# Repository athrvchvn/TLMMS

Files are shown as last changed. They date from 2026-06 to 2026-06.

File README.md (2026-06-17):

# Machine Management System v2

RFID-based access control and machine usage management system for **Tinkerers' Lab, IIT Indore**.

MMS v2 lets lab administrators issue RFID cards to members, restrict machine access by permission level, log every session, and monitor all machines from a web dashboard — all with offline-capable hardware at each machine.

---

## System Overview

Four runtime components work together:

| Component | What it does |
|---|---|
| **ESP32 access node** | Mounted on each machine. Reads RFID cards, controls the relay, logs sessions. |
| **Raspberry Pi bridge** | Runs Mosquitto + `bridge.py`. Connects node MQTT traffic to Firebase. |
| **Card issuing kiosk** | Flask web app + Arduino RFID writer. Issues and encodes member cards. |
| **Web admin dashboard** | React/Vite PWA. Manages users, machines, permissions, and audit logs. |

Firebase stores system state (Firestore + RTDB). MQTT handles local node-to-bridge communication.

---

## Repository Structure

```
├── firmware/
│   ├── access_node/         ESP32 production firmware (Arduino/C++)
│   └── hardware_validation/ Standalone test sketches for each hardware module
│
├── apps/
│   ├── kiosk_station/       Flask card-issuing kiosk + RFID writer firmware
│   └── web_app/             React/Vite/Tailwind admin dashboard
│
├── services/
│   └── rpi_bridge/          Raspberry Pi MQTT↔Firebase bridge (Python)
│
├── firebase/
│   ├── firestore.rules      Firestore security rules
│   ├── firestore.indexes.json  Composite index definitions
│   └── database.rules.json  Realtime Database security rules
│
├── docs/
│   ├── deployment/          Step-by-step deployment and maintenance handbook (17 docs)
│   └── handbook/            LaTeX source for the formal project handbook (v2.1)
│
├── scripts/
│   └── seed_machines.py     Seeds the machine registry into Firestore
│
└── archive/
    ├── v1/                  MMS v1 source, CAD files, docs, and media
    └── handbook_v2.0/       Earlier handbook version (LaTeX source)
```

---

## Quick Start

### Prerequisites

- Firebase project (Firestore + RTDB + Storage + Auth enabled)
- Raspberry Pi 4 or 3B+ with Ethernet
- ESP32 Dev Module per machine
- MFRC522 RFID reader per machine
- Node.js 18+ and Python 3.11+ on your laptop

### Deployment Order

Follow `docs/deployment/` in numbered order. Start here:

```
01 → Read executive overview
03 → Confirm bill of materials
08 → Set up Firebase
07 → Set up Raspberry Pi bridge
09 → Deploy web dashboard
10 → Set up card issuing kiosk
06 → Validate hardware on first node
11 → Flash and provision first ESP32 node
12 → Run integration tests
13 → Roll out to remaining machines
```

Full guide: [docs/deployment/README.md](docs/deployment/README.md)

---

## Component Guide

### `firmware/access_node/`

Production ESP32 firmware. Each machine gets one flashed node.

Key files:

| File | Purpose |
|---|---|
| `access_node.ino` | Main sketch entry point |
| `config.h` | Machine ID, name, pin assignments — edit per node |
| `secrets.h.template` | Copy to `secrets.h` and fill in WiFi/MQTT/master key |
| `state_machine.*` | Node state transitions |
| `rfid_handler.*` | Card read and CRYPTO1 validation |
| `relay_controller.*` | Machine power relay control |
| `session_manager.*` | Session lifecycle (start, extend, end) |
| `mqtt_client.*` | MQTT pub/sub layer |
| `revocation_cache.*` | Local cache of revoked cards (offline-safe) |
| `littlefs_logger.*` | On-device log storage |
| `ota_handler.*` | Over-the-air firmware update support |

**Setup:** copy `secrets.h.template` → `secrets.h`, fill in values. The real `secrets.h` is gitignored and must never be committed.

### `firmware/hardware_validation/`

12 standalone Arduino sketches — one per hardware module. Run these in order on every freshly assembled node before flashing production firmware.

```
01_esp32_system    02_mfrc522        03_hc89_slot_sensor
04_oled64_spi      05_oled32_i2c     06_relay_mechanical
07_relay_ssr       08_ws2812_led     09_rotary_encoder
10_wifi            11_mqtt           12_littlefs
```

See [firmware/hardware_validation/EXECUTION_PLAN.md](firmware/hardware_validation/EXECUTION_PLAN.md) for the sign-off checklist.

### `services/rpi_bridge/`

Python service on the Raspberry Pi. Bridges local MQTT from ESP32 nodes to Firebase (Firestore sessions, RTDB machine status, command delivery).

```sh
cd services/rpi_bridge
cp .env.template .env          # fill in Firebase project ID, MQTT creds
pip install -r requirements.txt
python bridge.py
# or install as a systemd service via mms-bridge.service
```

### `apps/kiosk_station/`

Flask web app for issuing RFID cards at the lab front desk. Talks to Firebase to look up members and write CRYPTO1-encoded card payloads via a connected RFID writer.

```sh
cd apps/kiosk_station
cp secrets.py.template secrets.py   # fill in master key
pip install -r requirements.txt
python app.py
```

The `station_writer/` subfolder contains Arduino firmware for the RFID writer attached to the kiosk PC.

**The master key in `kiosk_station/secrets.py` must exactly match the one in every `access_node/secrets.h`. A mismatch means issued cards will not validate on nodes.**

### `apps/web_app/`

React/Vite admin dashboard. Supports user management, machine management, permission grants, session audit logs, and real-time status monitoring. Built as a PWA.

```sh
cd apps/web_app
npm install
npm run dev       # development server
npm run build     # production build → dist/
```

### `firebase/`

Firebase security rules and index definitions. Deploy from the repo root:

```sh
firebase deploy --only firestore:rules
firebase deploy --only firestore:indexes
firebase deploy --only database
```

### `docs/deployment/`

Complete operational runbook — 17 documents covering every deployment step from hardware assembly to disaster recovery. Written for a junior engineer with no prior MMS experience.

### `scripts/`

```sh
python scripts/seed_machines.py    # populate Firestore machines collection
```

---

## Secrets Reference

Never commit real secrets. Use the provided templates:

| Template | Copy to | Who reads it |
|---|---|---|
| `firmware/access_node/secrets.h.template` | `firmware/access_node/secrets.h` | ESP32 nodes |
| `apps/kiosk_station/secrets.py.template` | `apps/kiosk_station/secrets.py` | Kiosk app |
| `apps/kiosk_station/station_writer/secrets_station.h.template` | `…/secrets_station.h` | RFID writer firmware |
| `services/rpi_bridge/.env.template` | `services/rpi_bridge/.env` | Bridge service |

All three locations that use the master key must have **identical** values:
1. `firmware/access_node/secrets.h` — `MASTER_KEY`
2. `apps/kiosk_station/secrets.py` — `MASTER_KEY`
3. `apps/kiosk_station/station_writer/secrets_station.h` — `MASTER_KEY`

Pre-push checklist:

```sh
git status
git ls-files | grep -E 'secrets|service-account|\.env$'
```

---

## Archive

`archive/v1/` — MMS v1 access node code, kiosk app, CAD enclosure files, and media. Historical reference only; do not develop here.

`archive/handbook_v2.0/` — Earlier LaTeX handbook source.

---

## Tech Stack

| Layer | Technology |
|---|---|
| Node firmware | Arduino/C++ on ESP32 |
| RFID protocol | MFRC522 with MIFARE CRYPTO1 |
| Local messaging | MQTT (Mosquitto on Raspberry Pi) |
| Bridge service | Python 3, paho-mqtt, firebase-admin |
| Cloud backend | Firebase (Firestore, RTDB, Auth, Storage) |
| Web dashboard | React 18, Vite, TypeScript, Tailwind CSS, shadcn/ui |
| Card kiosk | Flask, Python |

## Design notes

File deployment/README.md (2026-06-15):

# MMS V2 — Deployment Package Index

**Machine Management System Version 2**
Tinkerers' Lab, IIT Indore

---

## Who This Package Is For

This package is written for a junior engineer who has never seen MMS before. You need:
- Basic Arduino IDE experience (upload a sketch, open Serial Monitor)
- Basic Raspberry Pi Linux experience (SSH, install packages, edit files)
- Basic web development experience (edit `.env` files, run `npm` commands)

You do **not** need to understand the full codebase. Each handbook is self-contained.

---

## Document Map

| # | Document | When You Need It |
|---|---|---|
| [01](01_executive_overview.md) | Executive Overview | Before anything — read first |
| [02](02_system_architecture.md) | System Architecture | When you need to understand how pieces connect |
| [03](03_bill_of_materials.md) | Bill of Materials | Before ordering hardware |
| [04](04_machine_registry.md) | Machine Registry | Before flashing any node |
| [05](05_hardware_assembly.md) | Hardware Assembly | Before validating hardware |
| [06](06_hardware_validation.md) | Hardware Validation | After assembly, before integration |
| [07](07_raspberry_pi_deployment.md) | Raspberry Pi Deployment | Setting up the RPi bridge |
| [08](08_firebase_deployment.md) | Firebase Deployment | Setting up cloud backend |
| [09](09_web_application_deployment.md) | Web Application Deployment | Deploying the admin dashboard |
| [10](10_card_issuing_station.md) | Card Issuing Station | Setting up the kiosk |
| [11](11_access_node_provisioning.md) | Access Node Provisioning | Flashing and configuring each ESP32 node |
| [12](12_integration_testing.md) | Integration Testing | Verifying everything works together |
| [13](13_production_rollout.md) | Production Rollout Plan | Staged deployment to all machines |
| [14](14_maintenance_handbook.md) | Maintenance Handbook | Ongoing operation |
| [15](15_troubleshooting_guide.md) | Troubleshooting Guide | When something breaks |
| [16](16_disaster_recovery.md) | Disaster Recovery | When something fails catastrophically |
| [17](17_future_expansion.md) | Future Expansion | Adding machines, features |

---

## First-Time Deployment Order

Follow this order exactly. Do not skip steps.

```
Step 1  Read Executive Overview (01)
Step 2  Confirm BOM and procure hardware (03)
Step 3  Set machine registry (04)
Step 4  Set up Firebase (08) ← requires Google account
Step 5  Set up Raspberry Pi (07)
Step 6  Deploy web application (09)
Step 7  Set up card issuing station (10)
Step 8  Assemble first node hardware (05)
Step 9  Validate first node hardware (06)
Step 10 Provision first node (11)
Step 11 Run integration test on first node (12)
Step 12 Pilot deployment — 1 machine (13)
Step 13 Expand to 5 machines (13)
Step 14 Full rollout — 15 machines (13)
```

---

## Critical Files In The Repository

```
v2/
├── access_node/            ← ESP32 firmware source
│   ├── config.h            ← Machine ID, name, pin assignments (edit per node)
│   ├── secrets.h           ← WiFi, MQTT, master key (NEVER commit, gitignored)
│   └── secrets.h.template  ← Copy this to secrets.h and fill in values
├── rpi_bridge/
│   ├── bridge.py           ← Main bridge service
│   ├── .env.template       ← Copy to .env and fill in values
│   └── mms-bridge.service  ← systemd unit file
├── kiosk_station/
│   ├── app.py              ← Flask kiosk application
│   ├── secrets.py          ← Master key (NEVER commit, gitignored)
│   ├── secrets.py.template ← Copy this to secrets.py
│   └── station_writer/     ← Arduino firmware for RFID writer
├── scripts/
│   └── seed_machines.py    ← One-time Firestore population
├── firestore.rules         ← Firestore security rules
├── database.rules.json     ← RTDB security rules
├── firestore.indexes.json  ← Required composite indexes
└── web_app/                ← React admin dashboard
```

---

## Quick Reference — Secrets Locations

| Secret | File | Who Uses It |
|---|---|---|
| WiFi SSID/Password | `access_node/secrets.h` | Each ESP32 node |
| MQTT credentials | `access_node/secrets.h` | Each ESP32 node |
| 32-byte master key | `access_node/secrets.h` | Each ESP32 node |
| 32-byte master key | `kiosk_station/secrets.py` | Python kiosk app |
| 32-byte master key | `kiosk_station/station_writer/secrets_station.h` | Card writer firmware |
| Firebase service account | `rpi_bridge/service-account.json` | Bridge |
| Firebase env vars | `web_app/lab-access-nexus-main/.env` | Web app |

**The master key must be identical in all three locations. A mismatch means cards issued by the kiosk cannot be read by the nodes.**

---

## Emergency Contacts / Escalation

> Fill in before deployment:
> - Lead engineer: ___________________
> - Firebase project ID: ___________________
> - RPi static IP: ___________________
> - WiFi SSID: ___________________

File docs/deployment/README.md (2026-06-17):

# MMS V2 — Deployment Package Index

**Machine Management System Version 2**
Tinkerers' Lab, IIT Indore

---

## Who This Package Is For

This package is written for a junior engineer who has never seen MMS before. You need:
- Basic Arduino IDE experience (upload a sketch, open Serial Monitor)
- Basic Raspberry Pi Linux experience (SSH, install packages, edit files)
- Basic web development experience (edit `.env` files, run `npm` commands)

You do **not** need to understand the full codebase. Each handbook is self-contained.

---

## Document Map

| # | Document | When You Need It |
|---|---|---|
| [01](01_executive_overview.md) | Executive Overview | Before anything — read first |
| [02](02_system_architecture.md) | System Architecture | When you need to understand how pieces connect |
| [03](03_bill_of_materials.md) | Bill of Materials | Before ordering hardware |
| [04](04_machine_registry.md) | Machine Registry | Before flashing any node |
| [05](05_hardware_assembly.md) | Hardware Assembly | Before validating hardware |
| [06](06_hardware_validation.md) | Hardware Validation | After assembly, before integration |
| [07](07_raspberry_pi_deployment.md) | Raspberry Pi Deployment | Setting up the RPi bridge |
| [08](08_firebase_deployment.md) | Firebase Deployment | Setting up cloud backend |
| [09](09_web_application_deployment.md) | Web Application Deployment | Deploying the admin dashboard |
| [10](10_card_issuing_station.md) | Card Issuing Station | Setting up the kiosk |
| [11](11_access_node_provisioning.md) | Access Node Provisioning | Flashing and configuring each ESP32 node |
| [12](12_integration_testing.md) | Integration Testing | Verifying everything works together |
| [13](13_production_rollout.md) | Production Rollout Plan | Staged deployment to all machines |
| [14](14_maintenance_handbook.md) | Maintenance Handbook | Ongoing operation |
| [15](15_troubleshooting_guide.md) | Troubleshooting Guide | When something breaks |
| [16](16_disaster_recovery.md) | Disaster Recovery | When something fails catastrophically |
| [17](17_future_expansion.md) | Future Expansion | Adding machines, features |

---

## First-Time Deployment Order

Follow this order exactly. Do not skip steps.

```
Step 1  Read Executive Overview (01)
Step 2  Confirm BOM and procure hardware (03)
Step 3  Set machine registry (04)
Step 4  Set up Firebase (08) ← requires Google account
Step 5  Set up Raspberry Pi (07)
Step 6  Deploy web application (09)
Step 7  Set up card issuing station (10)
Step 8  Assemble first node hardware (05)
Step 9  Validate first node hardware (06)
Step 10 Provision first node (11)
Step 11 Run integration test on first node (12)
Step 12 Pilot deployment — 1 machine (13)
Step 13 Expand to 5 machines (13)
Step 14 Full rollout — 15 machines (13)
```

---

## Critical Files In The Repository

```
firmware/
├── access_node/            ← ESP32 firmware source
│   ├── config.h            ← Machine ID, name, pin assignments (edit per node)
│   ├── secrets.h           ← WiFi, MQTT, master key (NEVER commit, gitignored)
│   └── secrets.h.template  ← Copy this to secrets.h and fill in values
└── hardware_validation/    ← Standalone test sketches (run before provisioning)

services/
└── rpi_bridge/
    ├── bridge.py           ← Main bridge service
    ├── .env.template       ← Copy to .env and fill in values
    └── mms-bridge.service  ← systemd unit file

apps/
├── kiosk_station/
│   ├── app.py              ← Flask kiosk application
│   ├── secrets.py          ← Master key (NEVER commit, gitignored)
│   ├── secrets.py.template ← Copy this to secrets.py
│   └── station_writer/     ← Arduino firmware for RFID writer
└── web_app/                ← React admin dashboard

firebase/
├── firestore.rules         ← Firestore security rules
├── database.rules.json     ← RTDB security rules
└── firestore.indexes.json  ← Required composite indexes

scripts/
└── seed_machines.py        ← One-time Firestore population
```

---

## Quick Reference — Secrets Locations

| Secret | File | Who Uses It |
|---|---|---|
| WiFi SSID/Password | `firmware/access_node/secrets.h` | Each ESP32 node |
| MQTT credentials | `firmware/access_node/secrets.h` | Each ESP32 node |
| 32-byte master key | `firmware/access_node/secrets.h` | Each ESP32 node |
| 32-byte master key | `apps/kiosk_station/secrets.py` | Python kiosk app |
| 32-byte master key | `apps/kiosk_station/station_writer/secrets_station.h` | Card writer firmware |
| Firebase service account | `services/rpi_bridge/service-account.json` | Bridge |
| Firebase env vars | `apps/web_app/.env` | Web app |

**The master key must be identical in all three locations. A mismatch means cards issued by the kiosk cannot be read by the nodes.**

---

## Emergency Contacts / Escalation

> Fill in before deployment:
> - Lead engineer: ___________________
> - Firebase project ID: ___________________
> - RPi static IP: ___________________
> - WiFi SSID: ___________________

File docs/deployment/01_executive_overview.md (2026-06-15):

# Section 01 — Executive Overview

→ Next: [System Architecture](02_system_architecture.md)

---

## What Is MMS V2?

MMS (Machine Management System) Version 2 is an RFID-based access control and session logging system for the Tinkerers' Lab at IIT Indore. It controls which students can use which lab machines, records how long each machine was used and by whom, and allows lab administrators to manage access remotely through a web dashboard.

**In practical terms:** A student walks up to a machine (e.g., the Creality 3D Printer). They insert their RFID card into the slot. The machine reads the card, verifies the student is authorised to use that specific machine, and if authorised, turns on the power relay to the machine. The student uses the machine. When done, they remove the card and the relay switches off. The session is recorded in Firebase and is visible on the admin dashboard.

---

## Why MMS V2 Exists — V1 Failures

V1 was an earlier system that **couldn't worked end-to-end**. The system had systemic issues that prevented deployment:

| V1 Problem | Impact |
|---|---|
|
| PINs stored as plaintext in Firebase | Security vulnerability |
| Non-unique MQTT client IDs | Multiple nodes disconnected each other |
| No watchdog timer | Firmware lockup required manual reset |
| No OTA update mechanism | Every firmware change required physical access |
| Blocking `delay()` calls in main loop | System unresponsive during delays |
| No offline fallback | WiFi outage = system offline |
| No security rules on Firebase | Any device on the internet could read/write all data |

V2 is a ground-up redesign that addresses every V1 failure.

---

## V2 Key Improvements

| Feature | V1 | V2 |
|---|---|---|
| RFID card schema | Block 1+2 (default sector key) | Sector 1, blocks 4+5, HMAC-SHA256 derived key per card |
| Access decision | Network call required | Fully local on ESP32 — works offline |
| Session logging | Never reached Firestore | LittleFS buffer → MQTT → Firebase bridge |
| Offline operation | System offline | Continues granting/denying access; logs buffered |
| Firmware updates | Physical access required | OTA via Firebase Storage URL |
| Watchdog | None | 30-second hardware watchdog timer |
| Security | No Firestore rules; plaintext PINs | Full security rules; HMAC-SHA256 PIN hash |
| Remote control | None | Admin can stop a session or disable a machine from the web |
| Machine configuration | Hardcoded in firmware | Pushed via MQTT retained messages from Firebase |

---

## System Capabilities

### What the system can do
- Grant or deny machine access based on RFID card permissions
- Log session start, end, duration, and reason to Firebase
- Support up to 32 machines (uint32 permission bitmask per card)
- Operate fully offline if WiFi/MQTT is unavailable
- Buffer offline session logs and upload when connectivity restores
- Push firmware updates to all nodes simultaneously (OTA)
- Allow an admin to remotely stop an active session
- Allow an admin to remotely disable a machine (denies all access)
- Revoke a lost or stolen card within seconds of admin action
- Push configuration changes (session limits, machine names) live to nodes
- Show real-time machine status on the admin web dashboard

### What the system cannot do (V2 scope)
- PIN verification at the machine (deferred to Phase 4 — rotary encoder not yet installed)
- Machine reservation/booking
- Multi-lab deployment (each lab needs its own Firebase project)
- 5 GHz WiFi (ESP32 is 2.4 GHz only)

---

## Architecture Summary

```
┌─────────────────────────────────────────────────────────────────┐
│                    RFID CARD (MIFARE Classic 1K)                │
│  Carries: Roll number, permissions bitmask, PIN hash            │
│  Secured by: Per-card HMAC-SHA256 sector key                    │
└───────────────────────────┬─────────────────────────────────────┘
                            │ Physical insertion into slot
                            ▼
┌─────────────────────────────────────────────────────────────────┐
│                  ESP32 ACCESS NODE (per machine)                │
│  Reads card → checks permissions → controls relay               │
│  Logs session to LittleFS → publishes to MQTT                   │
│  Updates two OLEDs + WS2812 LED                                 │
└───────────────────────────┬─────────────────────────────────────┘
                            │ MQTT over LAN (port 1883)
                            ▼
┌─────────────────────────────────────────────────────────────────┐
│               RASPBERRY PI (static IP on lab LAN)              │
│  Runs: Mosquitto MQTT broker + bridge.py service                │
│  Bridge: routes MQTT ↔ Firebase (Firestore + RTDB)             │
└────────────────┬──────────────────────────────────┬────────────┘
                 │ Firebase Admin SDK               │ Admin SDK
                 ▼                                  ▼
┌─────────────────────────┐        ┌────────────────────────────┐
│  FIRESTORE              │        │  REALTIME DATABASE (RTDB)  │
│  /sessions              │        │  /mms/nodes/{id}  (status) │
│  /users                 │        │  /mms/commands/{id}        │
│  /machines              │        │  /mms/ota                  │
│  /revoked               │        │  /mms/revoked              │
└─────────────────────────┘        └────────────────────────────┘
                 │                                  │
                 └──────────────┬───────────────────┘
                                │ Firebase JS SDK
                                ▼
┌─────────────────────────────────────────────────────────────────┐
│               REACT WEB APPLICATION (Firebase Hosting)          │
│  Admin dashboard: real-time status, session logs, user mgmt     │
│  Super admin: OTA trigger, machine enable/disable, revocation  │
└─────────────────────────────────────────────────────────────────┘
```

---

## Deployment Scale Assumptions

This deployment package assumes:
- **10–15 machines** in a single lab
- **~300 users** (students with RFID cards)
- **1 Raspberry Pi** serving as both MQTT broker and Firebase bridge
- **1 WiFi access point** covering the lab (2.4 GHz, SSID: `tlmms`)
- **1 Firebase project** (Spark/Blaze plan — see Section 8 for cost)
- **1 card issuing station** (kiosk) at the lab entrance
- Machines operate in a single physical location — no multi-site deployment

If these assumptions change (e.g., 2 labs, >32 machines, >1 AP), see [Section 17 — Future Expansion](17_future_expansion.md).

---

## Terminology Glossary

| Term | Meaning |
|---|---|
| Access node | The ESP32 + peripherals mounted at each machine |
| Bridge | The Python service on the RPi that connects MQTT to Firebase |
| Card / RFID card | MIFARE Classic 1K card issued to each student |
| Kiosk | The card issuing station (RPi or laptop + MFRC522 + Flask web UI) |
| Machine ID | Integer 1–32 identifying a specific lab machine |
| Master key | 32-byte secret known to kiosk and all nodes; used for HMAC key derivation |
| MQTT | Lightweight message protocol used for LAN communication |
| Node | Short for "access node" |
| OTA | Over-the-air firmware update |
| Permission bitmask | 32-bit integer on the card; bit N-1 = permission for machine N |
| Sector key | 6-byte key derived per-card by HMAC-SHA256(master_key, card_UID) |
| Session | A single machine-use event: card inserted → card removed or timeout |
| RTDB | Firebase Realtime Database |
| Roll number | Student identifier (9-digit string, e.g., "220002123") |

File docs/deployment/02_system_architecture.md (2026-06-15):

# Section 02 — System Architecture

← [Executive Overview](01_executive_overview.md) | → [Bill of Materials](03_bill_of_materials.md)

---

## Overall Architecture

```
╔══════════════════════════════════════════════════════════════════════╗
║                        LAB NETWORK (2.4 GHz WiFi)                    ║
║                                                                      ║
║  ┌──────────┐  ┌──────────┐  ┌──────────┐     ┌──────────┐           ║
║  │ Node 1   │  │ Node 2   │  │ Node 3   │ ... │ Node 15  │           ║
║  │Creality  │  │ Laser    │  │Soldering │     │ Grinder  │           ║
║  └────┬─────┘  └────┬─────┘  └────┬─────┘     └────┬─────┘           ║
║       │              │              │                │               ║
║       └──────────────┴──────────────┴────────────────┘               ║
║                                 │ MQTT port 1883                     ║
║                                 ▼                                    ║
║              ┌─────────────────────────────────────┐                 ║
║              │  Raspberry Pi (192.168.0.10 static) │                 ║
║              │  ├── Mosquitto MQTT broker          │                 ║
║              │  └── bridge.py (systemd service)    │                 ║
║              └───────────────────┬─────────────────┘                 ║
╚══════════════════════════════════╪═══════════════════════════════════╝
                                   │ HTTPS / Firebase Admin SDK
                                   ▼
            ╔══════════════════════════════════════════╗
            ║         FIREBASE (Google Cloud)           ║
            ║  ┌──────────────────────────────────┐    ║
            ║  │ Firestore                         │    ║
            ║  │  /users /machines /sessions       │    ║
            ║  │  /revoked /admins /super_admins   │    ║
            ║  └──────────────────────────────────┘    ║
            ║  ┌──────────────────────────────────┐    ║
            ║  │ Realtime Database (RTDB)          │    ║
            ║  │  /mms/nodes /mms/commands         │    ║
            ║  │  /mms/ota   /mms/revoked          │    ║
            ║  └──────────────────────────────────┘    ║
            ║  ┌──────────────────────────────────┐    ║
            ║  │ Storage (OTA firmware binaries)   │    ║
            ║  └──────────────────────────────────┘    ║
            ╚══════════════════════╦═══════════════════╝
                                   ║ Firebase JS SDK
                                   ▼
            ╔══════════════════════════════════════════╗
            ║     REACT WEB APP (Firebase Hosting)     ║
            ║  Admin dashboard + super admin panel     ║
            ╚══════════════════════════════════════════╝
```

---

## Access Node Architecture

Each physical machine has one access node. The node is self-contained — it can grant or deny access even with no network connection.

```
                     ┌────────────────────────────────────────┐
                     │           ESP32 NodeMCU 38-pin          │
                     │                                        │
  HC89 Slot          │ GPIO 32 ◄── Card present/absent        │
  Sensor ────────────┤                                        │
                     │ GPIO 5  ◄── MFRC522 SS (SPI)          │
  MFRC522            │ GPIO 27 ◄── MFRC522 RST               │
  RFID ──────────────┤ GPIO 18 ◄── SPI SCK (shared)          │
                     │ GPIO 19 ◄── SPI MISO (shared)         │
                     │ GPIO 23 ◄── SPI MOSI (shared)         │
                     │                                        │
  128×64 OLED        │ GPIO 17 ──► OLED DC                   │
  SPI ───────────────┤ GPIO 16 ──► OLED CS                   │
                     │ GPIO 4  ──► OLED RST                   │
                     │ GPIO 18/23 shared with RFID            │
                     │                                        │
  128×32 OLED        │ GPIO 21 ◄► I2C SDA                    │
  I2C ───────────────┤ GPIO 22 ──► I2C SCL                   │
                     │                                        │
  Relay / SSR ───────┤ GPIO 26 ──► Relay IN                  │
                     │                                        │
  WS2812 LED ────────┤ GPIO 33 ──► LED DIN (via 470Ω)        │
                     │                                        │
  Rotary Encoder     │ GPIO 34 ◄── CLK (ext. pull-up)        │
  (Phase 4) ─────────┤ GPIO 35 ◄── DT  (ext. pull-up)        │
                     │ GPIO 25 ◄── SW  (internal pull-up)     │
                     │                                        │
                     │ GPIO 2  ──► Onboard LED (WiFi status)  │
                     └────────────────────────────────────────┘
```

---

## Firmware State Machine

The ESP32 firmware runs a state machine. Understanding this helps diagnose what a node is doing at any moment.

```
                    Power on
                       │
                       ▼
                ┌─────────────┐
                │    BOOT     │ Init hardware, WiFi, MQTT, NVS
                └──────┬──────┘
                       │ Setup complete
                       ▼
              ┌────────────────┐
         ┌────►     IDLE       │◄────────────────────────────────┐
         │    │                │  OLED: "Tap card to start"      │
         │    └───────┬────────┘  LED: white breathing           │
         │            │ HC89: card detected                       │
         │            ▼                                           │
         │    ┌────────────────┐                                  │
         │    │ CARD_READING   │  OLED: spinner                  │
         │    └───────┬────────┘  LED: cyan flash                 │
         │            │                                           │
         │    ┌───────┴────────────────────────────┐             │
         │    │ Read result                        │             │
         │    ▼                                    ▼             │
         │  GRANTED                           DENIED             │
         │    │                          ┌────────────────┐      │
         │    │                          │ ACCESS_DENIED  │──────┘
         │    │                          │ (3s timeout)   │
         │    ▼                          └────────────────┘
         │  ┌─────────────────┐
         │  │ SESSION_ACTIVE  │  Relay ON, OLED: timer
         │  └────────┬────────┘  LED: solid green
         │           │
         │    ┌──────┴──────────────────┐
         │    │                         │
         │ card removed          2 min before limit
         │    │                         │
         │    │              ┌──────────────────────┐
         │    │              │  TIMEOUT_WARNING      │
         │    │              │  LED: yellow↔orange   │
         │    │              └──────────┬────────────┘
         │    │                    limit hit
         │    │                         │
         │    ▼                         ▼
         │  ┌─────────────────────────────────────┐
         │  │         SESSION_ENDED               │  Relay OFF
         │  │  Log event → MQTT → LittleFS        │  LED: off
         │  └───────────────┬─────────────────────┘
         │                  │ 3s
         └──────────────────┘

Any state + MQTT "stop"  → SESSION_ENDED
Any state + MQTT "ota"   → OTA_UPDATE (relay OFF first)
Any state + watchdog     → Hardware reset → BOOT
```

---

## MQTT Communication Architecture

### Topic map

| Topic | Direction | QoS | Retained | Payload |
|---|---|---|---|---|
| `mms/nodes/{id}/status` | Node → RPi | 1 | YES | `{state, roll, session_start, fw_version, ip, rssi}` |
| `mms/nodes/{id}/event` | Node → RPi | 1 | No | `{t, r, m, e, d, er}` |
| `mms/nodes/{id}/heartbeat` | Node → RPi | 0 | No | `{ts, heap_free, uptime_s}` |
| `mms/nodes/{id}/command` | RPi → Node | 1 | No | `{cmd, issued_by, ts}` |
| `mms/nodes/{id}/config` | RPi → Node | 1 | YES | `{name, session_limit_min, relay_active_high, machine_active}` |
| `mms/all/revoked` | RPi → All | 1 | YES | `{uids:["A1B2C3",...], updated_at:ts}` |
| `mms/bridge/status` | RPi → All | 1 | YES | `{state:"online"\|"offline"}` |

**Why retained messages matter:** When an ESP32 reboots and reconnects to MQTT, the broker immediately delivers the last retained `config` and `revoked` messages. The node gets its current configuration and revocation list without waiting for the admin to change anything. This is how offline-then-reconnect works seamlessly.

**Last Will Testament (LWT):** Each node sets a LWT before connecting. If it disconnects unexpectedly, the broker publishes `{"state":"offline"}` to `mms/nodes/{id}/status` (retained). The bridge sees this and the dashboard shows the node as offline.

### MQTT client IDs

Each client must have a unique ID. Duplicate IDs cause disconnection loops.

| Client | ID |
|---|---|
| Bridge | `bridge` |
| Node 1 | `mms_node_1` |
| Node 2 | `mms_node_2` |
| ... | ... |
| Node 15 | `mms_node_15` |

---

## Firebase Architecture

### Why two databases?

Firebase provides two real-time database products:
- **Firestore**: Document database optimised for complex queries, offline sync, and history. Used for permanent records (sessions, users, machines).
- **RTDB (Realtime Database)**: Simple JSON tree optimised for ultra-low latency live data. Used for real-time machine states, commands, and OTA triggers.

### Data flow: session event

```
ESP32 card removed
  → Session::end() called
  → Logger::appendSessionEnd() → /logs/sessions.jsonl (LittleFS)
  → MqttClient::publishEvent() → mms/nodes/3/event (MQTT QoS 1)
  → Bridge on_message() receives it
  → bridge.handle_node_event()
      → deduplication check (prevents duplicate on power-failure replay)
      → _fs_client.collection("sessions").add(session_data)   ← Firestore
      → _fs_client.collection("users").document(roll).update(last_seen)
  → Web app onSnapshot() triggers → dashboard updates
```

### Data flow: remote stop command

```
Admin clicks "Stop" in web app
  → setDoc(doc(rtdb, "/mms/commands/3"), {command:"stop", ts:now})
  → Bridge setup_rtdb_command_listener() fires
  → bridge checks: not stale (< 5 min), not acknowledged
  → mqtt_publish("mms/nodes/3/command", {cmd:"stop", ts:now}) QoS 1
  → Node MQTT callback receives it
  → processPendingCommand() in state_machine.cpp
  → Relay::off() → session ended → event published → RTDB cleared
```

### Data flow: OTA update

```
Super admin writes {firmware_url, target_version} to RTDB /mms/ota
  → Bridge setup_rtdb_ota_listener() fires
  → For each machine in Firestore /machines:
      → mqtt_publish("mms/nodes/{id}/command", {cmd:"ota", url, version})
  → Each node receives "ota" command
  → OTA::applyUpdate(url, version) called
  → esp_https_ota() downloads from Firebase Storage URL
  → On success: update NVS fw_version, ESP.restart()
  → If firmware crashes 3x on boot: rollback to previous partition
```

### Data flow: card revocation

```
Admin marks card as lost/stolen in web app
  → createDoc(doc(db, "revoked", uid), {reason:"lost"})
  → Bridge setup_firestore_revocation_listener() fires
  → Rebuild uid list from all /revoked docs
  → mqtt_publish("mms/all/revoked", {uids:[...], updated_at:ts}) retained
  → All connected nodes receive update → LittleFS /config/revoked.json updated
  → Next card tap with that UID: check → denied
```

---

## Access Control Architecture

The access decision is made entirely on the ESP32. No network call is needed.

```
Card inserted into slot
  ↓
HC89 slot sensor detects (GPIO 32 goes LOW)
  ↓
MFRC522 reads UID (SPI)
  ↓
Derive sector key:
  sector_key = HMAC-SHA256(master_key, uid_hex_uppercase)[0:6]
  (master_key is 32 bytes stored in NVS, never changes per deployment)
  ↓
Authenticate Sector 1, Block 7 with sector_key (MFRC522 MIFARE_Auth)
  ↓ (fails if card is from another system or was issued with wrong master key)
Read Block 4: roll_number[0:8] + schema_version[9]
Read Block 5: pin_hash[0:7] + perm_mask[8:11]
  ↓
Check 1: schema_version == 0x02 ?
  No → ACCESS DENIED ("Old card format")
  ↓
Check 2: uid in revocation list? (scan LittleFS /config/revoked.json)
  Yes → ACCESS DENIED ("Card revoked")
  ↓
Check 3: (perm_mask >> (MACHINE_ID - 1)) & 1 == 1 ?
  No → ACCESS DENIED ("No permission")
  ↓
Check 4: NVS::getMachineActive() == true ?
  No → ACCESS DENIED ("Machine disabled")
  ↓
ACCESS GRANTED → Relay::on()
```

**Key point:** This entire process takes ~200ms and requires zero network access. The node can grant access even if WiFi is completely down.

---

## Offline Operation Architecture

The system degrades gracefully during network failures:

```
WiFi or MQTT down
  ├── Access decisions: UNCHANGED (still fully functional)
  ├── Session logging: written to LittleFS /logs/sessions.jsonl
  ├── Revocation updates: cannot receive new revocations
  │     (last known list still enforced)
  ├── Config updates: cannot receive new session limits
  │     (NVS cached values used)
  └── Status display: 128×32 OLED shows "OFFLINE" indicator

WiFi or MQTT restored
  ├── LittleFS logger flushes buffered events to MQTT (QoS 1)
  ├── Broker delivers retained config + revoked messages
  ├── Node resumes publishing status + heartbeats
  └── Bridge processes buffered events into Firestore
```

**Offline capacity:** At 120 sessions/day average, LittleFS (1.5MB partition) holds approximately **5,000 session records** before rotation. Practically unlimited offline resilience for a lab.

---

## NVS (Non-Volatile Storage) Architecture

The ESP32 stores its configuration in NVS flash (survives reboots and power loss):

| NVS Key | Type | Set By | Description |
|---|---|---|---|
| `machine_id` | uint8 | Provisioning (config.h) | 1–32; fixed per node |
| `master_key` | blob 32B | Provisioning (secrets.h) | Shared secret for key derivation |
| `machine_name` | string | MQTT config push | Human-readable name |
| `session_limit` | uint16 | MQTT config push | Minutes; fallback to config.h |
| `relay_active_high` | uint8 | MQTT config push | Relay polarity |
| `machine_active` | uint8 | MQTT config push | 0 = admin-disabled |
| `fw_version` | string | OTA handler | Current firmware version |

Config pushed via MQTT is stored in NVS immediately, so it persists across reboots even if the node comes back up while the RPi is offline.

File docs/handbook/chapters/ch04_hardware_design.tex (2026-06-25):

%% Chapter 4 — Hardware Design
\chapter{Hardware Design}
\label{ch:hardware}

\section{ESP32 NodeMCU 38-pin}

The ESP32 NodeMCU (38-pin variant) is the central controller for each access node. Key specifications relevant to MMS V2:

\begin{itemize}[leftmargin=1.5em]
    \item Dual-core Xtensa LX6 at up to 240 MHz
    \item 520 KB SRAM; 4 MB flash
    \item Built-in 802.11 b/g/n WiFi (2.4 GHz only)
    \item 34 programmable GPIOs; some input-only
    \item Hardware SPI, I2C, UART peripherals
    \item \texttt{mbedTLS} cryptography library in ROM (provides HMAC-SHA256 without adding flash)
    \item Dual OTA flash partitions; watchdog timer
    \item 3.3V operating voltage; 5V tolerant on Vin pin
\end{itemize}

\begin{warnbox}
\textbf{GPIO 34--39 are INPUT ONLY.} They cannot be driven as outputs and have no internal pull-up resistors. In V1, the MFRC522 RST pin was connected to GPIO 34, which cannot be driven LOW --- the reset never worked. V2 moves RST to GPIO 27. The rotary encoder CLK (GPIO 34) and DT (GPIO 35) are correctly used as inputs with external 10k$\Omega$ pull-up resistors to 3.3V.
\end{warnbox}

\section{GPIO Pin Assignments}

\begin{table}[H]
\centering
\caption{ESP32 GPIO Assignments for MMS V2 Access Node}
\label{tab:gpio}
\begin{tabular}{C{2cm}L{4cm}C{2.5cm}L{2.5cm}L{3cm}}
\toprule
\textbf{GPIO} & \textbf{Signal} & \textbf{Direction} & \textbf{Pull resistor} & \textbf{Notes} \\
\midrule
5  & MFRC522 SS (SDA) & OUT & None & SPI chip select \\
18 & SPI SCK           & OUT & None & Shared: RFID + OLED64 \\
19 & SPI MISO          & IN  & None & Shared: RFID + OLED64 \\
23 & SPI MOSI          & OUT & None & Shared: RFID + OLED64 \\
27 & MFRC522 RST       & OUT & None & Active LOW reset \\
17 & OLED64 DC         & OUT & None & Data/Command select \\
16 & OLED64 CS         & OUT & None & SPI chip select \\
4  & OLED64 RST        & OUT & None & Active LOW reset \\
21 & OLED32 SDA        & BIDIR & Module 4.7k$\Omega$ & I2C data \\
22 & OLED32 SCL        & OUT & Module 4.7k$\Omega$ & I2C clock \\
26 & Relay IN          & OUT & None & LOW before \texttt{pinMode} \\
32 & HC89 slot sensor  & IN  & INPUT\_PULLUP & LOW = card present \\
33 & WS2812 DIN        & OUT & None & Via 470$\Omega$ resistor \\
36 & Current sensor IN & IN  & None & ADC1 CH0 (SVP); input-only; analog \\
34 & Encoder CLK       & IN  & EXT 10k$\Omega$ to 3V3 & Input-only; no internal pull-up \\
35 & Encoder DT        & IN  & EXT 10k$\Omega$ to 3V3 & Input-only; no internal pull-up \\
25 & Encoder SW        & IN  & INPUT\_PULLUP & Button press \\
2  & Onboard LED       & OUT & None & WiFi status indicator \\
\bottomrule
\end{tabular}
\end{table}

\section{Component Details}

\subsection{MFRC522 RFID Reader}

The MFRC522 is a 13.56 MHz RFID reader module compatible with MIFARE cards. In MMS V2 it is connected via SPI.

\begin{itemize}[leftmargin=1.5em]
    \item \textbf{Supply voltage}: 3.3V (NOT 5V --- module is not 5V tolerant)
    \item \textbf{SPI speed}: up to 10 MHz; MMS firmware uses 4 MHz for stability
    \item \textbf{Pin labelling}: the ``SDA'' pin on the module is the SPI chip select (SS), not I2C SDA --- this is a common source of confusion
    \item \textbf{IRQ pin}: not used in MMS V2; leave unconnected (NC)
    \item \textbf{Card detection}: firmware polls \texttt{MFRC522::PICC\_IsNewCardPresent()} rather than using the IRQ line
\end{itemize}

\subsection{SSD1306 128$\times$64 SPI OLED (Primary Display)}

This is the main user-facing display. It shows machine state, roll number, session timer, and status messages.

\begin{itemize}[leftmargin=1.5em]
    \item Controller: SSD1306
    \item Resolution: 128$\times$64 pixels, monochrome
    \item Interface: SPI (4-wire: SCK, MOSI, DC, CS) plus RST
    \item Supply: 3.3V
    \item Shared SPI bus with MFRC522; multiplexed via chip select pins
\end{itemize}

\subsection{SSD1306 128$\times$32 I2C OLED (Status Strip)}

This is the always-visible status display: WiFi/MQTT connectivity dots, machine name, NTP time.

\begin{itemize}[leftmargin=1.5em]
    \item Controller: SSD1306
    \item Resolution: 128$\times$32 pixels, monochrome
    \item Interface: I2C, address 0x3C
    \item Supply: 3.3V
    \item Module has onboard 4.7k$\Omega$ pull-ups on SDA and SCL --- no external resistors needed
\end{itemize}

\subsection{HC89 Optical IR Slot Sensor}

The HC89 is an infrared photointerrupter slot sensor that detects card insertion.

\begin{itemize}[leftmargin=1.5em]
    \item Slot width: \textasciitilde{}6mm (MIFARE card thickness: 0.76mm --- fits well)
    \item Output type: open-collector (active LOW when card blocks IR beam)
    \item Supply: 3.3V or 5V (check module datasheet --- most accept 3.3V)
    \item Configured as \texttt{INPUT\_PULLUP} on GPIO 32
    \item Firmware debounce: 50ms (ignores transitions shorter than 50ms)
    \item A card in the slot gives signal LOW; no card gives signal HIGH
\end{itemize}

\subsection{Relay Module (Mechanical or SSR)}

\subsubsection{Mechanical Relay}
\begin{itemize}[leftmargin=1.5em]
    \item Typical: SRD-05VDC-SL-C (5V coil, 10A 250V AC rated)
    \item Control: GPIO 26 via optocoupler on relay board
    \item Default active HIGH (\texttt{relay\_active\_high = true} in config)
    \item Relay board takes 5V on VCC; control signal from 3.3V GPIO is sufficient via optocoupler
\end{itemize}

\subsubsection{Solid-State Relay (SSR)}
Recommended for high-cycling loads (soldering station on/off frequently) and for the laser cutter (noise sensitivity).

\begin{itemize}[leftmargin=1.5em]
    \item Typical: SSR-25DA (3--32V DC control, 25A 380V AC load)
    \item Control: GPIO 26 (3.3V signal drives 3--32V DC input directly)
    \item Active HIGH (\texttt{relay\_active\_high = true})
    \item Heat sink required for loads above 10A
\end{itemize}

\begin{notebox}
The \texttt{relay\_active\_high} configuration is pushed from Firebase via MQTT to each node's NVS. This means the relay polarity can be changed remotely without reflashing. Set this value correctly in the Firestore \texttt{/machines/\{id\}} document when seeding.
\end{notebox}

\subsection{WS2812B RGB LED}

A single WS2812B LED provides colour-coded system state feedback.

\begin{itemize}[leftmargin=1.5em]
    \item Supply: 5V (directly from Vin --- NOT 3.3V)
    \item Data: GPIO 33 via 470$\Omega$ series resistor (protects against inductive spikes from long wire runs)
    \item 100$\mu$F electrolytic capacitor across VCC--GND at the LED (absorbs power-up surge)
    \item Colour order: \texttt{NEO\_GRB} (some clone modules use different order --- see Appendix~\ref{app:wiring})
\end{itemize}

\subsection{EC11 Rotary Encoder}

The EC11 rotary encoder is installed in the hardware but not yet used in production firmware (Phase 4 --- PIN entry at machine).

\begin{itemize}[leftmargin=1.5em]
    \item CLK on GPIO 34 (input-only) --- requires external 10k$\Omega$ pull-up to 3.3V
    \item DT on GPIO 35 (input-only) --- requires external 10k$\Omega$ pull-up to 3.3V
    \item SW (push button) on GPIO 25 --- uses internal \texttt{INPUT\_PULLUP}
\end{itemize}

\subsection{Power Supply}

Each node uses a HiLink HLK-PM01 (5V 1W AC-DC converter) to derive 5V from mains:

\begin{itemize}[leftmargin=1.5em]
    \item Input: 90--264V AC
    \item Output: 5V DC, 600mA
    \item The 5V feeds: ESP32 Vin, relay module VCC, WS2812 VCC
    \item The ESP32's internal LDO produces 3.3V for all other components
    \item A 5A fuse must be placed on the AC input before the HiLink
\end{itemize}

\begin{warnbox}
\textbf{Safety:} The HiLink operates at 240V AC. Treat it as a live shock hazard at all times. All AC wiring must be completed, routed through cable glands, and the enclosure must be closed before the node is powered from mains. Always test 5V DC circuitry with a USB power bank before connecting to mains.
\end{warnbox}

\section{Power Budget}

\begin{table}[H]
\centering
\caption{Node Power Consumption Estimate}
\begin{tabular}{L{5cm}C{3cm}C{3cm}}
\toprule
\textbf{Component} & \textbf{Typical (mA)} & \textbf{Peak (mA)} \\
\midrule
ESP32 (WiFi active, 240MHz) & 160 & 250 \\
MFRC522 & 13 & 26 \\
SSD1306 64px OLED & 20 & 25 \\
SSD1306 32px OLED & 15 & 20 \\
HC89 & 20 & 20 \\
WS2812B (1 LED, white full) & 60 & 60 \\
Relay coil (mechanical) & 70 & 70 \\
\midrule
\textbf{Total (peak)} & & \textbf{471 mA} \\
\midrule
HiLink HLK-PM01 capacity & & 600 mA \\
Margin & & 127 mA (21\%) \\
\bottomrule
\end{tabular}
\end{table}

\begin{notebox}
The power margin is adequate but not generous. Avoid adding components to the 5V rail beyond the designed BOM. If an SSR is added (replacing mechanical relay), remove the relay coil consumption --- SSRs consume \textasciitilde{}10mA on the control side.
\end{notebox}

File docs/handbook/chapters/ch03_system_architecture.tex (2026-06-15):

%% Chapter 3 — System Architecture
\chapter{System Architecture}
\label{ch:architecture}

\section{Architecture Overview}

MMS V2 uses a three-tier architecture:

\begin{enumerate}[leftmargin=1.5em]
    \item \textbf{Edge tier}: ESP32 access nodes. One per machine. Physical access control, session timing, display.
    \item \textbf{Local bridge tier}: Raspberry Pi running Mosquitto (MQTT broker) and \texttt{bridge.py}. Bridges the local MQTT network and Firebase.
    \item \textbf{Cloud tier}: Firebase (Firestore + RTDB + Storage + Hosting + Auth). Permanent storage, real-time state, web hosting.
\end{enumerate}

\begin{figure}[H]
\centering
\begin{tikzpicture}[node distance=11mm and 11mm]
\node[mmsedge] (n1) {ESP32 Node 1\\3D Printer};
\node[mmsedge, right=of n1] (n2) {ESP32 Node 2\\Laser Cutter};
\node[mmsedge, right=of n2] (n3) {ESP32 Node 3--5\\Soldering, Grinder};
\node[mmsblock, above=16mm of n2, text width=42mm] (rpi) {Raspberry Pi\\Mosquitto broker\\\texttt{bridge.py} systemd\\192.168.0.10};
\node[mmscloud, above=16mm of rpi, text width=48mm] (fb) {Firebase\\Firestore + RTDB\\Storage + Hosting + Auth};
\node[mmsblock, right=20mm of fb] (web) {React dashboard\\coordinators};
\node[mmsblock, left=20mm of rpi] (kiosk) {Kiosk station\\card issuer};
\draw[mmsline] (n1) -- node[left,font=\scriptsize]{MQTT/LAN} (rpi);
\draw[mmsline] (n2) -- (rpi);
\draw[mmsline] (n3) -- (rpi);
\draw[mmsline] (rpi) -- node[right,font=\scriptsize]{Admin SDK + REST} (fb);
\draw[mmsline] (web) -- node[above,font=\scriptsize]{HTTPS} (fb);
\draw[mmsdash] (kiosk) -- node[above,font=\scriptsize]{Firestore user data} (fb);
\draw[mmsdash] (kiosk) -- node[below,font=\scriptsize]{writes cards} (n1);
\end{tikzpicture}
\caption{MMS V2 System Architecture}
\label{fig:architecture}
\end{figure}

\section{C4-Style System Context}

\begin{figure}[H]
\centering
\begin{tikzpicture}[node distance=12mm and 15mm]
\node[mmsblock] (student) {Student\\RFID card};
\node[mmsblock, below=of student] (coord) {Coordinator\\dashboard};
\node[mmscloud, right=18mm of student, text width=43mm] (system) {MMS V2\\access control and usage logging};
\node[mmsedge, right=18mm of system] (machine) {Workshop machines\\relay controlled};
\node[mmscloud, below=of system] (firebase) {Firebase project\\identity, live state, records};
\draw[mmsline] (student) -- node[above,font=\scriptsize]{requests access} (system);
\draw[mmsline] (coord) -- node[below,font=\scriptsize]{admin commands} (system);
\draw[mmsline] (system) -- node[above,font=\scriptsize]{enables power} (machine);
\draw[mmsline] (system) -- node[right,font=\scriptsize]{logs/syncs} (firebase);
\draw[mmsline] (firebase) -- (coord);
\end{tikzpicture}
\caption{System context diagram}
\label{fig:system_context}
\end{figure}

\section{Communication Paths}

\subsection{Access Decision (Offline-capable)}

The access decision path requires no network:
\begin{enumerate}[leftmargin=1.5em]
    \item HC89 slot sensor detects card insertion
    \item MFRC522 reads card UID
    \item ESP32 derives sector key: $\text{HMAC-SHA256}(\text{master\_key},\, \text{uid\_hex})[0..5]$
    \item ESP32 authenticates Sector 1, reads Blocks 4 and 5
    \item ESP32 checks UID against LittleFS revocation list
    \item ESP32 checks permission bitmask: $(perm\_mask \gg (machine\_id - 1)) \& 1$
    \item If all checks pass: relay ON, session starts
\end{enumerate}

\begin{figure}[H]
\centering
\begin{tikzpicture}[node distance=8mm]
\node[state] (slot) {Card inserted};
\node[state, below=of slot] (read) {Read UID and Sector 1};
\node[decision, below=of read] (auth) {Auth\\OK?};
\node[decision, below left=11mm and 18mm of auth] (rev) {UID\\revoked?};
\node[decision, below right=11mm and 18mm of auth] (perm) {Permission\\bit set?};
\node[mmswarn, below=18mm of rev] (deny) {Deny access\\log reason};
\node[mmsedge, below=18mm of perm] (grant) {Relay ON\\start session};
\draw[mmsline] (slot) -- (read);
\draw[mmsline] (read) -- (auth);
\draw[mmsline] (auth) -- node[left,font=\scriptsize]{yes} (rev);
\draw[mmsline] (auth) -- node[right,font=\scriptsize]{yes} (perm);
\draw[mmsline] (auth.east) -- ++(18mm,0) |- node[pos=0.2,above,font=\scriptsize]{no} (deny.east);
\draw[mmsline] (rev) -- node[left,font=\scriptsize]{yes} (deny);
\draw[mmsline] (rev) -- node[above,font=\scriptsize]{no} (perm);
\draw[mmsline] (perm) -- node[right,font=\scriptsize]{yes} (grant);
\draw[mmsline] (perm) -- node[above,font=\scriptsize]{no} (deny);
\end{tikzpicture}
\caption{Offline access validation flow}
\label{fig:access_validation_flow}
\end{figure}

\subsection{Session Event Flow}

\begin{enumerate}[leftmargin=1.5em]
    \item Session ends (card removed, timeout, or remote stop)
    \item ESP32 builds JSON event: \texttt{\{ts, roll, machine\_id, event, duration\_s, end\_reason\}}
    \item If MQTT connected: publish to \texttt{mms/nodes/\{id\}/event} (QoS 1)
    \item If MQTT disconnected: append to LittleFS \texttt{/logs/sessions.jsonl}; publish on next connect
    \item bridge.py receives event via MQTT subscription
    \item bridge.py checks Firestore for duplicate (±5s deduplication window)
    \item bridge.py writes session to Firestore \texttt{/sessions} collection
    \item bridge.py updates \texttt{/users/\{roll\}/last\_seen}
\end{enumerate}

\begin{figure}[H]
\centering
\begin{tikzpicture}[node distance=8mm and 12mm]
\node[mmsedge] (esp) {ESP32\\session ends};
\node[mmsblock, right=of esp] (mqtt) {MQTT broker\\QoS 1};
\node[mmsblock, right=of mqtt] (bridge) {bridge.py\\deduplicate};
\node[mmscloud, right=of bridge] (fs) {Firestore\\\texttt{/sessions}};
\node[mmswarn, below=of mqtt] (fsbuf) {LittleFS\\offline buffer};
\draw[mmsline] (esp) -- node[above,font=\scriptsize]{online} (mqtt);
\draw[mmsline] (mqtt) -- (bridge);
\draw[mmsline] (bridge) -- (fs);
\draw[mmsdash] (esp) -- node[left,font=\scriptsize]{offline} (fsbuf);
\draw[mmsdash] (fsbuf) -- node[right,font=\scriptsize]{flush on reconnect} (mqtt);
\end{tikzpicture}
\caption{Session logging and offline sync path}
\label{fig:session_sync_flow}
\end{figure}

\subsection{Remote Stop Flow}

\begin{enumerate}[leftmargin=1.5em]
    \item Admin clicks Stop in web dashboard
    \item Web app writes to RTDB \texttt{/mms/commands/\{id\}}: \texttt{\{command:"stop", timestamp:now\}}
    \item bridge.py \texttt{onValue} listener triggers
    \item bridge.py checks command age: if $>$300s, discard and acknowledge
    \item bridge.py publishes to \texttt{mms/nodes/\{id\}/command} (QoS 1)
    \item ESP32 MQTT callback receives command
    \item ESP32 checks command timestamp: if $>$300s old, discard
    \item ESP32 turns relay OFF, logs end\_reason: \texttt{remote\_stop}
    \item ESP32 publishes session event; acknowledges command to RTDB
\end{enumerate}

\begin{figure}[H]
\centering
\begin{tikzpicture}[node distance=8mm and 10mm]
\node[mmsblock] (admin) {Admin clicks\\Stop};
\node[mmscloud, right=of admin] (rtdb) {RTDB command\\\texttt{/mms/commands/id}};
\node[mmsblock, right=of rtdb] (bridge) {bridge.py\\age check};
\node[mmsblock, right=of bridge] (mqtt) {MQTT command};
\node[mmsedge, right=of mqtt] (node) {ESP32\\relay OFF};
\node[mmscloud, below=of bridge] (ack) {RTDB ack\\session event};
\draw[mmsline] (admin) -- (rtdb);
\draw[mmsline] (rtdb) -- (bridge);
\draw[mmsline] (bridge) -- (mqtt);
\draw[mmsline] (mqtt) -- (node);
\draw[mmsline] (node) |- (ack);
\draw[mmsline] (ack) -| (admin);
\end{tikzpicture}
\caption{Remote stop command path}
\label{fig:remote_stop_flow}
\end{figure}

\subsection{Revocation Flow}

\begin{enumerate}[leftmargin=1.5em]
    \item Admin marks card as lost in web app
    \item Web app creates \texttt{/revoked/\{uid\}} in Firestore
    \item bridge.py Firestore \texttt{onSnapshot} triggers
    \item bridge.py rebuilds revocation list from all \texttt{/revoked} documents
    \item bridge.py publishes \texttt{mms/all/revoked} (retained, QoS 1): \texttt{\{uids:[...], updated\_at:ts\}}
    \item All connected nodes receive the update; update LittleFS \texttt{/config/revoked.json}
    \item On next card tap: UID checked against revocation list $\rightarrow$ denied
    \item Offline nodes: receive update on reconnect (retained message delivered automatically)
\end{enumerate}

\begin{figure}[H]
\centering
\begin{tikzpicture}[node distance=8mm and 12mm]
\node[mmsblock] (web) {Dashboard\\revoke card};
\node[mmscloud, right=of web] (revoked) {Firestore\\\texttt{/revoked/\{uid\}}};
\node[mmsblock, right=of revoked] (bridge) {bridge.py\\rebuild list};
\node[mmsblock, right=of bridge] (mqtt) {Retained MQTT\\\texttt{mms/all/revoked}};
\node[mmsedge, right=of mqtt] (node) {Nodes update\\LittleFS cache};
\draw[mmsline] (web) -- (revoked);
\draw[mmsline] (revoked) -- (bridge);
\draw[mmsline] (bridge) -- (mqtt);
\draw[mmsline] (mqtt) -- (node);
\end{tikzpicture}
\caption{Card revocation propagation}
\label{fig:revocation_flow}
\end{figure}

\subsection{OTA Update Flow}

\begin{enumerate}[leftmargin=1.5em]
    \item Super admin uploads \texttt{.bin} to Firebase Storage; copies download URL
    \item Super admin writes to RTDB \texttt{/mms/ota}: \texttt{\{firmware\_url, target\_version, released\_at\}}
    \item bridge.py RTDB OTA listener triggers
    \item bridge.py publishes OTA command to all nodes: \texttt{mms/nodes/+/command}
    \item ESP32 receives command; transitions to OTA state; relay OFF
    \item ESP32 calls \texttt{esp\_https\_ota()} with firmware URL
    \item On success: reboot to new partition; update NVS fw\_version
    \item On failure: if 3 crashes on new partition $\rightarrow$ rollback to previous partition
\end{enumerate}

\begin{figure}[H]
\centering
\begin{tikzpicture}[node distance=8mm and 9mm]
\node[mmsblock] (build) {Build\\\texttt{.bin}};
\node[mmscloud, right=of build] (storage) {Firebase Storage\\firmware URL};
\node[mmscloud, right=of storage] (ota) {RTDB\\\texttt{/mms/ota}};
\node[mmsblock, right=of ota] (bridge) {bridge.py\\publish command};
\node[mmsedge, below=of ota] (node) {ESP32 OTA\\download, verify, reboot};
\node[mmswarn, below=of node] (rollback) {Rollback if\\boot fails};
\draw[mmsline] (build) -- (storage);
\draw[mmsline] (storage) -- (ota);
\draw[mmsline] (ota) -- (bridge);
\draw[mmsline] (bridge) |- (node);
\draw[mmsdash] (node) -- (rollback);
\end{tikzpicture}
\caption{OTA release flow}
\label{fig:ota_flow}
\end{figure}

\section{MQTT Topic Map}

\begin{longtable}{L{5cm}L{2.5cm}C{1.5cm}C{1.5cm}L{4.5cm}}
\toprule
\textbf{Topic} & \textbf{Publisher} & \textbf{QoS} & \textbf{Retain} & \textbf{Payload} \\
\midrule
\endhead
\texttt{mms/nodes/\{id\}/status} & ESP32 & 1 & Yes & State, roll, session\_start, fw\_version, IP, RSSI \\
\texttt{mms/nodes/\{id\}/event} & ESP32 & 1 & No & Session event JSON \\
\texttt{mms/nodes/\{id\}/heartbeat} & ESP32 & 0 & No & \{ts, heap\_free, uptime\_s\} \\
\texttt{mms/nodes/\{id\}/command} & RPi bridge & 1 & No & \{cmd, issued\_by, ts\} \\
\texttt{mms/nodes/\{id\}/config} & RPi bridge & 1 & Yes & \{name, session\_limit, relay\_active\_high, machine\_active\} \\
\texttt{mms/all/revoked} & RPi bridge & 1 & Yes & \{uids:[...], updated\_at\} \\
\bottomrule
\caption{MQTT Topic Reference}
\label{tab:mqtt_topics}
\end{longtable}

\begin{notebox}
\textbf{Last Will and Testament (LWT):} Each ESP32 registers an LWT on \texttt{mms/nodes/\{id\}/status} with payload \texttt{\{"state":"offline"\}} (retained). If the node disconnects unexpectedly, the broker publishes this automatically. The bridge detects it and updates the RTDB node state to \texttt{"offline"}, which the dashboard reflects immediately.
\end{notebox}

\section{Offline Degradation Table}

\begin{table}[H]
\centering
\caption{System Behaviour When Components Are Unavailable}
\begin{tabular}{L{4cm}L{6cm}L{4.5cm}}
\toprule
\textbf{Unavailable component} & \textbf{Impact on access control} & \textbf{Impact on logging} \\
\midrule
WiFi (node disconnected) & No impact. Card access continues. & Sessions buffered in LittleFS; flushed on reconnect \\
Raspberry Pi down & No impact. Access decisions are local. & Sessions buffered; flushed when RPi recovers \\
Firebase down & No impact. & bridge.py buffers events in memory; written when Firebase recovers \\
RFID reader (hardware fault) & No card reads possible. Node logs error. & No sessions started. \\
Relay (hardware fault) & Machine may not respond to access grant. & Sessions still logged. \\
\bottomrule
\end{tabular}
\end{table}

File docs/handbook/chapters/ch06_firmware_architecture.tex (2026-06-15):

%% Chapter 6 — Firmware Architecture
\chapter{Firmware Architecture}
\label{ch:firmware}

\section{Firmware Structure}

The access node firmware is located in \texttt{v2/access\_node/}. It is organised as a collection of single-responsibility modules coordinated by a central state machine.

\begin{table}[H]
\centering
\caption{Firmware Module Map}
\label{tab:modules}
\begin{tabular}{L{4.5cm}L{4.5cm}L{5.5cm}}
\toprule
\textbf{Module} & \textbf{Files} & \textbf{Responsibility} \\
\midrule
Config & \texttt{config.h} & Machine ID, name, session limit, broker IP \\
Secrets & \texttt{secrets.h} & WiFi credentials, master key (gitignored) \\
NVS Manager & \texttt{nvs\_manager.h/.cpp} & Read/write NVS namespace \texttt{mms\_config} \\
RFID Handler & \texttt{rfid\_handler.h/.cpp} & MFRC522 SPI init; card detect; sector key derivation; block read \\
Card Schema & \texttt{card\_schema.h/.cpp} & Parse blocks 4+5; validate schema; return \texttt{CardData} struct \\
Access Control & \texttt{access\_control.h/.cpp} & Revocation list check + permission bitmask check \\
Relay Controller & \texttt{relay\_controller.h/.cpp} & GPIO abstraction; safe OFF on init \\
Slot Sensor & \texttt{slot\_sensor.h/.cpp} & HC89 debounced input \\
Session Manager & \texttt{session\_manager.h/.cpp} & Session start/end/timeout; build log entry JSON \\
MQTT Client & \texttt{mqtt\_client.h/.cpp} & PubSubClient wrapper; reconnect backoff; command callback \\
Revocation Cache & \texttt{revocation\_cache.h/.cpp} & LittleFS \texttt{/config/revoked.json}; UID lookup \\
LittleFS Logger & \texttt{littlefs\_logger.h/.cpp} & JSONL append; rotate at 50KB; flush on connect \\
Display Primary & \texttt{display\_primary.h/.cpp} & 128$\times$64 SPI OLED; state-driven rendering \\
Display Status & \texttt{display\_status.h/.cpp} & 128$\times$32 I2C OLED; persistent status strip \\
LED Controller & \texttt{led\_controller.h/.cpp} & WS2812; non-blocking animations \\
Watchdog & \texttt{watchdog.h/.cpp} & ESP32 TWDT; 30s timeout; feed in main loop \\
OTA Handler & \texttt{ota\_handler.h/.cpp} & Version check; \texttt{esp\_https\_ota}; rollback \\
State Machine & \texttt{state\_machine.h/.cpp} & Central FSM; drives all transitions \\
Main & \texttt{access\_node.ino} & \texttt{setup()} + \texttt{loop()}; watchdog feed \\
\bottomrule
\end{tabular}
\end{table}

\section{Firmware State Machine}

The state machine is the central coordinator. All hardware events and MQTT messages cause state transitions. No module changes hardware state directly --- all changes go through the state machine.

\begin{figure}[H]
\centering
\begin{tikzpicture}[node distance=8mm and 9mm]
\node[state] (boot) {BOOT};
\node[state, below=of boot] (idle) {IDLE};
\node[state, below=of idle] (read) {CARD\\READING};
\node[mmswarn, left=of read] (denied) {ACCESS\\DENIED};
\node[mmswarn, right=of read] (disabled) {MACHINE\\DISABLED};
\node[state, below=of read] (active) {SESSION\\ACTIVE};
\node[mmswarn, below left=of active] (warning) {TIMEOUT\\WARNING};
\node[mmswarn, below=of warning] (expired) {TIMEOUT\\EXPIRED};
\node[state, below=of active] (ended) {SESSION\\ENDED};
\node[state, right=of active] (ota) {OTA\\UPDATE};
\draw[mmsline] (boot) -- node[right,font=\scriptsize]{init hardware, WiFi, MQTT} (idle);
\draw[mmsline] (idle) -- node[right,font=\scriptsize]{HC89 card detected} (read);
\draw[mmsline] (read) -- node[above,font=\scriptsize]{auth/schema/permission fail} (denied);
\draw[mmsline] (read) -- node[above,font=\scriptsize]{machine inactive} (disabled);
\draw[mmsline] (read) -- node[right,font=\scriptsize]{permission OK, relay ON} (active);
\draw[mmsline] (active) -- node[left,font=\scriptsize]{limit - 2 min} (warning);
\draw[mmsline] (warning) -- node[left,font=\scriptsize]{limit reached} (expired);
\draw[mmsline] (expired) -| node[below,font=\scriptsize]{relay OFF} (ended);
\draw[mmsline] (active) -- node[right,font=\scriptsize]{card removed / stop} (ended);
\draw[mmsline] (ended.west) -- ++(-34mm,0) |- node[pos=0.15,below,font=\scriptsize]{after display timeout} (idle.west);
\draw[mmsdash] (denied) |- (idle);
\draw[mmsdash] (disabled) |- (idle);
\draw[mmsdash] (active) -- node[above,font=\scriptsize]{MQTT OTA} (ota);
\draw[mmsdash] (ota) |- (boot);
\end{tikzpicture}
\caption{Access Node Firmware State Machine}
\label{fig:state_machine}
\end{figure}

\section{NVS Configuration}

NVS (Non-Volatile Storage) persists configuration across reboots. The namespace is \texttt{mms\_config}.

\begin{table}[H]
\centering
\caption{NVS Configuration Keys}
\begin{tabular}{L{3.5cm}C{2.5cm}L{3cm}L{5cm}}
\toprule
\textbf{Key} & \textbf{Type} & \textbf{Set by} & \textbf{Description} \\
\midrule
\texttt{machine\_id}   & uint8   & \texttt{config.h} at flash & 1--32 \\
\texttt{master\_key}   & blob (32B) & \texttt{secrets.h} at flash & HMAC master secret \\
\texttt{machine\_name} & string (32) & MQTT config push & Display name; fallback to \texttt{config.h} \\
\texttt{session\_limit} & uint16 & MQTT config push & Minutes; fallback to \texttt{config.h} \\
\texttt{relay\_active\_high} & uint8 & MQTT config push & 1=HIGH activates relay; 0=LOW \\
\texttt{machine\_active} & uint8 & MQTT config push & 0=disabled; all access denied \\
\texttt{fw\_version}  & string & OTA handler & Current firmware version string \\
\bottomrule
\end{tabular}
\end{table}

On first boot (no NVS data), the firmware uses the fallback values from \texttt{config.h}. On the first MQTT connect, the bridge pushes the Firestore config, which overwrites NVS. On subsequent boots without MQTT connection, NVS values are used.

\section{LittleFS File Layout}

\begin{table}[H]
\centering
\caption{LittleFS file layout}
\begin{tabular}{L{5cm}L{9cm}}
\toprule
\textbf{Path} & \textbf{Purpose} \\
\midrule
\texttt{/logs/sessions.jsonl} & Append-only offline session event log. \\
\texttt{/logs/sessions.old.jsonl} & Previous rotation backup; overwritten by the next rotation. \\
\texttt{/config/revoked.json} & Cached revoked UID list with \texttt{updated\_at} timestamp. \\
\bottomrule
\end{tabular}
\end{table}

\textbf{Log rotation:} When \texttt{sessions.jsonl} exceeds 50KB:
\begin{enumerate}[leftmargin=1.5em]
    \item Rename \texttt{sessions.jsonl} $\rightarrow$ \texttt{sessions.old.jsonl} (overwrites previous)
    \item Create new empty \texttt{sessions.jsonl}
    \item Continue appending
\end{enumerate}

\textbf{Flush on MQTT connect:}
\begin{enumerate}[leftmargin=1.5em]
    \item Open \texttt{sessions.jsonl}
    \item Read line by line; attempt JSON parse each line
    \item Discard any line that fails to parse (partial write from power loss)
    \item Publish each valid line to \texttt{mms/nodes/\{id\}/event} (QoS 1)
    \item Wait for broker ACK before publishing next
    \item After all lines published: delete file
\end{enumerate}

\section{Session Log Entry Format}

Each line in \texttt{sessions.jsonl} is a compact JSON object:

\begin{lstlisting}[style=jsonlstyle,caption={Session log entry format}]
{"t":1718600000,"r":"220002123","m":3,"e":"session_end",
 "d":245,"er":"card_removed"}
\end{lstlisting}

Fields:
\begin{itemize}[leftmargin=1.5em,noitemsep]
    \item \texttt{t}: Unix timestamp of session end
    \item \texttt{r}: Roll number string
    \item \texttt{m}: Machine ID integer
    \item \texttt{e}: Event type (\texttt{"session\_end"}, \texttt{"boot"})
    \item \texttt{d}: Duration in seconds
    \item \texttt{er}: End reason (\texttt{"card\_removed"}, \texttt{"timeout"}, \texttt{"remote\_stop"}, \texttt{"watchdog"})
\end{itemize}

\section{Display Content}

\subsection{Primary OLED (128$\times$64)}

\begin{table}[H]
\centering
\caption{Primary Display Content by State}
\begin{tabular}{L{4cm}L{10.5cm}}
\toprule
\textbf{State} & \textbf{Display content} \\
\midrule
IDLE & ``Tinkerers' Lab / IIT Indore'' + machine name + ``Tap card to start'' \\
CARD\_READING & ``Reading card...'' + spinner animation \\
ACCESS\_DENIED & ``!! Access Denied !!'' + reason + roll number (clears after 3s) \\
MACHINE\_DISABLED & ``Machine Offline'' + ``Contact admin'' \\
SESSION\_ACTIVE & Roll number + machine name + ``Time: MM:SS / HH:MM'' \\
TIMEOUT\_WARNING & ``!! 2 min left !!'' + ``Remove card soon'' + roll number \\
SESSION\_ENDED & ``Session Complete'' + roll + duration + ``Thank you!'' \\
OTA\_UPDATE & ``Updating FW...'' + version + progress percentage + ``Do not remove'' \\
ERROR & ``System Error'' + error code + ``Restarting...'' \\
\bottomrule
\end{tabular}
\end{table}

\subsection{Status Strip OLED (128$\times$32)}

Always shows:
\begin{table}[H]
\centering
\caption{Status strip layout}
\begin{tabular}{L{4cm}L{10cm}}
\toprule
\textbf{Region} & \textbf{Content} \\
\midrule
Left indicators & WiFi and MQTT symbols; filled when connected and empty when disconnected. \\
Center text & Machine name from NVS or Firestore config push. \\
Right text & Current time after NTP sync. \\
\bottomrule
\end{tabular}
\end{table}

\section{WS2812 LED State Map}

\begin{table}[H]
\centering
\caption{LED Colour and Pattern per State}
\begin{tabular}{L{3.5cm}L{3cm}L{7cm}}
\toprule
\textbf{State} & \textbf{Colour} & \textbf{Pattern} \\
\midrule
IDLE & White (dim) & Slow breathe, 2s period \\
CARD\_READING & Cyan & Fast blink, 200ms \\
SESSION\_ACTIVE & Green & Solid \\
TIMEOUT\_WARNING & Yellow $\leftrightarrow$ Orange & Alternate, 1s \\
TIMEOUT\_EXPIRED & Red & Solid (500ms) \\
ACCESS\_DENIED & Red & 3$\times$ quick flash then off \\
MACHINE\_DISABLED & Purple & Solid dim \\
OTA\_UPDATE & Blue & Chasing animation \\
ERROR & Red & Solid \\
\bottomrule
\end{tabular}
\end{table}

\section{Watchdog}

The hardware watchdog is the last line of defence against firmware hangs:

\begin{lstlisting}[language=C,caption={Watchdog initialisation in setup()}]
esp_task_wdt_init(30, true);  // 30s timeout, panic on trigger
esp_task_wdt_add(NULL);       // watch the main task
\end{lstlisting}

\begin{lstlisting}[language=C,caption={Watchdog feed in main loop}]
void loop() {
    esp_task_wdt_reset();   // must be called at least every 30s
    stateMachine.tick();
    // ...
}
\end{lstlisting}

If \texttt{loop()} takes longer than 30 seconds (e.g., blocking I2C, infinite RFID retry), the TWDT triggers a panic and the ESP32 reboots. The boot reason is available via \texttt{esp\_reset\_reason()} on the next boot.

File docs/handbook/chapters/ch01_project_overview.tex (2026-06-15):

%% Chapter 1 — Project Overview
\chapter{Project Overview}
\label{ch:overview}

\section{What Is MMS V2?}

The Machine Management System Version 2 (MMS V2) is an embedded IoT platform for controlling and monitoring access to workshop equipment in the Tinkerers' Lab at IIT Indore. The system enforces that only authorised students can operate specific machines, logs all usage to a cloud database, and provides administrators with real-time monitoring and remote control capabilities via a web dashboard.

The system is deployed on a local area network within the lab and communicates with Firebase (Google Cloud) for permanent data storage and the administrator web interface.

\section{Scope and Objectives}

\subsection{What MMS V2 Does}

\begin{itemize}[leftmargin=1.5em]
    \item \textbf{Access control}: RFID card authentication at each machine. A card is accepted only if (a) it is a valid MMS V2 card, (b) it is not revoked, and (c) its machine permission bitmask authorises the specific machine.
    \item \textbf{Machine control}: An ESP32 node controls a relay that interrupts mains power to the machine. Access granted $\rightarrow$ relay ON $\rightarrow$ machine receives power. Session ended $\rightarrow$ relay OFF $\rightarrow$ machine loses power.
    \item \textbf{Session tracking}: Every session (start time, end time, duration, end reason, student roll number, machine) is logged to Firebase Firestore.
    \item \textbf{Offline operation}: Access decisions are made locally on the ESP32, without any network call. The system functions even if the Raspberry Pi or Firebase is unreachable.
    \item \textbf{Remote administration}: Admins can view real-time machine status, stop active sessions, enable or disable machines, revoke lost cards, and trigger firmware updates from a web browser.
    \item \textbf{Card management}: A kiosk station (Flask web app + MFRC522 reader) issues personalised RFID cards to students. Each card is cryptographically personalised with the student's roll number, PIN hash, and machine permissions.
\end{itemize}

\subsection{What MMS V2 Does Not Do}

\begin{itemize}[leftmargin=1.5em]
    \item PIN verification at the machine (Phase 4 — requires rotary encoder user interface, not yet deployed)
    \item Machine booking or reservation (separate future system)
    \item Integration with the institute student database (cards are issued manually)
    \item Control of AC 240V systems beyond the relay/SSR interface (wiring to machines is the lab's responsibility)
    \item Multi-factor authentication (planned future upgrade)
\end{itemize}

\section{System Scale}

\begin{table}[H]
\centering
\caption{MMS V2 System Scale Parameters}
\begin{tabular}{L{6cm}L{8cm}}
\toprule
\textbf{Parameter} & \textbf{Value} \\
\midrule
Maximum machines supported & 32 (per permission bitmask) \\
Currently deployed & 5 machines \\
Maximum concurrent users & 32 (one per machine) \\
Maximum registered users & Unlimited (Firestore) \\
Expected user base & 300 students \\
RFID card technology & MIFARE Classic 1K \\
Card capacity per institution & Effectively unlimited \\
Offline session buffer per node & \textasciitilde{}500 sessions (50KB LittleFS) \\
OTA rollout time (all 5 nodes) & \textasciitilde{}5 minutes \\
Session data retention & Indefinite (Firestore Spark tier: 1GB free) \\
\bottomrule
\end{tabular}
\end{table}

\section{Deployed Machines}

\begin{table}[H]
\centering
\caption{Canonical Machine Registry}
\label{tab:machines}
\begin{tabular}{C{1.5cm}L{4.5cm}C{2.5cm}C{2.5cm}C{2cm}}
\toprule
\textbf{ID} & \textbf{Machine Name} & \textbf{Session Limit} & \textbf{Permission Bit} & \textbf{Zone} \\
\midrule
1 & Creality 3D Printer     & 60 min & Bit 0 & Zone A \\
2 & Fracktal Laser Cutter   & 30 min & Bit 1 & Zone B \\
3 & Soldering Station 1     & 15 min & Bit 2 & Zone C \\
4 & Soldering Station 2     & 15 min & Bit 3 & Zone C \\
5 & Bosche Grinder          & 20 min & Bit 4 & Zone D \\
\bottomrule
\end{tabular}
\end{table}

\begin{warnbox}
\textbf{WARNING — Three-places-in-sync rule:} Machine IDs must match exactly in \texttt{config.h} (ESP32 firmware), \texttt{scripts/seed\_machines.py} (Firestore seeder), and \texttt{kiosk\_station/config.py} (kiosk permission UI). An ID mismatch means sessions are logged under the wrong machine or cards grant wrong machine access. See Chapter~\ref{ch:firebase} and Appendix~\ref{app:machine_registry}.
\end{warnbox}

\section{Key Stakeholders}

\begin{description}[leftmargin=2em,font=\bfseries]
    \item[Lab Coordinator] Responsible for day-to-day operations: issuing cards, managing user accounts, monitoring dashboard, handling card loss/replacement.
    \item[Admin] Web app admin role: all coordinator functions plus remote stop, machine enable/disable, session log export.
    \item[Super Admin] Highest privilege: OTA firmware updates, adding/removing admins, Firebase console access.
    \item[Student] Holds an RFID card. No web app access. Operates machines by tapping card.
    \item[Future Maintainer] Anyone who maintains or extends the system after the original developers. This document is written primarily for them.
\end{description}

\section{Glossary}

\begin{longtable}{L{3.5cm}L{10cm}}
\toprule
\textbf{Term} & \textbf{Definition} \\
\midrule
\endhead
RFID & Radio Frequency Identification. Contactless card technology. \\
MIFARE Classic 1K & Type of RFID card with 1024 bytes of data storage in 16 sectors. \\
ESP32 & Dual-core 240MHz microcontroller with built-in WiFi and Bluetooth, by Espressif. \\
MQTT & Message Queuing Telemetry Transport. Lightweight publish-subscribe messaging protocol. \\
Mosquitto & Open-source MQTT broker. Runs on the Raspberry Pi. \\
Bridge & \texttt{bridge.py} — Python service on RPi that relays data between MQTT and Firebase. \\
Firebase & Google Cloud platform. MMS V2 uses Firestore, RTDB, Storage, Hosting, and Auth. \\
Firestore & Firebase document database. Stores permanent records (users, sessions, machines). \\
RTDB & Firebase Realtime Database. Stores live state (node status, pending commands). \\
LittleFS & Lightweight filesystem for flash memory. Used on ESP32 for offline session buffering. \\
NVS & Non-Volatile Storage. ESP32's key-value store. Used to persist configuration. \\
OTA & Over-The-Air firmware update. \\
HMAC-SHA256 & Hash-based Message Authentication Code using SHA-256. Used for key derivation and PIN hashing. \\
Sector key & 6-byte key that unlocks a MIFARE sector for read/write. Derived per-card using HMAC-SHA256. \\
Permission bitmask & 32-bit unsigned integer. Each bit represents access to one machine. \\
HC89 & Optical IR slot sensor. Detects when a card is inserted. \\
Relay & Electrically controlled switch. Opens/closes machine power circuit. \\
SSR & Solid-State Relay. Semiconductor-based relay, no moving parts. Preferred for high-cycling loads. \\
WS2812 & Individually addressable RGB LED with integrated controller chip. \\
SPI & Serial Peripheral Interface. Communication bus shared by RFID reader and primary OLED. \\
I2C & Inter-Integrated Circuit. Two-wire bus used by secondary OLED. \\
IST & Indian Standard Time. UTC+5:30. Used for all NTP-synced timestamps on nodes. \\
TWDT & Task Watchdog Timer. 30-second hardware watchdog on ESP32. Resets if firmware stalls. \\
\bottomrule
\end{longtable}

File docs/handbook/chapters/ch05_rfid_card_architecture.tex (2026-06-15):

%% Chapter 5 — RFID Card Architecture
\chapter{RFID Card Architecture}
\label{ch:rfid}

\section{MIFARE Classic 1K Overview}

MIFARE Classic 1K cards have 1024 bytes of non-volatile EEPROM organised as:
\begin{itemize}[leftmargin=1.5em]
    \item 16 sectors (sectors 0--15)
    \item 4 blocks per sector (each block = 16 bytes)
    \item Block 0 of Sector 0 is the manufacturer block (UID + config; read-only)
    \item Each sector has a trailer block (last block in sector) containing two keys (Key A and Key B) and access bits
    \item Data blocks: 3 per sector (excluding trailer)
    \item Sectors are authenticated independently using their own keys
\end{itemize}

\section{V2 Card Schema}

MMS V2 uses \textbf{Sector 1} (blocks 4--7). Sector 0 is left untouched (manufacturer data and default keys). Using Sector 1 means V2 cards can coexist with other applications on Sector 0 if needed.

\subsection{Sector 1 Layout}

\begin{table}[H]
\centering
\caption{MMS V2 RFID Card Schema --- Sector 1}
\label{tab:card_schema}
\begin{tabular}{C{1.5cm}C{1.5cm}L{10.5cm}}
\toprule
\textbf{Block} & \textbf{Bytes} & \textbf{Content} \\
\midrule
4 & 0--8   & Roll number as ASCII string, zero-padded to 9 characters \\
  & 9      & Schema version byte: \texttt{0x02} (V2) \\
  & 10--15 & Reserved, all \texttt{0x00} \\
\midrule
5 & 0--7   & PIN hash: $\text{HMAC-SHA256}(\text{master\_key} \| \text{uid\_hex},\, \text{pin\_string})[0..7]$ \\
  & 8--11  & Machine permission bitmask (uint32, little-endian) \\
  & 12--15 & Reserved, all \texttt{0x00} \\
\midrule
6 & 0--15  & Reserved for future use (expiry date, academic year) \\
\midrule
7 & 0--5   & Key A = derived sector key (write-only; never returned by MFRC522 on read) \\
  & 6--9   & Access bits \\
  & 10--15 & Key B = \texttt{0x00} (not used) \\
\bottomrule
\end{tabular}
\end{table}

\subsection{Schema Version Byte}

The schema version byte at Block 4, byte 9 is \texttt{0x02} for all V2 cards. If a card is read and this byte is not \texttt{0x02}, the firmware rejects it with \texttt{ACCESS\_DENIED} and logs \texttt{"schema version mismatch"}. This prevents:
\begin{itemize}[leftmargin=1.5em]
    \item V1 cards (written to Block 1+2 with no schema byte) from being accepted
    \item Blank or foreign cards from accidentally gaining access
    \item Future V3 cards (with schema byte \texttt{0x03}) from being accepted by V2 nodes
\end{itemize}

\section{Sector Key Derivation}

Each card's Sector 1 is protected by a unique 6-byte key derived from the master key and the card's UID:

\[
\text{sector\_key}[6] = \text{HMAC-SHA256}\!\left(\text{master\_key},\, \text{uid\_as\_uppercase\_hex\_string}\right)[0..5]
\]

For a card with UID bytes \texttt{[0xA1, 0xB2, 0xC3, 0xD4]}, the UID string is \texttt{"A1B2C3D4"}.

This derivation is performed by:
\begin{itemize}[leftmargin=1.5em]
    \item The kiosk (\texttt{station\_writer.ino}) when writing the card, to set the sector key
    \item Every access node on every card read, to authenticate Sector 1 before reading blocks
\end{itemize}

The master key is identical across all nodes and the kiosk --- they all share the same 32-byte secret stored in \texttt{secrets.h} / \texttt{secrets.py} / \texttt{secrets\_station.h}.

\begin{notebox}
HMAC-SHA256 is implemented using \texttt{mbedtls\_md\_hmac()} from the ESP32's built-in mbedTLS library. No additional library is required. The same function is called from the kiosk (C++ Arduino) and the RPi bridge (Python \texttt{hmac} module with sha256 digest).
\end{notebox}

\section{PIN Hash}

The PIN hash stored in Block 5 bytes 0--7 is:
\[
\text{pin\_hash}[8] = \text{HMAC-SHA256}\!\left(\text{master\_key} \| \text{uid\_hex},\, \text{pin\_string}\right)[0..7]
\]

Where \texttt{pin\_string} is the 4-character ASCII PIN (e.g., ``1234'').

The PIN hash is computed by:
\begin{itemize}[leftmargin=1.5em]
    \item The kiosk when issuing the card
    \item The web app's \texttt{hashPin()} function when the admin sets a PIN
    \item Access nodes do NOT verify PIN in V2 (Phase 4)
\end{itemize}

\begin{warnbox}
\textbf{In V2, the PIN is not verified at the machine.} The PIN hash is stored on the card for future use (Phase 4 --- rotary encoder PIN entry). In V2, card tap + permission bit check is sufficient for access.
\end{warnbox}

\section{Machine Permission Bitmask}

Block 5 bytes 8--11 contain a 32-bit little-endian unsigned integer. Each bit corresponds to one machine:

\begin{equation}
\text{allowed} = (\text{perm\_bitmask} \gg (\text{machine\_id} - 1)) \;\&\; 1
\end{equation}

\begin{table}[H]
\centering
\caption{Machine Permission Bitmask Examples}
\begin{tabular}{L{3cm}C{2cm}C{3cm}L{5.5cm}}
\toprule
\textbf{Access to machines} & \textbf{Decimal} & \textbf{Hex} & \textbf{Binary (LSB first)} \\
\midrule
None (no access) & 0 & \texttt{0x00000000} & \texttt{00000000...} \\
Machine 1 only & 1 & \texttt{0x00000001} & \texttt{10000000...} (bit 0 set) \\
Machine 3 only & 4 & \texttt{0x00000004} & \texttt{00100000...} (bit 2 set) \\
Machines 1 and 3 & 5 & \texttt{0x00000005} & \texttt{10100000...} (bits 0+2 set) \\
All 5 machines & 31 & \texttt{0x0000001F} & \texttt{11111000...} (bits 0--4 set) \\
Full access (all 32) & 4294967295 & \texttt{0xFFFFFFFF} & all bits set \\
\bottomrule
\end{tabular}
\end{table}

The bitmask supports up to 32 machines. Currently 5 are deployed (bits 0--4). Bits 5--31 are reserved for future machines.

\section{Card Write Process}

When the kiosk writes a card:

\begin{enumerate}[leftmargin=1.5em]
    \item Admin selects student and machine permissions in web UI
    \item Flask app computes bitmask and PIN hash
    \item Flask app sends JSON to station\_writer via serial: \\
          \texttt{\{"roll":"220002123","perm\_mask":5,"pin\_hash":"aabb...","uid":"A1B2C3D4"\}}
    \item station\_writer.ino receives JSON (ArduinoJson), places card on MFRC522
    \item Derives sector key from UID
    \item Authenticates Sector 1 with default key (\texttt{0xFFFFFFFFFFFF} for fresh cards) or derived key (for re-issue)
    \item Writes Block 4: roll bytes 0--8 + schema byte \texttt{0x02} + zeros 10--15
    \item Writes Block 5: pin\_hash bytes 0--7 + perm\_mask LE bytes 8--11 + zeros 12--15
    \item Writes Sector 1 trailer (Block 7): Key A = derived sector key, Key B = zeros
    \item Reads back Block 4 and verifies schema byte = \texttt{0x02}
    \item Reports \texttt{WRITE\_SUCCESS} or \texttt{WRITE\_FAILED} via serial to Flask app
\end{enumerate}

\section{Card Read Process}

When a node reads a card during an access attempt:

\begin{enumerate}[leftmargin=1.5em]
    \item HC89 signals card present
    \item \texttt{MFRC522::PICC\_IsNewCardPresent()} confirms a card in field
    \item \texttt{MFRC522::PICC\_ReadCardSerial()} reads the 4-byte UID
    \item Sector key is derived from UID + master key
    \item \texttt{MFRC522::PCD\_Authenticate()} authenticates Sector 1 with derived key
    \item Block 4 is read; schema byte checked (must be \texttt{0x02})
    \item Block 5 is read; perm\_mask extracted from bytes 8--11 (LE decode)
    \item UID is checked against LittleFS revocation list
    \item Permission bit checked for this machine\_id
    \item Result: GRANTED or DENIED with reason
\end{enumerate}

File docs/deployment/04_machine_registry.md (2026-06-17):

# Section 04 — Machine Registry

← [Bill of Materials](03_bill_of_materials.md) | → [Hardware Assembly](05_hardware_assembly.md)

---

## Why This Section Exists

The machine ID is the single most critical configuration value in MMS V2. It appears in three places simultaneously:
1. The ESP32 node firmware (`config.h` → `MACHINE_ID`)
2. The kiosk station Python app (`apps/apps/kiosk_station/config.py` → `MACHINE_IDS` dict)
3. Firestore (`/machines/{id}` document ID)

If these three are inconsistent — even by one number — cards issued for "Soldering Station 1" will be denied on the node claiming to be "Soldering Station 1" (because the permission bit will be wrong), and the node will log events under the wrong machine ID in Firestore.

**Read this section before flashing any node or issuing any card.**

---

## Canonical Machine Registry (Current Deployment)

| Machine ID | Machine Name | Location | Relay Type | Session Limit | Permission Bit | Firestore Doc ID |
|---|---|---|---|---|---|---|
| 1 | Creality 3D Printer | Zone A | Mechanical (active HIGH) | 60 min | Bit 0 | `"1"` |
| 2 | Fracktal Laser Cutter | Zone B | Mechanical (active HIGH) | 30 min | Bit 1 | `"2"` |
| 3 | Soldering Station 1 | Zone C | Mechanical (active HIGH) | 15 min | Bit 2 | `"3"` |
| 4 | Soldering Station 2 | Zone C | Mechanical (active HIGH) | 15 min | Bit 3 | `"4"` |
| 5 | Bosche Grinder | Zone D | Mechanical (active HIGH) | 20 min | Bit 4 | `"5"` |

**Permission bitmask examples:**
- Student allowed on all 5 machines: `0b00011111` = `0x1F` = `31` decimal
- Student allowed only on Soldering Stations (3 and 4): `0b00001100` = `0x0C` = `12` decimal
- Student allowed on 3D Printer only: `0b00000001` = `0x01` = `1` decimal

**Formula:** `perm_mask = sum(1 << (machine_id - 1) for each allowed machine_id)`

---

## The Three Places To Keep In Sync

### Place 1: `firmware/access_node/config.h`
```cpp
#define MACHINE_ID    3
#define MACHINE_NAME  "Soldering Station 1"
```
This is flashed into one specific physical node. Every node gets its own flash with its own MACHINE_ID.

### Place 2: `apps/apps/kiosk_station/config.py`
```python
MACHINE_IDS = {
    "Creality 3D Printer":    1,
    "Fracktal Laser Cutter":  2,
    "Soldering Station 1":    3,
    "Soldering Station 2":    4,
    "Bosche Grinder":         5,
}
```
This is used by the kiosk to build the permission bitmask when issuing a card. The kiosk UI shows a machine name dropdown — the admin selects which machines the student is allowed to use, and the kiosk derives the bitmask.

### Place 3: Firestore `/machines/{id}`
```json
{
  "name": "Soldering Station 1",
  "session_limit_minutes": 15,
  "relay_active_high": true,
  "machine_active": true,
  "location": "Zone C"
}
```
Document ID is the string `"3"`. This is seeded by `scripts/seed_machines.py`.

---

## Procedure: Adding A New Machine

Follow all 6 steps. Do not skip any.

### Step 1 — Assign the next available ID

Check the current registry above. The next available ID is the highest current ID + 1. Never reuse a retired ID — cards already issued with a retired ID's bit set will unexpectedly gain access to the new machine.

*Example: If 5 machines exist (IDs 1–5), the next machine is ID 6.*

### Step 2 — Add to kiosk config

Edit `apps/apps/kiosk_station/config.py`:
```python
MACHINE_IDS = {
    ...
    "New Machine Name":  6,   ← add this line
}
```
Restart the Flask kiosk app after editing.

### Step 3 — Add to Firestore

Either use the web admin dashboard (Machines → Add Machine) or run:
```bash
# Add to seed_machines.py MACHINES list, then run:
python3 scripts/seed_machines.py
```

Or manually via Firebase Console:
```
Firestore → machines → Add document
  Document ID: "6"
  Fields:
    name: "New Machine Name"
    session_limit_minutes: 15
    relay_active_high: true
    machine_active: true
    location: "Zone X"
```

### Step 4 — Flash the new node

In `firmware/access_node/config.h`:
```cpp
#define MACHINE_ID    6
#define MACHINE_NAME  "New Machine Name"
```

Flash the firmware. See [Section 11 — Node Provisioning](11_access_node_provisioning.md).

### Step 5 — Restart the bridge

The bridge's config listener will detect the new Firestore document and push the config to the new node via MQTT.
```bash
ssh pi@192.168.0.10
sudo systemctl restart mms-bridge
```

### Step 6 — Update cards for users who need access

Existing cards do not automatically gain access to the new machine. Each user who needs access to Machine 6 must have their card re-issued with the new bitmask. Go to the kiosk, re-issue the card with Machine 6 ticked. The old bitmask is overwritten.

---

## Procedure: Renaming A Machine

Renaming does not require card re-issue — permissions are stored as a bitmask, not a name.

### Step 1 — Update Firestore

In Firebase Console or web app admin:
```
Firestore → machines → {id} → edit "name" field
```

### Step 2 — Update `apps/apps/kiosk_station/config.py`

```python
MACHINE_IDS = {
    ...
    "New Name":  3,   ← change "Soldering Station 1" to "New Name"
}
```

### Step 3 — Restart kiosk app

The kiosk dropdown will now show the new name.

### Step 4 — Push config to node

The bridge's Firestore config listener will detect the name change and push `{name: "New Name"}` to `mms/nodes/3/config` (retained). The node will update its NVS and OLED display within seconds.

**Verification:** Check the 128×64 OLED on the node — it should show the new machine name within 10 seconds of the Firestore change.

---

## Procedure: Decommissioning A Machine

Decommissioning a machine means disabling it so it can't be used, but keeping its ID reserved.

### Step 1 — Disable in Firestore

In Firebase Console:
```
Firestore → machines → {id} → set machine_active: false
```

The bridge will push `{machine_active: false}` to the node. The node will transition to MACHINE_DISABLED state — all card taps will be denied, OLED will show "Machine Offline".

### Step 2 — Remove from kiosk dropdown

Remove the line from `apps/apps/kiosk_station/config.py`. This prevents the kiosk admin from accidentally granting permissions to the decommissioned machine.

### Step 3 — Do NOT reuse the ID

Mark the ID as retired in the registry above (add "(RETIRED)" to the name in Firestore). If the machine is replaced by a different machine, give the new machine a new ID. Reusing IDs invalidates existing cards that have the old machine's bit set.

---

## Registry Change Log

Maintain this log. Date every change.

| Date | Change | Performed By |
|---|---|---|
| _YYYY-MM-DD_ | Initial seed — 5 machines | _Name_ |
| | | |

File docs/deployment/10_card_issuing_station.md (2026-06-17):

# Section 10 — Card Issuing Station

← [Web Application Deployment](09_web_application_deployment.md) | → [Access Node Provisioning](11_access_node_provisioning.md)

---

## Why This Section Exists

The card issuing station (kiosk) is where physical RFID cards are personalised for each student. It encodes the student's roll number, PIN hash, and machine permission bitmask onto a MIFARE Classic 1K card using a cryptographic sector key derived from the master key. Without this station, no student can use any machine.

---

## How Card Issuance Works

```
Admin opens kiosk web UI
  → Selects student from database (or enters new student info)
  → Selects which machines student is allowed to use
  → Clicks "Issue Card"

Flask app (kiosk_station/app.py):
  1. Computes permission bitmask from selected machines
  2. Computes PIN hash: HMAC-SHA256(master_key ∥ uid_hex, pin_string)[0:7]
     (8 bytes = 16 hex chars)
  3. Sends JSON command to station_writer.ino via serial:
     {"roll":"220002123","perm_mask":15,"pin_hash":"aabbccddaabbccdd","uid":"A1B2C3D4"}

station_writer.ino (on ESP32/Arduino):
  1. Waits for card on MFRC522
  2. Reads UID
  3. Derives sector key: HMAC-SHA256(master_key, uid_hex_uppercase)[0:5]
  4. Authenticates Sector 1 with default key (fresh card) or derived key (re-issue)
  5. Writes Block 4: roll_number[0:8] + 0x02 (schema byte)
  6. Writes Block 5: pin_hash[0:7] + perm_mask (uint32 LE) 
  7. Updates Sector 1 trailer: Key A = derived sector key
  8. Verifies Block 4 schema byte = 0x02
  9. Reports "WRITE_SUCCESS" or "WRITE_FAILED"

Flask app receives result → shows success/failure to admin
```

---

## Hardware Assembly

The kiosk needs:
1. **Computer** (laptop, RPi, or any Linux/Windows/Mac with Python 3.10+)
2. **MFRC522 module** connected to an Arduino/ESP32 via USB serial
3. **USB cable** from computer to Arduino/ESP32

**Option A — ESP32 as station writer (recommended):**
```
Laptop USB ←──→ ESP32 (station_writer.ino flashed)
                  └── MFRC522 (SPI, same wiring as node)
```

**Option B — Arduino Nano/Uno as station writer:**
```
Laptop USB ←──→ Arduino Nano
                  └── MFRC522 (SPI)
                       SS → D10, SCK → D13, MOSI → D11, MISO → D12, RST → D9
                       (Arduino SPI pins are different from ESP32)
```

Note: If using Arduino Nano, the wiring is different from the ESP32 node. Only the ESP32 version uses the firmware in `station_writer/station_writer.ino`.

---

## Step 1 — Generate the Master Key (ONE TIME ONLY)

**This must be done before flashing any node or issuing any card. Do it exactly once.**

```bash
python3 -c "
import secrets
bs = secrets.token_bytes(32)
print('C array (for secrets.h and secrets_station.h):')
print('  ' + ', '.join(f'0x{b:02X}' for b in bs))
print()
print('Python hex (for secrets.py):')
print('  ' + bs.hex())
"
```

Output example:
```
C array (for secrets.h and secrets_station.h):
  0xA1, 0x3F, 0x88, ..., 0x5C

Python hex (for secrets.py):
  a13f88...5c
```

**Store the output securely (password manager, printed in sealed envelope, etc.). This key is irreplaceable — losing it means all existing cards must be replaced.**

---

## Step 2 — Flash the Station Writer Firmware

```bash
# In Arduino IDE:
# 1. Open apps/kiosk_station/station_writer/station_writer.ino
# 2. Copy station_writer/secrets_station.h.template to station_writer/secrets_station.h
# 3. Fill in the master key bytes in secrets_station.h
# 4. Select board: ESP32 Dev Module (or Arduino Nano if using that)
# 5. Upload
```

In `secrets_station.h`:
```cpp
static const uint8_t MASTER_KEY[32] = {
    0xA1, 0x3F, 0x88, 0x...,  // fill in from generation step
    ...
};
```

**Verify firmware is correct:** Open Serial Monitor at 115200 baud. Should print:
```
MMS_WRITER_READY
```

If it prints:
```
FATAL: MASTER_KEY is all zeros in secrets_station.h
```
The template was not filled in. Fill in the actual key bytes and re-flash.

---

## Step 3 — Set Up the Python Kiosk App

```bash
cd apps/kiosk_station

# Copy secrets template
cp secrets.py.template secrets.py
nano secrets.py
```

In `secrets.py`:
```python
MASTER_KEY = bytes.fromhex("a13f88...5c")  # 64 hex chars = 32 bytes
```

```bash
# Install dependencies
pip install flask firebase-admin pyserial

# Or use requirements.txt:
pip install -r requirements.txt

# Set Firebase credentials
export GOOGLE_APPLICATION_CREDENTIALS=/path/to/service-account.json
```

---

## Step 4 — Configure the Port

```bash
# Find the serial port the station writer is on
# Linux:
ls /dev/tty*
# Look for /dev/ttyUSB0 or /dev/ttyACM0

# Mac:
ls /dev/cu.*
# Look for /dev/cu.SLAB_USBtoUART or /dev/cu.usbserial-...
```

In `apps/apps/kiosk_station/config.py`:
```python
RFID_PORT = "/dev/ttyUSB0"  # change to match your port
```

---

## Step 5 — Start the Kiosk App

```bash
cd apps/kiosk_station
python3 app.py

# Expected output:
# * Running on http://127.0.0.1:5000
# * Running on http://192.168.X.X:5000
```

Open a browser and go to `http://localhost:5000`.

---

## Card Issuance Workflow

### Issuing a new card

1. Admin creates the student in the web app first (see Section 09 Step 5)
   - This creates `/users/{roll_number}` in Firestore
2. Open kiosk at `http://localhost:5000`
3. Select the student's roll number from the dropdown
4. Confirm machine permissions shown match what was set in web app
5. Click "Issue Card"
6. The app says "AWAITING_CARD — place card on reader"
7. Place a **blank** MIFARE Classic 1K card on the MFRC522
8. Wait for "WRITE_SUCCESS"
9. The kiosk updates Firestore: `/users/{roll_number}` gets `card_uid`, `issued_at`

**Verify:** Take the card to any machine node. Insert it. The OLED should show the student's roll number and grant access (for permitted machines).

### Re-issuing a card (lost/replacement)

1. First, revoke the old card:
   - Web app → User Management → select student → Revoke Card
   - This creates `/revoked/{old_uid}` in Firestore
   - Bridge pushes updated revocation list to all nodes
2. At kiosk: issue a new card (same procedure as new card)
   - The new UID generates a new (different) sector key
   - Old card will be denied even if someone finds it

### Card replacement (damaged, not lost)

If the card was damaged but not stolen:
1. Read the old card UID: at kiosk, place old card → "Read UID" button
2. No need to revoke (the physical card is destroyed)
3. Issue a new card normally

---

## PIN Reset Workflow

If a student forgets their PIN:
1. Admin in web app → User Management → select student → "Reset PIN"
2. Admin enters a new 4-digit PIN
3. Web app computes new PIN hash via `hashPin()` in `src/lib/firebase.ts`
4. Updates `/users/{roll_number}.pin_hash`
5. The student must get a **new card issued** — the PIN hash is stored on the physical card
   - Existing card still has old PIN hash; it can be used for machine access (PIN not verified at machine in V2)
   - New card will have the new PIN hash (needed for kiosk login only)

---

## Failure Recovery Procedures

### "WRITE_FAILED" response
```
Causes:
1. Card was moved during write (authentication loss between blocks)
2. Card is not MIFARE Classic 1K (NFC tags, bank cards, transit cards don't work)
3. Card was previously written with different master key (sector auth fails)
4. Serial disconnect between Flask app and station writer during operation

Recovery:
1. Try the same card again — if card was moved, retry often works
2. Use a different card from the stack
3. If card is from another system, discard it
4. Restart station_writer Arduino, restart Flask app, retry
```

### "UID_MISMATCH" response
```
Cause: Flask app computed bitmask for a specific UID, but a different card was placed.
Recovery: Remove the card, click "Issue Card" again, place the correct card.
```

### Station writer not responding (no serial output)
```
1. Unplug and replug USB cable
2. Check Serial Monitor: should show "MMS_WRITER_READY" on connect
3. If not: re-flash station_writer.ino
4. Check RFID_PORT in config.py matches actual port
```

### Flask app can't connect to Firebase
```
1. Check GOOGLE_APPLICATION_CREDENTIALS is set and file exists
2. Check internet connectivity on kiosk machine
3. Check service account has Firestore read/write permissions
```

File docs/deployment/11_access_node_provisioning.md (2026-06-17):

# Section 11 — Access Node Provisioning

← [Card Issuing Station](10_card_issuing_station.md) | → [Integration Testing](12_integration_testing.md)

---

## What Provisioning Means

"Provisioning" means configuring a validated ESP32 node with its unique identity and secrets, then flashing the production firmware. After provisioning, the node:

- Knows its machine ID (which machine it controls)
- Knows the lab's master key (for RFID sector key derivation)
- Can connect to WiFi and the MQTT broker
- Will receive its full config (session limit, relay type, machine name) from the bridge on first connection

Provisioning is done once per node. If the master key ever changes, all nodes must be re-provisioned.

---

## Prerequisites

Before provisioning any node:
- [ ] Hardware validation passed (Section 06)
- [ ] RPi is running Mosquitto and bridge.py (Section 07)
- [ ] Firebase is set up and machines collection is seeded (Section 08)
- [ ] Master key has been generated (Section 10, Step 1)
- [ ] You know which machine ID this node corresponds to (Section 04)

---

## Step 1 — Prepare secrets.h

In the Arduino IDE, the `secrets.h` file is opened separately per node. Each node gets the same master key but a unique `MACHINE_ID`.

```bash
# From repo root:
cp firmware/access_node/secrets.h.template firmware/access_node/secrets.h
```

Edit `firmware/access_node/secrets.h`:
```cpp
// WiFi
#define WIFI_SSID     "tlmms"
#define WIFI_PASSWORD "your_wifi_password_here"

// MQTT
#define MQTT_BROKER   "192.168.0.10"   // RPi IP — must match static IP from Section 07
#define MQTT_PORT     1883

// Master key — 32 bytes, same for ALL nodes in the lab
static const uint8_t MASTER_KEY[32] = {
    0xA1, 0x3F, 0x88, ...,   // fill in from master key generation
};
```

**Do not commit this file.** It is in `.gitignore`. Do not create it until you are at the node and ready to flash.

---

## Step 2 — Set Machine ID in config.h

```bash
# Edit firmware/access_node/config.h
```

Find and update:
```cpp
#define MACHINE_ID    1          // ← Change this for each node (1–5)
#define MACHINE_NAME  "Creality 3D Printer"  // ← Change to match
```

**Canonical machine table — use exactly these values:**

| MACHINE_ID | MACHINE_NAME |
|---|---|
| 1 | Creality 3D Printer |
| 2 | Fracktal Laser Cutter |
| 3 | Soldering Station 1 |
| 4 | Soldering Station 2 |
| 5 | Bosche Grinder |

**Important:** The name here is only a fallback. After first MQTT connect, the bridge pushes the name from Firestore and the node updates NVS. But until that first connection, this is what shows on the OLED.

---

## Step 3 — Build and Flash

In Arduino IDE:
1. Open `firmware/access_node/access_node.ino`
2. Verify board settings:
   - Board: `ESP32 Dev Module`
   - Partition Scheme: **`Huge APP (3MB No OTA/1MB SPIFFS)`** ← production firmware; use the OTA partition scheme if OTA is needed: `Default 4MB with spiffs`
   - Upload Speed: `921600`
   - CPU Frequency: `240MHz`
3. Click **Verify** first (Ctrl+R) — confirm no compile errors
4. Connect USB cable to the node
5. Click **Upload** (Ctrl+U)

Expected output at the end of upload:
```
Leaving...
Hard resetting via RTS pin...
```

---

## Step 4 — Open Serial Monitor and Verify Boot

Baud rate: **115200**

Expected output within 5 seconds:
```
MMS V2 Access Node
Machine ID: 1 (Creality 3D Printer)
FW: 2.0.0

[HW] Relay init — GPIO 26 LOW before OUTPUT
[HW] MFRC522 SPI init OK
[HW] OLED 128x64 SPI init OK
[HW] OLED 128x32 I2C init OK
[HW] HC89 slot sensor init — GPIO 32 INPUT_PULLUP
[HW] LittleFS mounted OK (used 0 bytes / 196608 bytes)
[HW] WS2812 init OK

[NET] Connecting to WiFi tlmms ...
[NET] WiFi connected — IP: 192.168.0.101, RSSI: -52 dBm
[NET] NTP synced — 14:32:11 IST

[MQTT] Connecting to 192.168.0.10:1883 ...
[MQTT] Connected — client ID: mms_node_1
[MQTT] Subscribed: mms/nodes/1/command
[MQTT] Subscribed: mms/nodes/1/config
[MQTT] Subscribed: mms/all/revoked
[MQTT] Published status: {state:"idle", fw:"2.0.0", ip:"192.168.0.101"}
[MQTT] Received config: {name:"Creality 3D Printer", session_limit:60, relay_active_high:1, machine_active:1}
[NVS] Config saved to NVS

[SYS] Watchdog started — 30s timeout
[SYS] IDLE — tap card to begin
```

### If WiFi fails:
```
[NET] WiFi failed after 10s — proceeding offline
```
The node will still work for access control. Sessions are logged to LittleFS and flushed when WiFi/MQTT reconnects.

### If MQTT fails:
```
[MQTT] Connection failed (rc=-2) — will retry in 5s
```
Retry is automatic. Node still operates offline.

---

## Step 5 — Verify OLED Displays

Check the physical node:

**128×64 OLED (primary):**
```
┌─────────────────────┐
│   Tinkerers' Lab    │
│     IIT Indore      │
│                     │
│  Creality 3D Printer│
│                     │
│  Tap card to start  │
└─────────────────────┘
```

**128×32 OLED (status strip):**
```
[WiFi●] [MQTT●]  CREALITY 3D PR  14:32
```
WiFi and MQTT dots should be filled (connected).

**WS2812 LED:**
Should be slowly breathing white (IDLE state).

---

## Step 6 — Verify Card Access

Use a card that was issued via the kiosk (Section 10) with permission bit 0 set (machine ID 1).

1. Insert the card into the HC89 slot
2. Watch serial output:
```
[HC89] Card present
[RFID] UID: A1B2C3D4
[RFID] Deriving sector key for UID: A1B2C3D4
[RFID] Auth Sector 1 OK
[RFID] Block 4 read: roll=220002123, schema=0x02
[RFID] Block 5 read: pin_hash=aabbccdd..., perm_mask=0x0000001
[ACCESS] Revocation check — UID A1B2C3D4 not revoked
[ACCESS] Permission check — bit 0 = 1 — GRANTED
[RELAY] ON (active HIGH)
[SESSION] Started: roll=220002123, machine=1, limit=60min
[MQTT] Published status: {state:"active", roll:"220002123"}
```

3. Remove the card:
```
[HC89] Card absent
[RELAY] OFF
[SESSION] Ended: duration=45s, reason=card_removed
[MQTT] Published event: {ts:..., roll:"220002123", m:1, e:"session_end", d:45, er:"card_removed"}
[FS] Log appended: sessions.jsonl
```

4. Check Firebase Console → Firestore → sessions → confirm a new document appeared

---

## Step 7 — Verify Denial for Wrong Machine

Use the same card on a node where that card does NOT have permission (e.g., if machine_permissions=1, test on machine ID 2):
```
[ACCESS] Permission check — bit 1 = 0 — DENIED
[RELAY] stays OFF
```
OLED should show "Access Denied" and the reason.

---

## Step 8 — Verify Offline Operation

1. On the RPi, stop the bridge: `sudo systemctl stop mms-bridge`
2. On the node, observe serial — MQTT will show "Connection failed" retries
3. Insert a permitted card
4. Access should still be granted (offline mode)
5. Session is logged to LittleFS
6. Restart bridge: `sudo systemctl start mms-bridge`
7. Watch serial — node reconnects to MQTT
8. Buffered log is flushed:
```
[FS] Flushing 1 events from LittleFS
[MQTT] Published event (from cache): ...
[FS] Log cleared after flush
```
9. Check Firestore — the offline session should now appear

---
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

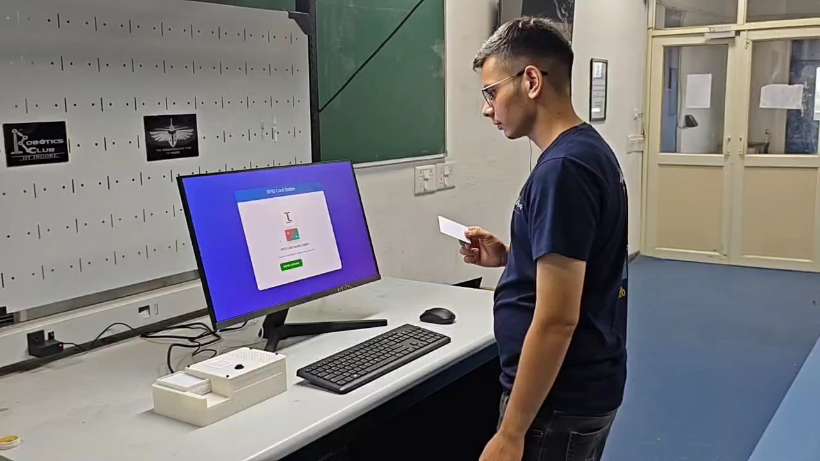
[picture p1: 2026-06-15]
docs/handbook/figures/photo_kiosk.jpeg

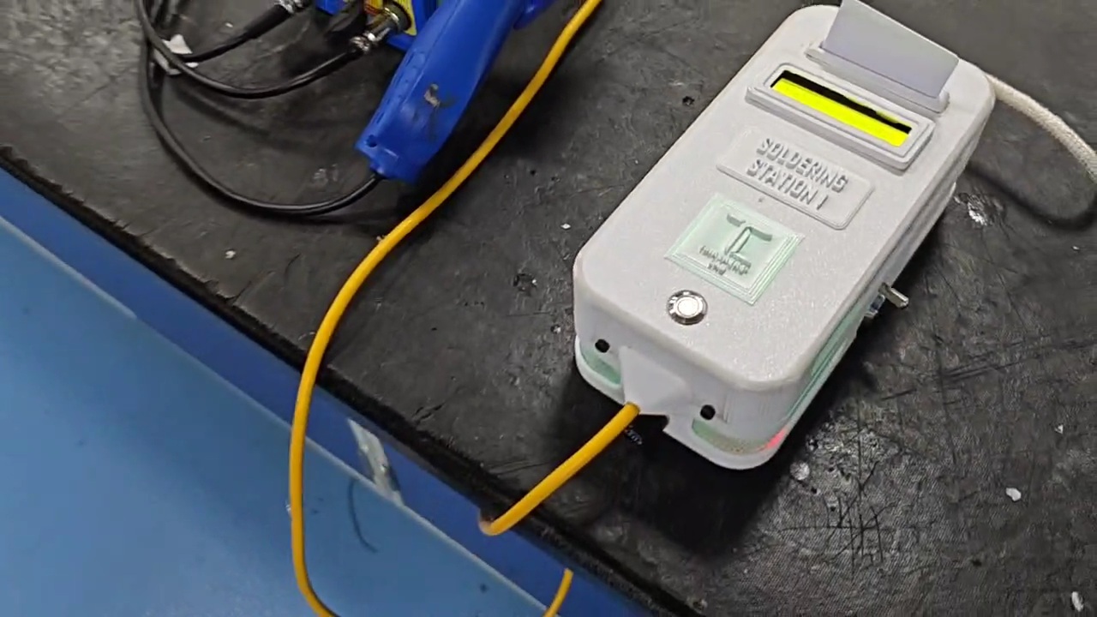
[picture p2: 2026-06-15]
docs/handbook/figures/photo_node_closeup.jpeg

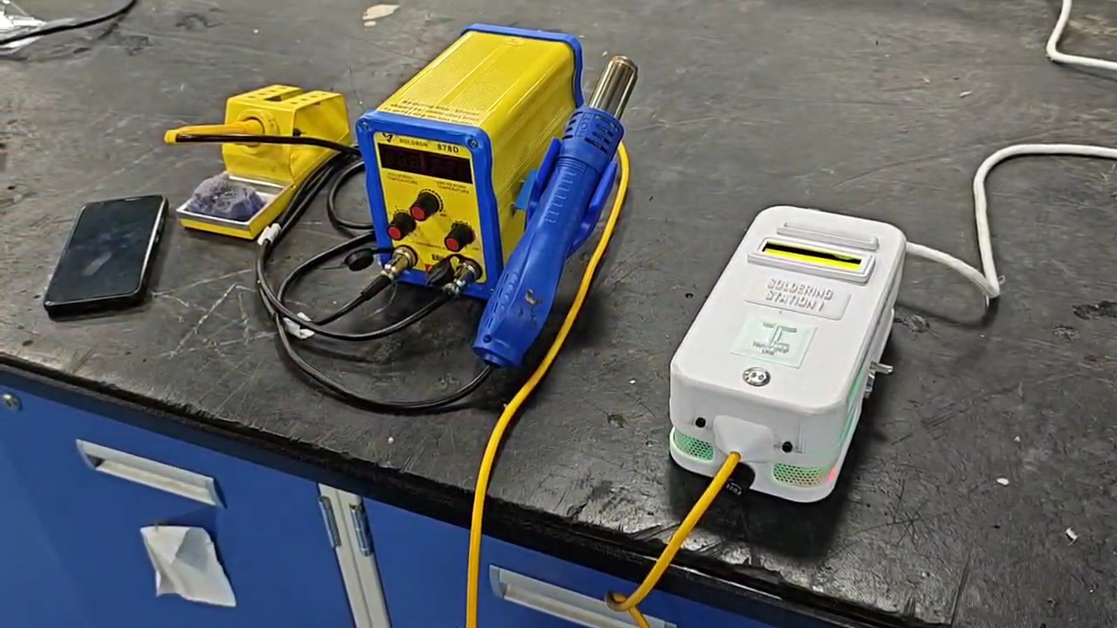
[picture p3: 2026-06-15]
docs/handbook/figures/photo_node_deployed.jpeg

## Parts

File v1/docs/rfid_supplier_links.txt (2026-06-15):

https://shop2india.com/products/sonoff-pow-elite-intelligent-electricity-statistics-current-power-metering-switch-16a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

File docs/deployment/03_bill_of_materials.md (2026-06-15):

# Section 03 — Bill of Materials

← [System Architecture](02_system_architecture.md) | → [Machine Registry](04_machine_registry.md)

---

## Why This Section Exists

Every component listed here has a specific reason for existing and cannot be simply swapped for a "similar looking" part without risk. This section documents what to buy, why, and where.

**Critical notes before ordering:**
- The MFRC522 must be the **SPI version** (7-pin), not the I2C version
- OLEDs: one is **SPI 128×64** (7-pin), the other is **I2C 128×32** (4-pin) — they are different
- WS2812 must be **5V powered** — 3.3V will cause colour errors and insufficient brightness
- ESP32 must be **38-pin NodeMCU** variant — 30-pin or WROOM without breadboard headers will not fit the pin assignments in firmware

---

## BOM — Per Node

*Quantity for a 15-machine deployment assumes 15 nodes + 10% spare (17 total for critical parts).*

| # | Component | Purpose | Qty/Node | Qty (15 nodes) | Qty (+ spare) |
|---|---|---|---|---|---|
| 1 | ESP32 NodeMCU 38-pin | Main controller | 1 | 15 | 17 |
| 2 | MFRC522 RFID module (SPI) | Card reading | 1 | 15 | 17 |
| 3 | HC89 Optical slot sensor | Card presence detection | 1 | 15 | 17 |
| 4 | SSD1306 128×64 OLED — SPI (7-pin) | Primary display | 1 | 15 | 17 |
| 5 | SSD1306 128×32 OLED — I2C (4-pin) | Status strip display | 1 | 15 | 17 |
| 6 | Single-channel 5V relay module | Machine power control (inductive loads) | 1 | 15 | 17 |
| 7 | Solid State Relay (SSR) 25A | Machine power control (resistive/heating) | 0–1 | 0–15 | As needed |
| 8 | WS2812B LED (1 pixel or ring) | Visual state indicator | 1 | 15 | 20 |
| 9 | HiLink HLK-PM01 (5V 3W) | 240V AC → 5V DC PSU | 1 | 15 | 17 |
| 10 | Rotary Encoder EC11 | PIN entry (Phase 4 only) | 0 | 0 | 0 |
| 11 | 470Ω resistor (1/4W) | WS2812 data line protection | 1 | 15 | 30 |
| 12 | 10kΩ resistor (1/4W) | Encoder CLK/DT pull-ups (Phase 4) | 0 | 0 | 0 |
| 13 | 100µF 10V electrolytic cap | WS2812 VCC decoupling | 1 | 15 | 20 |
| 14 | 10µF 10V electrolytic cap | General decoupling on 3.3V rail | 2 | 30 | 40 |
| 15 | Project enclosure (ABS, ~160×120×60mm) | Weatherproof housing | 1 | 15 | 16 |
| 16 | PCB / Perfboard (70×50mm min) | Component mounting | 1 | 15 | 17 |
| 17 | 2.54mm pin headers (male, 40-pin strip) | ESP32 socket | 2 strips | 30 | 35 |
| 18 | 2.54mm female header sockets | ESP32 socketing | 2 strips | 30 | 35 |
| 19 | JST-XH 2.54mm 2-pin connector pair | Relay output terminals | 2 | 30 | 35 |
| 20 | JST-PH 2.0mm 4-pin connector (or screw terminal) | RFID module connection | 1 | 15 | 17 |
| 21 | 3.5mm 2-pin screw terminal block | AC input / machine power output | 2 | 30 | 35 |
| 22 | 5A inline fuse + holder | AC protection | 1 | 15 | 20 |
| 23 | 22AWG silicone hookup wire (red/black/other, 5m) | Internal wiring | 5m | 75m | 90m |
| 24 | Velcro or M3 standoffs | ESP32 mounting inside enclosure | 4 | 60 | 70 |
| 25 | M3×10 screws + nuts | Enclosure assembly | 8 | 120 | 140 |
| 26 | Cable gland PG9 (or similar) | AC cable entry weatherproofing | 2 | 30 | 35 |
| 27 | Heat shrink tubing assorted | Wire insulation | — | 1 pack | 1 pack |
| 28 | Multimeter | Testing (shared tool) | — | 1 | 1 |

---

## Infrastructure Components (Lab-Wide, Not Per Node)

| # | Component | Purpose | Qty | Notes |
|---|---|---|---|---|
| I1 | Raspberry Pi 4 Model B (2GB) | MQTT broker + Firebase bridge | 1 | RPi 3B+ also works |
| I2 | RPi official power supply (5.1V 3A USB-C) | Reliable RPi power | 1 | Do not use phone charger |
| I3 | MicroSD card 32GB Class 10 | RPi OS + logs | 1 | Samsung or SanDisk Pro |
| I4 | Ethernet cable Cat5e | RPi to router (static IP) | 1m | WiFi on RPi is unreliable for a broker |
| I5 | Network router with DHCP + static IP reservation | Lab LAN | 1 | Existing lab router |
| I6 | 2.4 GHz WiFi AP | ESP32 connectivity | 1 | Existing lab AP; ensure 2.4 GHz band enabled |

---

## Card Issuing Station (Kiosk) Components

| # | Component | Purpose | Qty |
|---|---|---|---|
| K1 | Laptop or Raspberry Pi | Runs Flask kiosk app | 1 |
| K2 | MFRC522 RFID module (same as node) | Reads and writes student cards | 1 |
| K3 | USB-to-serial FTDI/CP2102 + Arduino Nano (or ESP32) | Bridge between Python and MFRC522 | 1 |
| K4 | MIFARE Classic 1K cards (white, printable) | Student cards | 400 (for 300 students + spares) |

---

## Detailed Component Notes

### ESP32 NodeMCU 38-pin

**Why this exact variant:** The 38-pin form factor provides access to GPIO 34/35 (input-only pins used for encoder), GPIO 25/26/27, and 3V3/GND rails on both sides of the board. 30-pin variants lack these.

**Supplier:** Robocraze, Robu.in, Amazon India
**Alternative:** ESP32 DevKit V1 38-pin (different silkscreen, identical pinout)
**Estimated cost:** ₹350–400 each

**What to check when receiving:**
- Count pins: 19 per side = 38 total
- Confirm USB-to-serial chip (CP2102 or CH340) is present
- Upload a blink sketch before assembly to confirm functionality

---

### MFRC522 RFID Module

**Why SPI version:** The firmware uses the Arduino MFRC522 library which requires SPI. I2C versions use a different library and the pin assignments in `config.h` are for SPI.

**Critical:** Run at 3.3V — **NOT 5V**. Connecting VCC to 5V may work temporarily but can damage the chip.

**Connector labels on module:** VCC, GND, RST, IRQ (unused), MISO, MOSI, SCK, SDA (= SS/CS)

**Supplier:** Robocraze, Amazon India
**Estimated cost:** ₹180–250 each

**What to check:**
- Run Test 02 from hardware validation suite — `VersionReg` should read `0x91` or `0x92`
- Many cheap clones return wrong VersionReg but still function — confirm with actual card tap

---

### HC89 Optical Slot Sensor

**Why not a direct RFID tap?** A slot sensor requires the card to be physically held in the slot. This is the only way to cleanly detect "card removed" (end of session). Without it, the system cannot know when the student has finished.

**Output logic:** OUT = LOW when card in slot (beam blocked), HIGH when empty. Firmware uses `INPUT_PULLUP` on GPIO 32.

**Supplier:** Robu.in, AliExpress
**Alternative:** Any IR slotted optical sensor with TTL output compatible with 3.3V
**Estimated cost:** ₹80–150 each

---

### SSD1306 128×64 OLED (SPI, 7-pin)

**Why 7-pin SPI version:** The firmware uses Adafruit SSD1306 SPI constructor with DC, CS, and RST pins. The I2C 4-pin version uses a different constructor and different GPIO pins.

**Pin labels (7-pin SPI):** GND, VCC, D0(CLK), D1(MOSI), RES(RST), DC, CS

**Supplier:** Robocraze, Amazon India
**Estimated cost:** ₹250–350 each

---

### SSD1306 128×32 OLED (I2C, 4-pin)

**Why 128×32?** This display is used as an always-visible status strip at the bottom of the enclosure showing WiFi/MQTT status, machine name, and time. The narrower height (32px vs 64px) fits a horizontal strip layout.

**Pin labels:** GND, VCC, SCL, SDA
**I2C address:** 0x3C (default; 0x3D if address jumper is bridged)

**Supplier:** Robocraze, Amazon India
**Estimated cost:** ₹200–280 each

---

### Mechanical Relay Module (5V single-channel)

**When to use:** For machines with inductive loads (motors, solenoids) or where switching clicks are acceptable (soldering stations, grinder). The relay is galvanically isolated — the 5V control circuit is completely separate from the mains circuit.

**Relay polarity:** Most optocoupler-based blue relay modules are active HIGH (IN HIGH = relay ON). Some bare relay modules are active LOW. The firmware reads `relay_active_high` from NVS; this is set via MQTT config push.

**Safety:** ALWAYS ensure relay contacts are rated higher than the machine's actual load (current × voltage). Use a 10A relay for a 5A machine as minimum safety margin.

**Supplier:** Robocraze, Amazon India
**Estimated cost:** ₹120–180 each

---

### Solid State Relay (SSR)

**When to use:** For purely resistive heating loads (hot air guns, soldering irons with no motor), where silent operation is required, or where the machine is switched very frequently.

**SSR type:** Use DC-controlled AC output SSR (e.g., Fotek SSR-25 DA). Control input: 3–32V DC (GPIO 3.3V drives directly — no extra components needed). Load output: 24–380V AC.

**Known limitation:** SSRs have off-state leakage (1–3V on load terminals). This is normal and does not mean the SSR is stuck on. Do not use SSR for machines sensitive to leakage current.

**Estimated cost:** ₹350–600 each

---

### HiLink HLK-PM01 (5V 3W)

**Why this PSU:** The HiLink series is a certified, compact PCB-mount AC-to-DC converter. It fits inside the enclosure and eliminates the need for an external wall adapter. Output: 5V 600mA (3W).

**Power budget per node:**
- ESP32: ~250mA peak (WiFi active)
- OLED 64 + 32: ~25mA each
- WS2812: ~60mA peak
- MFRC522: ~50mA
- Total: ~410mA peak → HLK-PM01 at 600mA provides 190mA headroom

**Safety:** The HiLink module handles AC mains. Enclose it in a non-conductive housing. Do not touch while mains is connected. Add a 5A fuse on the AC input.

**Supplier:** Robu.in, Amazon India
**Estimated cost:** ₹280–400 each

---

### WS2812B LED

**5V power is mandatory.** 3.3V operation causes dim, colour-inaccurate LEDs. The 100µF capacitor across VCC-GND prevents the initial power surge from damaging the IC. The 470Ω series resistor on the data line suppresses ringing on long wires.

**Byte order:** Default is `NEO_GRB`. If colours appear wrong (red = green), change to `NEO_RGB` in `led_controller.cpp`.

**Supplier:** Robocraze, Amazon India
**Estimated cost:** ₹50–120 per LED/ring

---

## Cost Estimate Summary (15 Nodes)

| Category | Estimated Cost (INR) |
|---|---|
| ESP32 × 17 | ₹6,300 |
| MFRC522 × 17 | ₹3,800 |
| HC89 × 17 | ₹2,200 |
| OLED 64 SPI × 17 | ₹5,100 |
| OLED 32 I2C × 17 | ₹4,300 |
| Relay modules × 17 | ₹2,600 |
| HiLink PSU × 17 | ₹5,800 |
| WS2812 × 20 | ₹1,600 |
| Enclosures × 15 | ₹6,000 |
| Passives (resistors, caps, wire, connectors) | ₹3,000 |
| Raspberry Pi 4 + accessories | ₹4,500 |
| MIFARE cards × 400 | ₹5,000 |
| Kiosk hardware | ₹2,000 |
| **Total estimate** | **~₹52,200** |

*Prices as of 2024. Add 15% for shipping/GST. Add 10% contingency buffer.*

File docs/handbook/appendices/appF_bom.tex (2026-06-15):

%% Appendix F — Bill of Materials
\chapter{Bill of Materials}
\label{app:bom}

\section{Per-Node Components}

The following table lists all components required for one access node.

\begin{longtable}{C{0.5cm}L{4.5cm}C{1.5cm}L{3cm}L{4cm}}
\toprule
\textbf{\#} & \textbf{Component} & \textbf{Qty} & \textbf{Approx. Cost} & \textbf{Notes} \\
\midrule
\endhead
1  & ESP32 NodeMCU 38-pin Dev Board & 1 & Rs.350  & Must be 38-pin variant; 30-pin has different GPIO layout \\
2  & MFRC522 RFID Reader Module     & 1 & Rs.150  & 3.3V; comes with card and key fob \\
3  & SSD1306 OLED 128$\times$64 SPI  & 1 & Rs.200  & 7-pin; white display recommended \\
4  & SSD1306 OLED 128$\times$32 I2C  & 1 & Rs.150  & 4-pin; I2C address 0x3C \\
5  & HC89 IR Slot Sensor            & 1 & Rs.80   & Slot width must accept MIFARE card thickness \\
6  & 5V Relay Module (single channel) & 1 & Rs.80  & With optocoupler; for soldering station / grinder \\
7  & SSR 25A (Solid State Relay)    & 1 & Rs.350  & For laser cutter; rated for inductive load \\
8  & WS2812B RGB LED (5V)           & 1 & Rs.30   & Single LED; strip cut to 1 unit \\
9  & HiLink HLK-PM01 (5V 1W)       & 1 & Rs.220  & AC-DC converter; 90-264V in, 5V/600mA out \\
10 & 470$\Omega$ resistor            & 1 & Rs.2    & For WS2812 data line; 1/4W \\
11 & 100µF 16V electrolytic capacitor & 1 & Rs.5  & For WS2812 power supply filtering \\
12 & 10k$\Omega$ resistor            & 2 & Rs.2    & For encoder CLK and DT pull-up \\
13 & EC11 Rotary Encoder            & 1 & Rs.60   & With push button; 20 detents per revolution \\
14 & ABS project enclosure          & 1 & Rs.200  & Min 150mm × 100mm × 50mm \\
15 & Cable gland PG9 (AC in)        & 1 & Rs.20   & For mains cable entry \\
16 & Cable gland PG7 (machine out)  & 1 & Rs.20   & For relay output cable \\
17 & 3-pin screw terminal blocks    & 3 & Rs.30   & For relay, HC89, power connections \\
18 & AC fuse holder + 5A fuse       & 1 & Rs.30   & 5A; on AC input before HiLink \\
19 & 3-core mains cable (1m)        & 1 & Rs.40   & For AC input to node \\
20 & 2-core wire (1m, 1mm$^2$)      & 1 & Rs.25   & For relay output to machine \\
21 & Female dupont jumper cables (20cm) & 1 set & Rs.50 & For internal GPIO connections \\
22 & USB cable (Type-A to Micro-B)  & 1 & Rs.50   & For programming; must be data cable \\
23 & Perfboard (100mm × 80mm)       & 1 & Rs.30   & For mounting ESP32 and connectors \\
24 & M3 standoffs + screws          & 1 set & Rs.30 & For mounting boards inside enclosure \\
25 & Heat shrink tubing (assorted)  & 1 set & Rs.30 & For AC wire insulation \\
26 & Electrical tape                & 1 & Rs.30   & Secondary insulation on AC connections \\
27 & Solder + flux                  & --- & Rs.50  & For perfboard assembly \\
28 & MIFARE Classic 1K cards        & 5 & Rs.150  & Blank; for initial testing and extras \\
\midrule
& \textbf{Per-node total (estimated)} & & \textbf{Rs.2,260} & Includes relay and SSR; actual cost depends on relay type used \\
\bottomrule
\caption{Bill of Materials per Access Node}
\label{tab:bom_node}
\end{longtable}

\section{Infrastructure Components (One-time)}

\begin{table}[H]
\centering
\caption{Infrastructure Bill of Materials}
\begin{tabular}{L{5cm}C{1cm}L{3cm}L{5cm}}
\toprule
\textbf{Component} & \textbf{Qty} & \textbf{Cost} & \textbf{Notes} \\
\midrule
Raspberry Pi 4B (2GB) & 1 & Rs.4,500 & Or RPi 3B+; 1GB RAM minimum \\
Official RPi power supply (5.1V 3A) & 1 & Rs.800 & NOT a phone charger \\
MicroSD card 32GB Class 10 & 1 & Rs.500 & Samsung Endurance Pro recommended \\
Ethernet cable (2m) & 1 & Rs.100 & Cat5e or better \\
\bottomrule
\end{tabular}
\end{table}

\section{Kiosk Station Components}

\begin{table}[H]
\centering
\caption{Kiosk Station Bill of Materials}
\begin{tabular}{L{5cm}C{1cm}L{3cm}L{5cm}}
\toprule
\textbf{Component} & \textbf{Qty} & \textbf{Cost} & \textbf{Notes} \\
\midrule
Laptop / PC & 1 & Existing & Any Linux/Mac/Windows with USB \\
ESP32 NodeMCU 38-pin & 1 & Rs.350 & Dedicated to kiosk; runs station\_writer.ino \\
MFRC522 RFID Reader Module & 1 & Rs.150 & Dedicated to kiosk \\
USB cable & 1 & Rs.50 & Laptop to ESP32 \\
MIFARE Classic 1K cards (bulk) & 100 & Rs.3,000 & Initial stock for all students \\
\bottomrule
\end{tabular}
\end{table}

\section{Total Cost Estimate}

\begin{table}[H]
\centering
\caption{Total Deployment Cost Estimate (5 Nodes)}
\begin{tabular}{L{7cm}R{4cm}}
\toprule
\textbf{Item} & \textbf{Cost} \\
\midrule
5 access nodes (Rs.2,260 each) & Rs.11,300 \\
Infrastructure (RPi + accessories) & Rs.5,900 \\
Kiosk station & Rs.500 \\
MIFARE cards (100 cards) & Rs.3,000 \\
Spare components (10\% buffer) & Rs.1,500 \\
\midrule
\textbf{Total (approximate)} & \textbf{Rs.22,200} \\
\bottomrule
\end{tabular}
\end{table}

\begin{notebox}
Costs are approximate as of 2024. Prices for ESP32 boards and components vary by supplier. Robu.in, Quartzcomponents, and Probots are reliable Indian suppliers. International suppliers (AliExpress) are cheaper but have longer lead times.
\end{notebox}

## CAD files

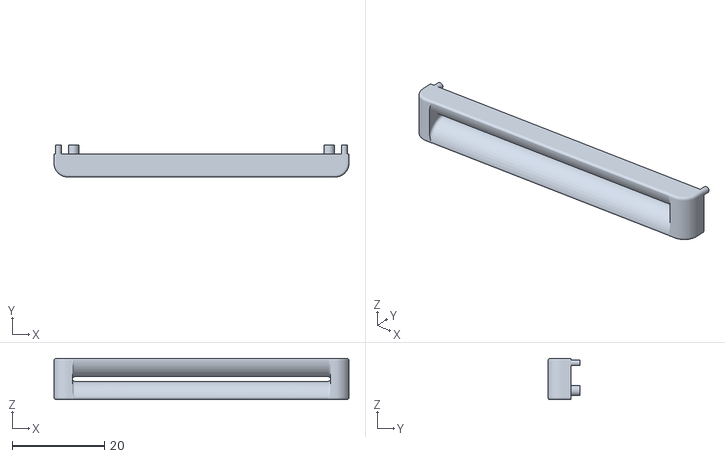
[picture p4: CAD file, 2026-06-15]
v1/access_node/cad/card_placeholder_v11.stl
64.0 x 7.00 x 9.00

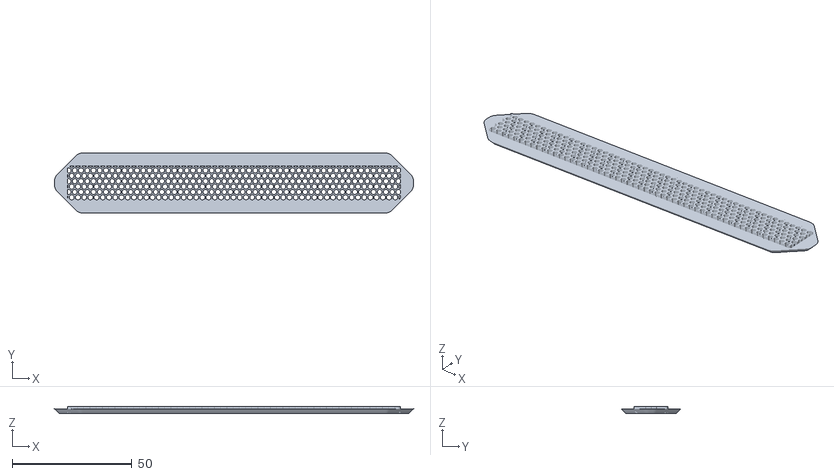
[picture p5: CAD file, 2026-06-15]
v1/access_node/cad/honeycomb_mesh_v3.stl
150.0 x 25.0 x 3.00

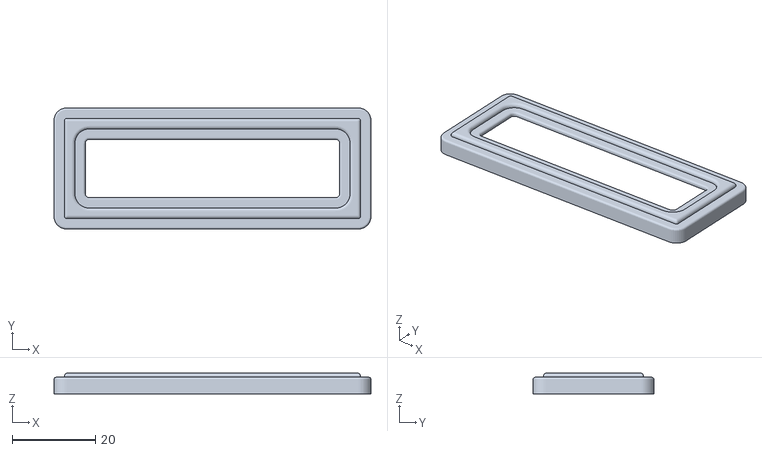
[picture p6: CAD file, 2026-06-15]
v1/access_node/cad/lcd_cover_v2.stl
76.0 x 29.0 x 5.00

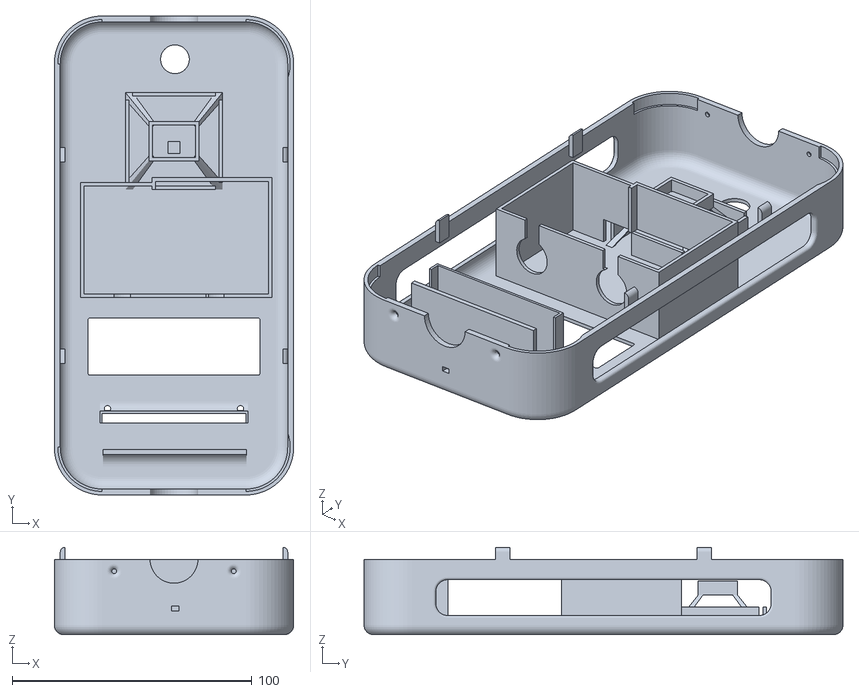
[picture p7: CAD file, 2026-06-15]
v1/access_node/cad/enclosure_top_v13_btn_v21.stl
100.0 x 200.0 x 36.5

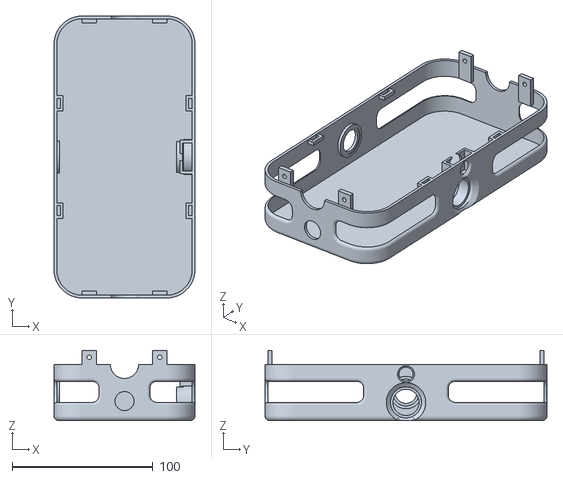
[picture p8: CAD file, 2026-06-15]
v1/access_node/cad/enclosure_bottom_v20_final.stl
100.0 x 200.0 x 50.0

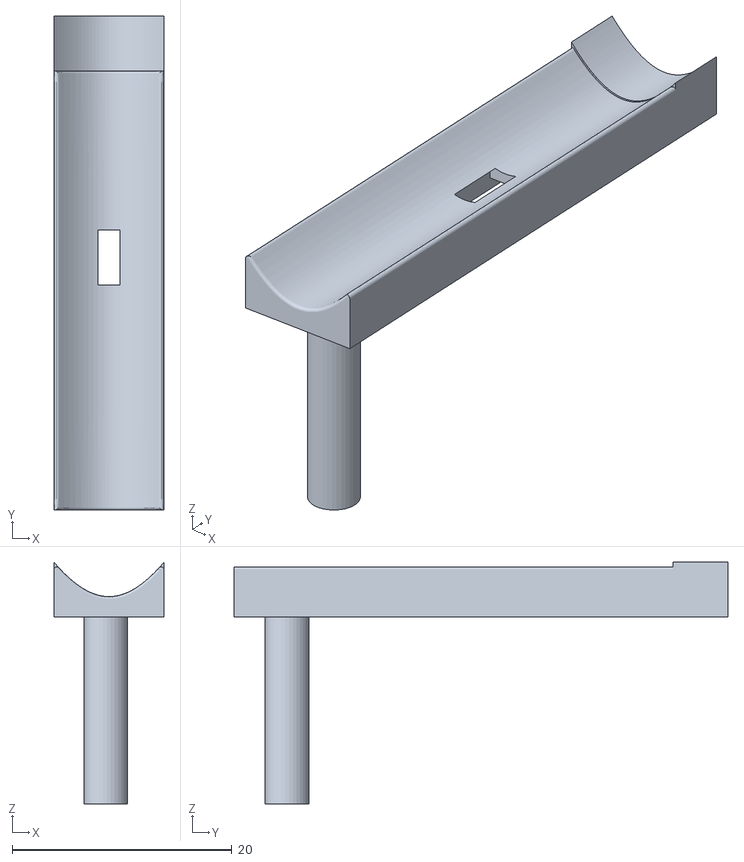
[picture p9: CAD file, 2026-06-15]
v1/access_node/cad/limit_switch_bracket.stl
10.0 x 45.0 x 22.0

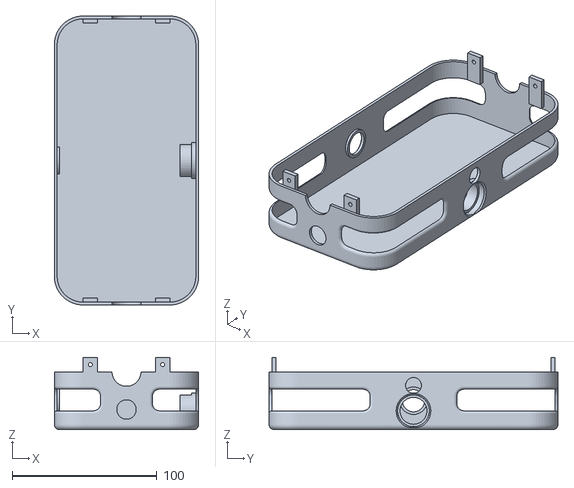
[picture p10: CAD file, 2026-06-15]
v1/access_node/cad/enclosure_bottom_v1.stl
100.0 x 200.0 x 50.0

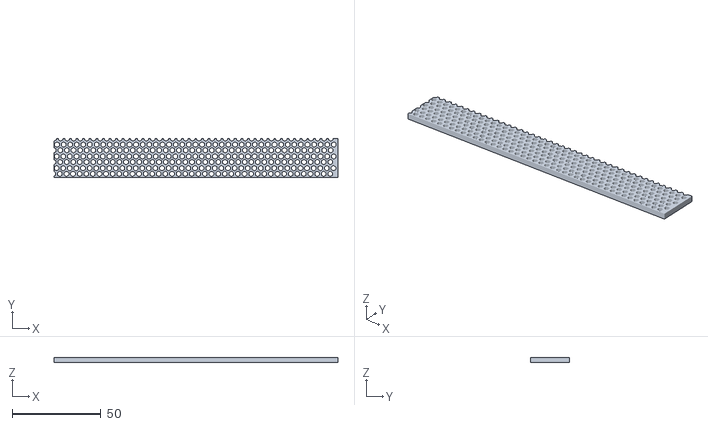
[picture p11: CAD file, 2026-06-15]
v1/access_node/cad/honeycomb_mesh.stl
160.0 x 22.0 x 3.00

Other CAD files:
v1/access_node/cad/card_placeholder_v1_25sep.stl
v1/access_node/cad/enclosure_bottom_v2_recovered.stl
v1/access_node/cad/enclosure_top_v13_btn_v21_final.stl
v1/access_node/cad/enclosure_top_v13_btn_v21_export2.stl
v1/access_node/cad/card_placeholder_v1.stl
v1/access_node/cad/card_placeholder.f3d
v1/access_node/cad/enclosure_bottom.f3d
v1/access_node/cad/enclosure_bottom_v20_final.f3d
v1/access_node/cad/enclosure_bottom_v2_recovered.f3d
v1/access_node/cad/enclosure_top_v10.f3d
v1/access_node/cad/enclosure_top_v10_13aug.f3d
v1/access_node/cad/enclosure_top_v13_btn.f3d
v1/access_node/cad/enclosure_top_v13_btn_v17.f3d
v1/access_node/cad/enclosure_top_v13_btn_v21.f3d
v1/access_node/cad/enclosure_top_v13_btn_v21_final.f3d
v1/access_node/cad/enclosure_top_v13_btn_v21_final_b.f3d
v1/access_node/cad/honeycomb_mesh.f3d
v1/access_node/cad/lcd_cover_v2.f3d
v1/access_node/cad/limit_switch_bracket.f3d

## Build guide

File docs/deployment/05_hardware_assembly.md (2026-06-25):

# Section 05 — Hardware Assembly Guide

← [Machine Registry](04_machine_registry.md) | → [Hardware Validation](06_hardware_validation.md)

---

## Before You Start

**Read the machine registry first** ([Section 04](04_machine_registry.md)). Know which machine ID this node is for before wiring anything. The relay type (mechanical vs SSR) depends on the machine.

**Safety rules:**
- Never connect AC mains while any signal wires are being worked on
- Test all 5V/3.3V DC wiring with a multimeter before first power-on
- The HiLink PSU handles 240V AC — treat it as a live shock hazard at all times
- Use a fuse on the AC input before the HiLink

**Tools required:**
- Soldering iron + solder
- Wire stripper
- Multimeter (DC voltage + continuity modes)
- Small flathead screwdriver (for screw terminals)
- USB cable for programming (keep handy for flashing)

---

## Complete Pin Mapping Table

| Signal | ESP32 GPIO | Direction | Pull resistor | Notes |
|---|---|---|---|---|
| MFRC522 SS | GPIO 5 | OUT | None | SPI chip select |
| MFRC522 RST | GPIO 27 | OUT | None | Active LOW reset |
| SPI SCK | GPIO 18 | OUT | None | Shared: RFID + OLED64 |
| SPI MISO | GPIO 19 | IN | None | Shared: RFID + OLED64 |
| SPI MOSI | GPIO 23 | OUT | None | Shared: RFID + OLED64 |
| OLED64 DC | GPIO 17 | OUT | None | Data/Command select |
| OLED64 CS | GPIO 16 | OUT | None | SPI chip select |
| OLED64 RST | GPIO 4 | OUT | None | Active LOW reset |
| OLED32 SDA | GPIO 21 | BIDIR | Built-in (device) | I2C data |
| OLED32 SCL | GPIO 22 | OUT | Built-in (device) | I2C clock |
| Relay IN | GPIO 26 | OUT | None | Firmware drives LOW before pinMode |
| HC89 OUT | GPIO 32 | IN | INPUT_PULLUP | LOW = card present |
| WS2812 DIN | GPIO 33 | OUT | None | Via 470Ω series resistor |
| Current sensor OUT | GPIO 36 | IN (analog) | None | ADC1 CH0 (SVP) — **input-only, do not drive** |
| Encoder CLK | GPIO 34 | IN | EXT 10kΩ to 3V3 | Input-only; Phase 4 |
| Encoder DT | GPIO 35 | IN | EXT 10kΩ to 3V3 | Input-only; Phase 4 |
| Encoder SW | GPIO 25 | IN | INPUT_PULLUP | Phase 4 |
| WiFi status LED | GPIO 2 | OUT | None | Onboard LED |

---

## Power Distribution

```
AC Mains (240V) ─── [Fuse 5A] ─── HiLink HLK-PM01
                                         │
                              ┌──────────┴──────────┐
                              │       5V DC          │
                              │                      │
                    ┌─────────┴──────┐    ┌──────────┴────────┐
                    │  ESP32 Vin pin  │    │  WS2812 VCC       │
                    │  (5V → 3.3V    │    │  (5V directly)    │
                    │   internal LDO)│    └───────────────────┘
                    └─────────┬──────┘
                              │  3.3V (from ESP32 3V3 pin)
                    ┌─────────┴──────────────────────────┐
                    │  MFRC522 VCC                       │
                    │  OLED64 VCC                        │
                    │  OLED32 VCC                        │
                    │  HC89 VCC                          │
                    └────────────────────────────────────┘

Relay module: 5V coil → Vin pin
              Signal: GPIO 26 (3.3V logic, relay module has optocoupler)

SSR (if used): Control INPUT+ → GPIO 26 (3.3V drives directly)
               Control INPUT- → GND
               Load terminals: in series with machine AC circuit
```

---

## Full Node Wiring Diagram

```
                          ESP32 NodeMCU 38-pin
                    ┌─────────────────────────────┐
                    │ 3V3  ○─────────────────────  │──── MFRC522 3.3V
                    │                             │──── OLED64 VCC
                    │                             │──── OLED32 VCC
                    │                             │──── HC89 VCC
                    │ GND  ○─────────────────────  │──── All GND rails
                    │ Vin  ○─────────────────────  │──── HiLink 5V+ output
                    │                             │──── WS2812 VCC
                    │                             │──── Relay VCC
                    │ GPIO 5  ○──────────────────  │──── MFRC522 SDA (SS)
                    │ GPIO 18 ○──────────────────  │──── MFRC522 SCK ─────────── OLED64 D0
                    │ GPIO 19 ○──────────────────  │──── MFRC522 MISO
                    │ GPIO 23 ○──────────────────  │──── MFRC522 MOSI ────────── OLED64 D1
                    │ GPIO 27 ○──────────────────  │──── MFRC522 RST
                    │ GPIO 17 ○──────────────────  │──── OLED64 DC
                    │ GPIO 16 ○──────────────────  │──── OLED64 CS
                    │ GPIO 4  ○──────────────────  │──── OLED64 RES
                    │ GPIO 21 ○──────────────────  │──── OLED32 SDA
                    │ GPIO 22 ○──────────────────  │──── OLED32 SCL
                    │ GPIO 26 ○──────────────────  │──── Relay IN
                    │ GPIO 32 ○──────────────────  │──── HC89 OUT
                    │ GPIO 33 ○──[470Ω]──────────  │──── WS2812 DIN
                    └─────────────────────────────┘

WS2812B LED:
  VCC → [100µF cap+] → Vin (5V)
  GND → [100µF cap-] → GND
  DIN ← 470Ω ← GPIO 33

Relay output (load circuit):
  Machine AC live wire ─── COM
  Machine power input  ─── NO (normally open)
  (When relay energised, COM connects to NO → machine receives power)

OR SSR:
  AC live ─── SSR LOAD1
  Machine ─── SSR LOAD2
  GPIO26  ─── SSR INPUT+
  GND     ─── SSR INPUT-
```

---

## MFRC522 Connection Detail

```
MFRC522 module (8 pins from left):
  Pin 1: SDA  ──── GPIO 5  (SPI chip select, labelled SS in firmware)
  Pin 2: SCK  ──── GPIO 18
  Pin 3: MOSI ──── GPIO 23
  Pin 4: MISO ──── GPIO 19
  Pin 5: IRQ  ──── NC (not connected)
  Pin 6: GND  ──── GND
  Pin 7: RST  ──── GPIO 27
  Pin 8: 3.3V ──── 3V3 (NOT 5V)
```

**Common mistake:** Many MFRC522 modules label the SPI CS pin as "SDA". This is confusing — it is not the I2C SDA pin. In the firmware it is configured as the SPI Slave Select.

---

## SPI OLED 128×64 Connection Detail

```
OLED 64 module (7 pins):
  Pin 1: GND ──── GND
  Pin 2: VCC ──── 3V3
  Pin 3: D0  ──── GPIO 18 (shared SCK with MFRC522)
  Pin 4: D1  ──── GPIO 23 (shared MOSI with MFRC522)
  Pin 5: RES ──── GPIO 4
  Pin 6: DC  ──── GPIO 17
  Pin 7: CS  ──── GPIO 16
```

**The SPI bus is shared between MFRC522 and the OLED.** This works because they have different CS/SS pins (GPIO 5 for RFID, GPIO 16 for OLED). The firmware drives these CS pins correctly — only one device sees the SPI bus at any time.

---

## I2C OLED 128×32 Connection Detail

```
OLED 32 module (4 pins):
  GND ──── GND
  VCC ──── 3V3
  SCL ──── GPIO 22
  SDA ──── GPIO 21
```

No additional pull-up resistors needed — the SSD1306 module has onboard 4.7kΩ pull-ups on SDA and SCL.

---

## Relay Module Connection Detail

```
Relay module (single channel, 5V):
  VCC  ──── Vin (5V)
  GND  ──── GND
  IN   ──── GPIO 26

Load connections (screw terminals):
  COM  ──── AC live wire from mains (via HiLink fused input)
  NO   ──── Machine power input (live wire to machine)
  NC   ──── (Not used in normal operation)
```

**Why GPIO 26 is driven LOW before `pinMode(OUTPUT)`:** The ESP32 GPIO boot state is unpredictable. By writing LOW before setting the pin as output, we guarantee the relay does not accidentally energise on power-up (which could start the machine unexpectedly). See `relay_controller.cpp` line 1: `digitalWrite(PIN_RELAY, LOW); pinMode(PIN_RELAY, OUTPUT);`

---

## HC89 Slot Sensor Connection Detail

```
HC89 (3 or 4 pins):
  VCC  ──── 3V3 (or 5V if module spec requires — check datasheet)
  GND  ──── GND
  OUT  ──── GPIO 32

Note: GPIO 32 is configured as INPUT_PULLUP.
Most HC89 modules have open-collector output and rely on this pull-up.
```

**Orientation in enclosure:** The slot opening should face outward from the enclosure so cards can be inserted. The slot width is typically 2–3mm — ensure the MIFARE card fits without force.

---

## WS2812B LED Connection Detail

```
WS2812B (strip cut to 1 LED, or ring module):
  VCC ──── [100µF electrolytic, + to VCC] ──── Vin (5V)
  GND ──── GND (also cap– to GND)
  DIN ──── [470Ω resistor] ──── GPIO 33

The 100µF capacitor is placed ACROSS the VCC–GND pins AT THE LED.
Not at the ESP32 — at the LED module itself, as close as possible.
```

**LED placement:** Mount the WS2812 so it is visible from outside the enclosure. A small hole or light-diffusing acrylic window works well.

---

## Enclosure Layout

```
Front panel (facing operator):
┌─────────────────────────────────────────────────┐
│                                                 │
│   ┌─────────────────────────────────────┐       │
│   │       128×64 SPI OLED               │       │
│   │   (primary state display)           │       │
│   └─────────────────────────────────────┘       │
│                                                 │
│        [WS2812 RGB LED indicator]               │
│                                                 │
│   ┌─────────────────────────────────────┐       │
│   │  128×32 I2C OLED (status strip)     │       │
│   └─────────────────────────────────────┘       │
│                                                 │
│   ┌──────────────────┐                          │
│   │   HC89 SLOT      │ ← card inserted here     │
│   └──────────────────┘                          │
│                                                 │
└─────────────────────────────────────────────────┘

Internal layout:
┌─────────────────────────────────────────────────┐
│  [HiLink PSU]  [Relay/SSR]  [Fuse holder]       │
│                                                 │
│  [ESP32 on perfboard/PCB]                       │
│    ├── MFRC522 (mounted behind HC89 slot)        │
│    ├── OLED 64 (front panel)                    │
│    └── OLED 32 (front panel, below OLED 64)     │
│                                                 │
│  [Cable gland: AC in]  [Cable gland: machine]   │
└─────────────────────────────────────────────────┘
```

---

## Assembly Checklist

Perform this checklist for every node before first power-on.

- [ ] All GND rails connected to common GND
- [ ] MFRC522 VCC = 3.3V (NOT 5V) — confirmed with multimeter
- [ ] ESP32 Vin = 5V from HiLink — confirmed with multimeter
- [ ] WS2812 VCC = 5V — confirmed with multimeter
- [ ] 100µF capacitor across WS2812 VCC–GND (observe polarity: + to VCC)
- [ ] 470Ω resistor in series on WS2812 DIN
- [ ] Relay IN connected to GPIO 26 (not GPIO 16 or any SPI pin)
- [ ] HC89 OUT connected to GPIO 32
- [ ] OLED64: DC=17, CS=16, RST=4 — verified against pin table
- [ ] OLED32: SDA=21, SCL=22 — verified against pin table
- [ ] MFRC522: SS=5, RST=27 — verified against pin table
- [ ] AC fuse installed and rated correctly (5A for a 600mA load)
- [ ] AC cable glands tight (no bare wire visible outside enclosure)
- [ ] ESP32 USB port accessible for firmware flashing without disassembly
- [ ] Physical card can be inserted and removed from HC89 slot freely
- [ ] Relay output terminals clearly labelled (COM, NO) on enclosure
- [ ] Current sensor OUT connected to GPIO 36 (input-only — do not apply digital drive to this pin)

**Hardware validation must pass before proceeding to node provisioning.** See [Section 06](06_hardware_validation.md).

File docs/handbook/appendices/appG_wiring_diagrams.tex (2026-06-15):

%% Appendix G — Wiring Diagrams
\chapter{Wiring Diagrams}
\label{app:wiring}

This appendix is the wiring reference for one ESP32 access node. Pin assignments must match \texttt{v2/access\_node/config.h}.

\section{Node Wiring Overview}

\begin{figure}[H]
\centering
\begin{tikzpicture}[node distance=8mm and 9mm]
\node[mmsblock, text width=34mm, minimum height=42mm] (esp) {ESP32 NodeMCU\\38-pin\\\texttt{config.h}};
\node[mmsedge, above left=of esp] (rfid) {MFRC522\\RFID\\SPI};
\node[mmsedge, above=of esp] (oled64) {128x64 OLED\\SPI};
\node[mmsedge, above right=of esp] (oled32) {128x32 OLED\\I2C};
\node[mmsedge, left=of esp] (slot) {HC89\\slot sensor};
\node[mmsedge, right=of esp] (relay) {Relay / SSR\\machine live};
\node[mmsedge, below left=of esp] (led) {WS2812\\status LED};
\node[mmsedge, below=of esp] (encoder) {EC11\\encoder};
\node[mmswarn, below right=of esp] (power) {HLK-PM01\\5V supply};
\draw[mmsline] (esp) -- node[above,font=\scriptsize]{GPIO 5,18,19,23,27} (rfid);
\draw[mmsline] (esp) -- node[right,font=\scriptsize]{GPIO 16,17,18,23,4} (oled64);
\draw[mmsline] (esp) -- node[above,font=\scriptsize]{GPIO 21,22} (oled32);
\draw[mmsline] (esp) -- node[above,font=\scriptsize]{GPIO 32} (slot);
\draw[mmsline] (esp) -- node[above,font=\scriptsize]{GPIO 26} (relay);
\draw[mmsline] (esp) -- node[below,font=\scriptsize]{GPIO 33} (led);
\draw[mmsline] (esp) -- node[right,font=\scriptsize]{GPIO 34,35,25} (encoder);
\draw[mmsline] (power) -- node[below,font=\scriptsize]{5V + 3V3 rail} (esp);
\end{tikzpicture}
\caption{Access node wiring overview}
\label{fig:wiring_overview}
\end{figure}

\section{Canonical Pin Table}

\begin{longtable}{L{3cm}L{3cm}L{3.5cm}L{5cm}}
\toprule
\textbf{Subsystem} & \textbf{Signal} & \textbf{ESP32 pin} & \textbf{Notes} \\
\midrule
\endhead
MFRC522 & SDA / SS & GPIO 5 & SPI chip select; not I2C SDA \\
MFRC522 & SCK & GPIO 18 & Shared SPI clock with OLED64 \\
MFRC522 & MISO & GPIO 19 & SPI input \\
MFRC522 & MOSI & GPIO 23 & Shared SPI MOSI with OLED64 \\
MFRC522 & RST & GPIO 27 & Active-low reset \\
OLED 128x64 & DC & GPIO 17 & SPI data/command select \\
OLED 128x64 & CS & GPIO 16 & SPI chip select \\
OLED 128x64 & RES & GPIO 4 & Active-low reset \\
OLED 128x32 & SDA & GPIO 21 & I2C data \\
OLED 128x32 & SCL & GPIO 22 & I2C clock; address \texttt{0x3C} \\
Relay / SSR & IN & GPIO 26 & Relay must default OFF at boot \\
HC89 & OUT & GPIO 32 & Card present is LOW with pull-up \\
WS2812 & DIN & GPIO 33 & Use 470~$\Omega$ series resistor \\
Encoder & CLK & GPIO 34 & Input-only; requires external 10k~$\Omega$ pull-up \\
Encoder & DT & GPIO 35 & Input-only; requires external 10k~$\Omega$ pull-up \\
Encoder & SW & GPIO 25 & Uses firmware pull-up \\
\bottomrule
\caption{Canonical access-node wiring table}
\label{tab:wiring_canonical}
\end{longtable}

\section{Power Distribution}

\begin{figure}[H]
\centering
\begin{tikzpicture}[node distance=9mm and 11mm]
\node[mmswarn] (mains) {240V AC\\fused input};
\node[mmswarn, right=of mains] (hilink) {HLK-PM01\\5V DC};
\node[mmsblock, right=of hilink] (vin) {ESP32 Vin\\internal 3V3};
\node[mmsedge, above right=of vin] (modules) {3V3 modules\\RFID, OLEDs, HC89};
\node[mmsedge, right=of vin] (relay) {5V relay\\or SSR input};
\node[mmsedge, below right=of vin] (led) {WS2812\\5V direct};
\draw[mmsline] (mains) -- node[above,font=\scriptsize]{fuse} (hilink);
\draw[mmsline] (hilink) -- node[above,font=\scriptsize]{5V} (vin);
\draw[mmsline] (vin) -- node[above,font=\scriptsize]{3V3 rail} (modules);
\draw[mmsline] (hilink) |- node[pos=0.25,above,font=\scriptsize]{5V} (relay);
\draw[mmsline] (hilink) |- node[pos=0.25,below,font=\scriptsize]{5V} (led);
\end{tikzpicture}
\caption{Power distribution}
\label{fig:power_distribution}
\end{figure}

\begin{warnbox}
Mains wiring must be performed only by someone competent to work on 240V AC equipment. The MMS relay must switch the live conductor through COM and NO terminals, and the machine must remain off when the relay is de-energised.
\end{warnbox}

\section{Interface-Specific Notes}

\begin{longtable}{L{3.5cm}L{11cm}}
\toprule
\textbf{Interface} & \textbf{Engineering note} \\
\midrule
\endhead
MFRC522 & Power only from 3.3V. Do not connect the module to 5V. \\
OLED64 SPI & Shares SCK and MOSI with MFRC522; keep separate chip-select lines. \\
OLED32 I2C & Most modules already include pull-ups; do not add unnecessary strong pull-ups. \\
WS2812 & Place a 100~$\mu$F capacitor across VCC/GND at the LED module and a 470~$\Omega$ resistor in series with data. \\
HC89 & Firmware debounces slot changes for 50 ms. Verify active-low behaviour before production installation. \\
Encoder & GPIO 34 and GPIO 35 have no internal pull-ups; external 10k~$\Omega$ resistors are mandatory. \\
Relay & Confirm \texttt{relay\_active\_high} before connecting the machine load. Test with a multimeter before energising the machine. \\
\bottomrule
\caption{Interface-specific wiring notes}
\label{tab:wiring_notes}
\end{longtable}

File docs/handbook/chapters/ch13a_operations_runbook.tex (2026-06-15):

%% Chapter 13A — Operations Runbook
\chapter{Operations Runbook}
\label{ch:operations_runbook}

This chapter defines recurring operating procedures. Print this chapter at semester handover and keep a current copy near the Raspberry Pi.

\section{New Coordinator Handover}

\begin{runbookbox}{Handover Package}
The outgoing coordinator must transfer: dashboard admin access, Firebase project owner contact, Raspberry Pi SSH access method, master key custody location, kiosk station laptop, blank card stock, last known-good firmware binary, and the latest SD card backup.
\end{runbookbox}

\begin{longtable}{L{4cm}L{7cm}L{3cm}}
\toprule
\textbf{Item} & \textbf{Acceptance check} & \textbf{Owner} \\
\midrule
\endhead
Dashboard access & New coordinator can log in and see all machines & Outgoing coordinator \\
Kiosk station & New coordinator issues one test card successfully & Outgoing coordinator \\
RPi access & New maintainer can run \texttt{systemctl status mms-bridge} & Infrastructure maintainer \\
Master key custody & Sealed backup and password-manager entry are verified, not copied casually & Faculty in charge \\
Recovery media & Latest RPi image and known-good firmware binary are readable & Technical maintainer \\
Documentation & This handbook revision is reviewed and dated & New coordinator \\
\bottomrule
\caption{Coordinator handover acceptance checklist}
\label{tab:handover}
\end{longtable}

\section{Semester Transition Checklist}

\begin{enumerate}[leftmargin=1.5em]
    \item Export current users and sessions from Firestore for archival records.
    \item Disable dashboard access for coordinators who are leaving the role.
    \item Add incoming coordinators as Firebase Auth users and Firestore admins.
    \item Count blank cards; reorder before orientation week if stock is below 50.
    \item Run one full access test on every production machine.
    \item Review revoked cards and lost-card incidents from the previous semester.
    \item Confirm the Raspberry Pi SD card backup is less than 45 days old.
    \item Confirm the master key custody record still names current responsible people.
    \item Update the approval page and revision history if the handbook changed.
\end{enumerate}

\section{Daily, Weekly, Monthly Work}

\begin{table}[H]
\centering
\caption{Operations cadence}
\begin{tabular}{L{2.5cm}L{8cm}L{3.5cm}}
\toprule
\textbf{Cadence} & \textbf{Work} & \textbf{Escalate when} \\
\midrule
Daily & Open dashboard; verify no machine is unexpectedly offline and no session is stuck active. & Any relay state disagrees with the physical machine. \\
Weekly & SSH to RPi; check disk, RAM, bridge logs, Mosquitto logs, and card stock. & Repeated bridge exceptions or disk usage above 80\%. \\
Monthly & Make SD backup, review Firebase quota, archive old sessions if needed, run one card issuance drill. & Backup cannot be restored or quota trend is abnormal. \\
Quarterly & Rotate MQTT password if authentication is enabled; review admin list and revoked cards. & Any unknown admin or unexpected credential change appears. \\
\bottomrule
\end{tabular}
\end{table}

\section{Master Key Rotation Runbook}
\label{sec:master_key_rotation}

Rotate the master key only when necessary: suspected leak, coordinator compromise, or planned migration rehearsal. Rotation invalidates every currently issued card.

\begin{enumerate}[leftmargin=1.5em]
    \item Freeze card issuance and announce a maintenance window.
    \item Generate a new 32-byte key on a trusted machine.
    \item Store the new key in the approved password manager and sealed physical backup.
    \item Update \texttt{secrets.h}, \texttt{secrets\_station.h}, and \texttt{secrets.py}.
    \item Re-flash all production nodes and the station writer.
    \item Re-issue cards for all active users.
    \item Keep old revoked-card records for audit, but mark the old key as retired.
    \item Record the rotation reason, date, and approver in the revision log.
\end{enumerate}

\section{Lost Card Procedure}

\begin{enumerate}[leftmargin=1.5em]
    \item Revoke the card immediately in the dashboard.
    \item Confirm revocation reaches all online nodes.
    \item Ask the user where the card was last seen and record the incident.
    \item Issue a replacement card with a new UID.
    \item If the lost card belonged to a coordinator or super admin, also review dashboard access.
\end{enumerate}

\section{Compromised Coordinator Procedure}

\begin{enumerate}[leftmargin=1.5em]
    \item Remove the account from Firebase Auth and Firestore admin collections.
    \item Rotate any shared passwords known to that coordinator.
    \item Review recent dashboard actions: user changes, revocations, OTA triggers, admin additions.
    \item Inspect whether master key custody was exposed. If yes, execute Section~\ref{sec:master_key_rotation}.
    \item Document the incident and the recovery actions.
\end{enumerate}

\section{Disaster Recovery Summary}

\begin{longtable}{L{3.5cm}L{5cm}L{5.5cm}}
\toprule
\textbf{Disaster} & \textbf{Immediate action} & \textbf{Recovery path} \\
\midrule
\endhead
Raspberry Pi failure & Leave nodes powered; sessions buffer locally & Restore latest SD card image or rebuild from deployment guide. \\
Firebase outage & Do not repeatedly restart nodes & Wait for service recovery; restart bridge after Firebase is healthy. \\
ESP32 node failure & Bypass only under electrical supervision & Replace module, flash production firmware, rerun validation. \\
Bad OTA & Stop further rollout & Allow rollback; manually flash failed nodes with known-good binary. \\
Lost master key & Stop issuance & Generate new key, re-flash all nodes, re-issue all cards. \\
Database corruption & Freeze manual edits & Restore machine seed data; reconstruct users from cards if needed. \\
\bottomrule
\caption{Disaster recovery decision table}
\label{tab:dr_summary}
\end{longtable}

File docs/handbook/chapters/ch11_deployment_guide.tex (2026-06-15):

%% Chapter 11 — Deployment Guide
\chapter{Deployment Guide}
\label{ch:deployment}

\section{Deployment Overview}

A complete MMS V2 deployment follows this order. Each step depends on the previous being complete.

\begin{table}[H]
\centering
\caption{Deployment Sequence}
\begin{tabular}{C{1cm}L{5cm}L{7.5cm}}
\toprule
\textbf{Step} & \textbf{Task} & \textbf{Reference} \\
\midrule
1  & Generate master key (ONCE) & Chapter~\ref{ch:deployment}, Section~\ref{sec:masterkey} \\
2  & Set up Firebase project & Deployment Package, Section 08 \\
3  & Set up Raspberry Pi & Deployment Package, Section 07 \\
4  & Deploy web application & Deployment Package, Section 09 \\
5  & Set up kiosk station & Deployment Package, Section 10 \\
6  & Assemble nodes & Chapter~\ref{ch:hardware}; Deployment Package, Section 05 \\
7  & Run hardware validation & Appendix~\ref{app:validation}; Deployment Package, Section 06 \\
8  & Provision nodes & Deployment Package, Section 11 \\
9  & Run integration tests & Deployment Package, Section 12 \\
10 & Issue cards to students & Deployment Package, Section 10 \\
11 & Pilot deployment (1 machine) & Deployment Package, Section 13 \\
12 & Full rollout (all machines) & Deployment Package, Section 13 \\
\bottomrule
\end{tabular}
\end{table}

\begin{notebox}
The full deployment package is in \texttt{v2/deployment/}. This chapter summarises the most critical steps. Refer to the deployment package for step-by-step instructions with exact commands.
\end{notebox}

\section{Master Key Generation}
\label{sec:masterkey}

The master key is a 32-byte random secret shared across all nodes and the kiosk. It must be generated exactly once, before any card is issued or any node is provisioned.

\begin{lstlisting}[style=bashstyle]
python3 -c "
import secrets
bs = secrets.token_bytes(32)
print('C array:')
print('  ' + ', '.join(f'0x{b:02X}' for b in bs))
print()
print('Python hex:')
print('  ' + bs.hex())
"
\end{lstlisting}

Store the output in:
\begin{itemize}[leftmargin=1.5em]
    \item A password manager (required)
    \item A printed copy in a sealed envelope in the lab safe (recommended)
    \item \textbf{Do not store in a shared Google Drive or any cloud storage in plaintext}
\end{itemize}

Use the C array form for \texttt{secrets.h} and \texttt{secrets\_station.h}. Use the hex form for \texttt{secrets.py}.

\begin{warnbox}
\textbf{Losing the master key means all existing cards must be replaced.} The key cannot be recovered from the cards or the firmware. If it is lost, generate a new key, re-flash all nodes, and re-issue all cards.
\end{warnbox}

\section{Node Provisioning Summary}

For each node:

\begin{enumerate}[leftmargin=1.5em]
    \item Copy \texttt{secrets.h.template} to \texttt{secrets.h}; fill in WiFi credentials and master key
    \item Set \texttt{MACHINE\_ID} and \texttt{MACHINE\_NAME} in \texttt{config.h}
    \item Flash firmware via Arduino IDE (Partition: Default 4MB with spiffs)
    \item Verify boot log on Serial Monitor (115200 baud)
    \item Confirm MQTT connect and config push from bridge
    \item Test card access: permitted card GRANTED, non-permitted card DENIED
    \item Complete provisioning checklist (Deployment Package, Section 11)
\end{enumerate}

\section{Critical Pre-Deployment Verification}

Before any node goes to a live machine, run these checks:

\begin{lstlisting}[style=bashstyle]
# 1. Bridge healthy
curl http://192.168.0.10:8080/health
# Expect: {"mqtt_connected": true, "fb_connected": true, ...}

# 2. Mosquitto reachable
mosquitto_pub -h 192.168.0.10 -t mms/test -m ping
# Expect: no error

# 3. Firestore machines seeded
firebase firestore:get /machines/1
# Expect: JSON with "Creality 3D Printer"

# 4. Web app accessible
# Open dashboard URL in browser; login; confirm 5 machines shown
\end{lstlisting}

\section{Secrets Files Reference}

\begin{table}[H]
\centering
\caption{Secret Files and Their Contents}
\begin{tabular}{L{6cm}L{8cm}}
\toprule
\textbf{File path} & \textbf{Contents} \\
\midrule
\texttt{v2/access\_node/secrets.h} & WiFi SSID/password, MQTT broker IP, master key (C array) \\
\texttt{v2/kiosk\_station/station\_writer/secrets\_station.h} & Master key (C array) \\
\texttt{v2/kiosk\_station/secrets.py} & Master key (Python hex bytes) \\
\texttt{v2/rpi\_bridge/.env} & MQTT credentials, Firebase RTDB URL \\
\texttt{v2/rpi\_bridge/service-account.json} & Firebase Admin SDK service account \\
\texttt{v2/web\_app/lab-access-nexus-main/.env} & Firebase client config (not a secret per se, but not committed) \\
\bottomrule
\end{tabular}
\end{table}

All of these are in \texttt{.gitignore}. Template files (e.g., \texttt{secrets.h.template}) are committed; actual secret files are not.

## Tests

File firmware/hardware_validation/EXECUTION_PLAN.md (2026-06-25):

# MMS V2 — Hardware Validation Execution Plan

**Audience:** Junior engineer performing first-time component validation
**Goal:** Verify every hardware component independently before running integrated firmware
**Time:** ~2.5–3 hours for all 12 tests end-to-end

---

## Before You Start

### Equipment checklist

| Item | Qty | Notes |
|---|---|---|
| ESP32 NodeMCU 38-pin | 1 | Any 38-pin variant |
| USB-A to Micro-USB cable | 1 | Must carry data, not charge-only |
| Laptop with Arduino IDE 2.x | 1 | Or VS Code + PlatformIO |
| Breadboard (830 tie-point) | 1 | |
| Jumper wires M-M | 20+ | |
| Jumper wires M-F | 10+ | For module connectors |
| Multimeter | 1 | Continuity + voltage modes |
| MFRC522 RFID module | 1 | With header pins soldered |
| MIFARE Classic 1K card | 1 | Blank or pre-used |
| HC89 slot sensor | 1 | Optical IR slot type |
| SSD1306 128×64 SPI OLED | 1 | 7-pin SPI version |
| SSD1306 128×32 I2C OLED | 1 | 4-pin I2C version |
| Mechanical relay module | 1 | Single channel, 5V coil |
| Solid State Relay (SSR) | 1 | e.g. Fotek SSR-25DA or equivalent |
| WS2812B LED (1-pixel or strip) | 1 | Pre-wired or strip cut to 1 LED |
| Rotary encoder EC11 | 1 | With push-button, breakout preferred |
| 470Ω resistor | 1 | For WS2812 data line |
| 10kΩ resistor | 2 | For encoder CLK/DT pull-ups |
| 100µF electrolytic capacitor | 1 | For WS2812 VCC decoupling |
| WiFi access point (2.4 GHz) | 1 | SSID must be "tlmms" or update define |
| Raspberry Pi with Mosquitto | 1 | Required for Test 11 only |
| Current sensor module (ACS712 or similar) | 1 | Required for Test 13 only |

### Arduino IDE setup (one-time)

1. **Add ESP32 board package**
   File → Preferences → Additional Boards Manager URLs:
   ```
   https://raw.githubusercontent.com/espressif/arduino-esp32/gh-pages/package_esp32_index.json
   ```
   Tools → Board → Boards Manager → search "esp32" → install **esp32 by Espressif Systems** (3.x)

2. **Board settings** (apply to every sketch):
   - Board: `ESP32 Dev Module`
   - Upload Speed: `921600`
   - Flash Mode: `QIO`
   - Flash Size: `4MB (32Mb)`
   - Partition Scheme: `Default 4MB with spiffs (1.2MB APP / 1.5MB SPIFFS)` — required for LittleFS Test 12
   - Port: whichever COM/ttyUSB appears when ESP32 is plugged in

3. **Install libraries** (Tools → Manage Libraries):
   | Library | Version | Tests |
   |---|---|---|
   | Adafruit SSD1306 | 2.5.x | 04, 05 |
   | Adafruit GFX Library | 1.11.x | 04, 05 |
   | MFRC522 by miguelbalboa | 1.4.x | 02 |
   | Adafruit NeoPixel | 1.12.x | 08 |
   | PubSubClient by Nick O'Leary | 2.8.x | 11 |
   | ArduinoJson | 7.x | 12 |

   Adafruit BusIO (dependency) installs automatically with SSD1306.

4. **Serial Monitor settings**: 115200 baud, line ending = None (or Newline — doesn't matter)

---

## Recommended Execution Order

Run in this sequence. Each phase uses the same wiring group, so you minimise re-wiring.

| Phase | Tests | Wiring group | Estimated time |
|---|---|---|---|
| A | 01, 12, 10 | No external wiring | 20 min |
| B | 11 | No external wiring (needs RPi) | 15 min |
| C | 05 | I2C (2 wires) | 15 min |
| D | 04, 02 | SPI (4 shared wires + extras) | 25 min |
| E | 03, 06, 07, 08 | Individual GPIO | 40 min |
| F | 09 | GPIO + external pull-ups | 20 min |
| G | 13 | 1 analog wire (GPIO 36) | 10 min |

**Total: ~2h 25m** plus time to flash each sketch (~30–60s each).

---

---

# Phase A — No External Wiring

---

## Test 01 — ESP32 System

**Hardware required:** ESP32, USB cable
**Hardware optional:** None
**Estimated time:** 10 minutes

### Wiring

```
[USB-A] ─────────────────── [ESP32 Micro-USB]
```
No breadboard wiring. USB provides power and serial.

### Required libraries
None beyond ESP32 Arduino core.

### Arduino IDE / PlatformIO setup
- Open `01_esp32_system/01_esp32_system.ino`
- Verify board = `ESP32 Dev Module`
- Upload → open Serial Monitor at 115200

### Expected serial output
```
========================================
 MMS V2 — Test 01: ESP32 System
========================================
[INFO] === Phase 1: Chip Identification ===
[INFO] Chip model  : ESP32-D0WD
[INFO] Chip cores  : 2
[INFO] Revision    : 3
[INFO] Features    : WiFi / BT / BLE
[INFO] MAC address : AA:BB:CC:DD:EE:FF
[PASS] Dual-core ESP32 detected
[INFO] CPU freq: 240 MHz
[PASS] CPU frequency >= 80 MHz

[INFO] === Phase 2: Flash Memory ===
[INFO] Flash size  : 4194304 bytes (4096 KB)
[PASS] Flash size >= 4MB

[INFO] === Phase 3: RAM / Heap ===
[INFO] Free heap   : 284312 bytes
[INFO] Min heap    : 284312 bytes
[PASS] Free heap >= 100KB

[INFO] === Phase 4: NVS Round-trip ===
[INFO] Writing key "hw_test" = 42 to namespace "mms_config"...
[INFO] Reading back key "hw_test"...
[INFO] Read value  : 42
[PASS] NVS write/read round-trip successful

[INFO] === Phase 5: LittleFS Mount + Write/Read ===
[PASS] LittleFS mounted
[PASS] File write/read round-trip verified
[INFO] LittleFS free: 1234 KB / 1520 KB total

[INFO] === Phase 6: GPIO Blink (LED on GPIO 2) ===
[INFO] Blinking onboard LED 5 times...
[INFO] Blink 1
...
[INFO] Blink 5
[PASS] GPIO blink complete

========================================
 RESULT: 8/8 passed
 STATUS: PASS
========================================
[INFO] Heap monitor: every 5s. Press reset to re-run.
[LOOP] Uptime=5s  heap=284312B  min_heap=280000B
```

### Expected display output
None — this sketch uses no display.

### Pass criteria
- All 8 checks print `[PASS]`
- No `[FAIL]` lines
- Onboard LED (near USB connector) blinks 5 times
- Heap loop prints every 5 seconds

### Fail criteria and troubleshooting

| Failure message | Cause | Fix |
|---|---|---|
| No output on Serial Monitor | Wrong COM port or baud | Check Device Manager / `ls /dev/ttyUSB*`, set 115200 |
| `Failed to mount LittleFS` | Wrong partition scheme | Tools → Partition Scheme → `Default 4MB with spiffs` |
| `Free heap < 100KB` | Memory fragmentation or leak | Flash a fresh sketch, check for large static arrays |
| `NVS write failed` | NVS full from previous test | Flash → Tools → Erase All Flash Memory |
| No blink on LED | GPIO 2 wired differently on your board | Check your board's LED pin; some NodeMCU 38-pin use GPIO 2, some differ |

**Common mistakes:**
- Opening Serial Monitor before upload finishes (see garbage characters) — wait for "Done uploading"
- Using a charge-only USB cable (upload fails silently)
- Not pressing the BOOT button while uploading on boards without auto-reset circuitry

---

## Test 12 — LittleFS

**Hardware required:** ESP32, USB cable
**Hardware optional:** None
**Estimated time:** 10 minutes (rotation test writes ~50KB, takes ~5s)

### Wiring
```
[USB-A] ─────────────────── [ESP32 Micro-USB]
```

### Required libraries
- ArduinoJson 7.x (Library Manager)
- LittleFS — built into ESP32 Arduino core, no install needed

### Arduino IDE / PlatformIO setup
- Open `12_littlefs/12_littlefs.ino`
- **Critical:** Partition Scheme must be `Default 4MB with spiffs` (or any scheme with a SPIFFS/LittleFS partition ≥ 64KB)
- Upload → Serial Monitor at 115200

### Expected serial output
```
========================================
 MMS V2 — Test 12: LittleFS
========================================
[INFO] Auto-format enabled — first run will format partition if needed
[INFO] Note: Rotation test writes ~50KB of data — takes a few seconds

[INFO] === Phase 1: Mount ===
[PASS] LittleFS mounted (or auto-formatted and mounted)
[INFO] LittleFS: total=1520KB  used=0KB  free=1520KB
[PASS] LittleFS partition >= 64KB

[INFO] === Phase 2: File Write / Read / Verify ===
[INFO] Written 32 bytes to /test/hw_test.txt
[PASS] Read-back matches written content exactly
[PASS] File size matches content length

[INFO] === Phase 3: JSONL Append + Parse ===
[INFO]  line 1  t=1718600000  r=220002120  d=120
[INFO]  line 2  t=1718600300  r=220002121  d=150
[INFO]  line 3  t=1718600600  r=220002122  d=180
[INFO]  line 4  t=1718600900  r=220002123  d=210
[INFO]  line 5  t=1718601200  r=220002124  d=240
[INFO] Parsed 5 valid / 0 invalid lines
[PASS] All 5 JSONL lines written and parsed successfully

[INFO] === Phase 4: Partial-line Resilience ===
[INFO] Discarding partial/invalid line: {"t":9999,"r":"INCOMPLETE
[PASS] Partial line detected and discarded — valid lines intact

[INFO] === Phase 5: Log Rotation (50KB threshold) ===
[INFO] File reached 50KB — rotating...
[INFO] sessions.jsonl → sessions.old.jsonl
[INFO] Lines written before rotation: 412
[PASS] Rotation: old file renamed, current slot cleared
[PASS] Rotated file contains expected data volume (>= 50KB)

[INFO] === Phase 6: Delete + Free Space Recovery ===
[INFO] LittleFS: total=1520KB  used=51KB  free=1469KB
[INFO] Space recovered: 51KB
[PASS] Delete freed space — LittleFS garbage collection working
[PASS] All test files deleted successfully

[INFO] === Phase 7: Config File (revocation list format) ===
[INFO] Revoked UIDs in file: 2
[INFO]   A1B2C3D4
[INFO]   E5F60718
[PASS] revoked.json round-trip: 2 UIDs written and parsed correctly
[PASS] UID lookup in revocation list works correctly

========================================
 RESULT: 12/12 passed
 STATUS: PASS
========================================
```

### Expected display output
None.

### Pass criteria
All 12 checks print `[PASS]`. Rotation test completes (may take 5–10 seconds — the serial will be silent while writing).

### Fail criteria and troubleshooting

| Failure message | Cause | Fix |
|---|---|---|
| `LittleFS.begin() failed` | No LittleFS partition in scheme | Change partition scheme; re-upload |
| `Partition too small: 0KB` | Wrong partition scheme selected | Use `Default 4MB with spiffs` |
| `JSONL parse failed` | ArduinoJson version mismatch | Install ArduinoJson 7.x, not 5.x or 6.x |
| Rotation test hangs | Filesystem full before 50KB | Check partition size; ensure `formatOnFail=true` re-formatted |
| `Delete freed space` check fails | LittleFS GC needs remount | Cosmetic — re-run test after reset |

**Common mistakes:**
- Installing ArduinoJson 6.x instead of 7.x (API difference — `StaticJsonDocument` deprecated in 7.x but still works; confirm no compile errors)
- Not changing partition scheme before Test 01 (both tests 01 and 12 need it — do it once at the start)

---

## Test 10 — WiFi

**Hardware required:** ESP32, USB cable, 2.4 GHz WiFi access point
**Hardware optional:** Router with internet (for NTP validation)
**Estimated time:** 10 minutes

### Wiring
```
[USB-A] ─────────────────── [ESP32 Micro-USB]
```
No breadboard wiring. Internal antenna.

### Required libraries
- WiFi — built into ESP32 Arduino core
- time.h — built-in C standard library

### Arduino IDE / PlatformIO setup
1. Open `10_wifi/10_wifi.ino`
2. Edit the `#define` block at the top:
   ```cpp
   #define WIFI_SSID      "your_network_name"
   #define WIFI_PASSWORD  "your_password"
   ```
3. Upload → Serial Monitor at 115200

### Expected serial output
```
========================================
 MMS V2 — Test 10: WiFi
========================================
[INFO] Target SSID: tlmms
[INFO] Note: ESP32 supports 2.4 GHz only — not 5 GHz

[INFO] === Phase 1: Network Scan ===
[INFO] Found 8 networks:
[INFO]   -45 dBm  [AUTH]  tlmms
[INFO]   -67 dBm  [AUTH]  JIOFIBER_HOME
[INFO]   -71 dBm  [OPEN]  Guest
...
[PASS] Target SSID found in scan

[INFO] === Phase 2: Connection ===
[INFO] Connecting to "tlmms"...
..
[PASS] Connected in 2340 ms
[INFO] IP address  : 192.168.0.105
[INFO] Subnet mask : 255.255.255.0
[INFO] Gateway     : 192.168.0.1
[INFO] DNS         : 192.168.0.1
[INFO] BSSID (AP)  : AA:BB:CC:DD:EE:FF
[INFO] Channel     : 6
[INFO] RSSI: -48 dBm (EXCELLENT)
[PASS] Valid IP address assigned
[PASS] RSSI above minimum threshold (-80 dBm)

[INFO] === Phase 3: NTP Time Sync ===
[INFO] Configuring NTP — server: pool.ntp.org  GMT offset: 19800s (IST = UTC+5:30)
[INFO] Waiting for NTP sync.......
[PASS] NTP synced — 2026-06-16 14:32:18 IST
[PASS] NTP time is current (year >= 2024)

[INFO] === Phase 4: Disconnect / Reconnect ===
[INFO] Forcing disconnect...
[PASS] WiFi disconnected cleanly
[INFO] Reconnecting...
.
[PASS] Reconnect OK in 1820 ms
[INFO] RSSI: -48 dBm (EXCELLENT)
[PASS] IP address retained after reconnect

========================================
 RESULT: 8/8 passed
 STATUS: PASS
========================================
[INFO] Monitoring mode: printing RSSI and heap every 10s.
[LOOP] Connected  RSSI=-48dBm  heap=231456B  uptime=30s
```

### Expected display output
None.

### Pass criteria
- Target SSID appears in scan
- IP address assigned (not 0.0.0.0)
- RSSI > -80 dBm at bench location
- NTP year ≥ 2024
- Reconnect succeeds

### Fail criteria and troubleshooting

| Failure message | Cause | Fix |
|---|---|---|
| `No networks found` | Antenna issue or SPI conflict | Ensure no SPI devices connected; try different location |
| `Target SSID not found` | 5 GHz only network, or hidden SSID | Enable 2.4 GHz band on router; unhide SSID |
| `Connection failed after 15s` | Wrong password | Double-check `WIFI_PASSWORD` — case sensitive |
| `WiFi status code: 6` | Wrong password confirmed | Re-check password |
| `IP address is 0.0.0.0` | DHCP failed | Check router DHCP pool isn't exhausted; restart router |
| `NTP sync timed out` | No internet access | Verify router has internet; UDP port 123 may be blocked |
| `RSSI below -80 dBm` | Node too far from AP | Move closer; use directional antenna |

**Common mistakes:**
- Network is 5 GHz-only ("AC" or "AX" only mode) — ESP32 is 2.4 GHz only
- SSID has a space or special character — use double quotes in `#define`
- Testing in a room with WiFi but the router is 5 floors up (poor RSSI)

---

---

# Phase B — Network Validation

---

## Test 11 — MQTT

**Hardware required:** ESP32, USB cable, WiFi AP, Raspberry Pi with Mosquitto
**Hardware optional:** Echo responder script (for round-trip latency — see below)
**Estimated time:** 15 minutes

### Wiring
```
[USB-A] ─────────────────── [ESP32 Micro-USB]
(same as Test 10 — no breadboard wiring)
```

### Pre-requisites on Raspberry Pi
SSH into the RPi and confirm Mosquitto is running:
```bash
sudo systemctl status mosquitto
# Should show: Active: active (running)
```
If not installed:
```bash
sudo apt install mosquitto mosquitto-clients
sudo systemctl enable --now mosquitto
```

**Optional — echo responder** (enables QoS round-trip latency measurement):
Open a second terminal on the RPi and run:
```bash
mosquitto_sub -h localhost -t mms/test/echo | \
  xargs -I{} mosquitto_pub -h localhost -t mms/test/response -m "{}"
```
Leave this running during the test.

### Required libraries
- PubSubClient by Nick O'Leary 2.8.x (Library Manager)
- WiFi — built-in

### Arduino IDE / PlatformIO setup
1. Open `11_mqtt/11_mqtt.ino`
2. Edit the `#define` block:
   ```cpp
   #define WIFI_SSID      "your_network_name"
   #define WIFI_PASSWORD  "your_password"
   #define MQTT_BROKER    "192.168.0.10"    // RPi static IP
   #define MQTT_PORT      1883
   ```
3. Upload → Serial Monitor at 115200

### Expected serial output
```
========================================
 MMS V2 — Test 11: MQTT
========================================
[INFO] Broker: 192.168.0.10:1883
[INFO] ClientID: mms_hwtest_mqtt
[INFO] Round-trip test requires echo responder on broker.
[INFO] On RPi: mosquitto_sub -t mms/test/echo | xargs -I{} mosquitto_pub -t mms/test/response -m {}

[INFO] === Phase 1: WiFi + Broker Connect ===
[INFO] Connecting WiFi to "tlmms"...
..
[PASS] WiFi connected  IP=192.168.0.105
[INFO] Connecting to MQTT broker 192.168.0.10:1883
.
[PASS] MQTT broker connected
[PASS] Subscribed to mms/test/response

[INFO] === Phase 2: QoS 0 Round-trip ===
[MQTT RX] topic=mms/test/response  payload=ping_0_12345
[RTT]  attempt 1/5  QoS0  rtt=18ms
[RTT]  attempt 2/5  QoS0  rtt=15ms
...
[PASS] QoS 0 RTT < 500ms on LAN

[INFO] === Phase 3: QoS 1 Publish ===
[INFO] QoS 1 topic publishes: 5/5
[PASS] All QoS 1 topic publishes acknowledged by broker

[INFO] === Phase 4: Retained Message Test ===
[INFO] Retained message published to mms/test/retained
[INFO] Disconnected. Reconnecting to verify retained delivery...
[PASS] Reconnect after retained test succeeded
[MQTT RX] topic=mms/test/retained  payload={"test":"retained_v2","ts":1}
[PASS] Retained message delivered on reconnect + subscribe
[INFO] Retained message cleared (empty payload published with retain=true)

[INFO] === Phase 5: Disconnect / Reconnect Timing ===
[INFO] State after disconnect: -1
[PASS] Reconnect in 380 ms
[PASS] Reconnect latency < 2s (acceptable for lab LAN)

========================================
 RESULT: 9/9 passed
 STATUS: PASS
========================================
[LOOP] Heartbeat published  {"uptime":45,"heap":215000,"rssi":-48}
```

### Expected display output
None.

### Pass criteria
- Broker connection established
- Retained message received on reconnect
- QoS round-trip < 500ms (if echo responder is running)
- All 5 QoS 1 publishes return `true`
- Reconnect in < 2s

### Fail criteria and troubleshooting

| Failure message | Cause | Fix |
|---|---|---|
| `MQTT broker connection failed` + state -2 | Wrong broker IP or port | `ping 192.168.0.10` from laptop to verify RPi reachable |
| State -4: `CONN_TIMEOUT` | Mosquitto not listening on 1883 | `sudo netstat -tlnp \| grep 1883` on RPi |
| State 5: `UNAUTH` | Mosquitto requires password | Add `allow_anonymous true` to `/etc/mosquitto/mosquitto.conf`, restart |
| `Retained message not received` | Mosquitto persistence off | Add `persistence true` to mosquitto.conf |
| `No echoes received` | Echo responder not running | Run the `mosquitto_sub \| xargs` command on RPi |
| Reconnect > 2s | RPi under load | Acceptable — warn only, not fail |

**Common mistakes:**
- Using RPi's WiFi IP instead of its Ethernet IP (WiFi IP can change; use static Ethernet)
- Mosquitto running on localhost only — check `bind_address` is not set or is `0.0.0.0`
- Forgetting to start the echo responder (Phase 2 will print "No echoes" — not a fail, just informational)
- Confusing PubSubClient's `publish()` QoS: PubSubClient publish is always QoS 0 at the library level; QoS 1 delivery is handled by the `subscribe()` + retained test

---

---

# Phase C — I2C

---

## Test 05 — OLED 128×32 I2C

**Hardware required:** ESP32, SSD1306 128×32 I2C OLED, jumper wires
**Hardware optional:** None
**Estimated time:** 10 minutes

### Wiring

```
ESP32 NodeMCU 38-pin          SSD1306 128×32 I2C OLED
                              (4-pin module)
─────────────                 ─────────────────────────
3V3  (pin 2)  ─────────────── VCC
GND  (pin 1)  ─────────────── GND
GPIO 21       ─────────────── SDA
GPIO 22       ─────────────── SCL

I2C address: 0x3C (default on most modules)
No RST pin connection needed — OLED_RESET = -1 in firmware
```

**Breadboard layout:**
```
ESP32                                    OLED 128×32
 3V3 ─── [RED wire]   ────────────────── VCC
 GND ─── [BLACK wire] ────────────────── GND
GPIO21 ── [BLUE wire]  ────────────────── SDA
GPIO22 ── [YELLOW wire]────────────────── SCL
```

### Required libraries
- Adafruit SSD1306 2.5.x
- Adafruit GFX Library 1.11.x
- Adafruit BusIO (auto-installed with SSD1306)

### Arduino IDE / PlatformIO setup
- Open `05_oled32_i2c/05_oled32_i2c.ino`
- Upload → Serial Monitor at 115200
- **Watch both the serial output AND the OLED screen simultaneously**

### Expected serial output
```
========================================
 MMS V2 — Test 05: OLED 128×32 I2C
========================================
[INFO] I2C scan on SDA=21 SCL=22 at 400kHz...
[INFO] I2C device found at address 0x3C
[PASS] SSD1306 at 0x3C — expected address confirmed

[INFO] Initializing SSD1306 128×32 I2C...
[PASS] SSD1306 128×32 initialized

[INFO] === Page 1: Status Strip IDLE ===
[INFO] === Page 2: Status Strip SESSION ===
[INFO] === Page 3: Full Fill (all pixels on) ===
[INFO] === Page 4: Vertical Stripe Pattern ===
[INFO] === Page 5: OFFLINE Status ===

========================================
 RESULT: 2/2 passed
 STATUS: PASS (visual checks required)
========================================
```

### Expected display output

| Page | What you should see on the 128×32 OLED |
|---|---|
| 1 (IDLE) | Left: WiFi dot + MQTT dot. Center: "SOLDERING STA 1". Right: "14:32" or "OFFLINE" |
| 2 (SESSION) | Left: filled WiFi + MQTT dots. Center: "SOLDERING STA 1". Right: "14:32" |
| 3 (Fill) | All 128×32 pixels illuminated — solid white rectangle |
| 4 (Vertical stripes) | Alternating 4px-wide vertical black/white bars |
| 5 (Offline) | Small WiFi hollow dot + "OFFLINE" + machine name |

Each page displays for 3 seconds before advancing.

### Pass criteria
- I2C scan finds device at `0x3C`
- OLED initialises without error
- All 5 pages are visible and match the descriptions above
- No garbled or blank screens between pages

### Fail criteria and troubleshooting

**Troubleshooting tree:**
```
OLED is completely blank?
  ├── Serial shows "I2C device found at 0x3C" → SSD1306.begin() failed
  │     → Check library version (SSD1306 2.5.x). Try swapping SDA/SCL wires.
  ├── Serial shows "No I2C devices found"
  │     → Check VCC (multimeter: should be 3.3V on VCC pin)
  │     → Check SDA/SCL on correct GPIO (21 and 22)
  │     └── Some cheap modules need 5V VCC — try 5V (Vin) instead of 3V3
  └── Upload failed → Check COM port

I2C scan finds device at 0x3D instead of 0x3C?
  → Module has address select solder bridge. Change address in .ino:
    Adafruit_SSD1306 display(WIDTH, HEIGHT, &Wire, OLED_RESET, 400000, 400000);
    display.begin(SSD1306_SWITCHCAPVCC, 0x3D)

Display shows white noise / garbage pixels?
  → Power issue. Add 10µF capacitor across VCC–GND on breadboard.

First page shows but subsequent pages are blank?
  → clearDisplay() not called — library version issue. Upgrade Adafruit SSD1306.
```

| Failure message | Cause | Fix |
|---|---|---|
| `No I2C devices found` | Wrong pins or no power | Verify GPIO 21=SDA, 22=SCL; check VCC |
| `SSD1306 init failed` | Address mismatch | Try `0x3D` in init call |
| All pages blank | Wrong height (32 vs 64) | Confirm display is 32-pixel height in constructor |

**Common mistakes:**
- Using a 128×64 I2C OLED instead of the 128×32 model (display height mismatch — firmware halves the height)
- Swapping SDA and SCL (device found at scan but display looks wrong)
- VCC on 5V pin instead of 3.3V (some modules overheat; most work on both — check module datasheet)

---

---

# Phase D — SPI Bus

> **Note:** Both Test 04 (OLED SPI) and Test 02 (MFRC522) share the same SPI bus (GPIO 18/19/23). Wire the OLED first, validate it alone, then add the MFRC522.

---

## Test 04 — OLED 128×64 SPI

**Hardware required:** ESP32, SSD1306 128×64 SPI OLED (7-pin), jumper wires
**Hardware optional:** None
**Estimated time:** 10 minutes

### Wiring

```
ESP32 NodeMCU 38-pin          SSD1306 128×64 SPI OLED
                              (7-pin SPI module)
─────────────                 ─────────────────────────
3V3  (pin 2)  ─────────────── VCC
GND  (pin 1)  ─────────────── GND
GPIO 18       ─────────────── D0 (SCK / CLK)
GPIO 23       ─────────────── D1 (MOSI / SDA)
GPIO 17       ─────────────── DC  (data/command select)
GPIO 16       ─────────────── CS  (chip select)
GPIO  4       ─────────────── RES (reset)
```

**7-pin module label variants** — these are the same signal:
- `D0` = `CLK` = `SCK` = clock → GPIO 18
- `D1` = `MOSI` = `SDA` = data → GPIO 23
- `DC` = `A0` = data/command → GPIO 17
- `CS` = `SS` = chip select → GPIO 16
- `RES` = `RST` = reset → GPIO 4

### Required libraries
- Adafruit SSD1306 2.5.x
- Adafruit GFX Library 1.11.x

### Arduino IDE / PlatformIO setup
- Open `04_oled64_spi/04_oled64_spi.ino`
- Upload → Serial Monitor at 115200
- Watch the display and serial simultaneously
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

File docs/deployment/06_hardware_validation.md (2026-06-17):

# Section 06 — Hardware Validation

← [Hardware Assembly](05_hardware_assembly.md) | → [Raspberry Pi Deployment](07_raspberry_pi_deployment.md)

---

## Purpose

Hardware validation confirms that every component on a freshly assembled node is wired correctly and functional before flashing production firmware. Running these tests takes approximately 2 hours and 15 minutes. A node that passes all 12 tests is ready for provisioning.

**Do not skip this section.** Production firmware cannot distinguish a wiring error from a software bug. Running the validation suite first eliminates hardware as a variable.

---

## Detailed Reference

The complete wiring diagrams, exact expected serial output, pass/fail criteria, and troubleshooting trees for each test are in:

```
firmware/hardware_validation/EXECUTION_PLAN.md
```

This section summarises the process and adds the integration test (Test 12) that is not covered in the individual sketches.

---

## Test Suite Overview

| # | Sketch | What it tests | Time | Wiring required |
|---|---|---|---|---|
| 01 | `01_nvs` | NVS read/write/clear | 5 min | None (USB only) |
| 02 | `02_rfid` | MFRC522 SPI, card read, auth | 10 min | MFRC522 |
| 03 | `03_relay` | Relay GPIO, continuity | 5 min | Relay, multimeter |
| 04 | `04_oled_spi` | 128×64 SPI OLED | 5 min | OLED64, MFRC522 |
| 05 | `05_oled_i2c` | 128×32 I2C OLED | 5 min | OLED32 |
| 06 | `06_hc89` | Slot sensor input, debounce | 5 min | HC89 |
| 07 | `07_ws2812` | WS2812 LED | 5 min | WS2812, 470Ω, 100µF |
| 08 | `08_combined_display` | All 3 displays simultaneous | 10 min | OLED64, OLED32, WS2812 |
| 09 | `09_rotary_encoder` | EC11 CLK/DT/SW, interrupts | 10 min | Encoder, 2× 10kΩ |
| 10 | `10_wifi` | WiFi connect, NTP, disconnect | 10 min | Antenna (built-in) |
| 11 | `11_mqtt` | MQTT connect, QoS 0/1, retained | 15 min | RPi running Mosquitto |
| 12 | `12_littlefs` | LittleFS mount/write/rotate | 10 min | None |

---

## Recommended Execution Order

### Phase A — No wiring needed (20 min)
Run these first because they require nothing but a USB cable. If these fail, there is an issue with the ESP32 module itself or the development environment.

1. **Test 01 — NVS** (`01_nvs/01_nvs.ino`)
2. **Test 12 — LittleFS** (`12_littlefs/12_littlefs.ino`)
3. **Test 10 — WiFi** (`10_wifi/10_wifi.ino`) — needs working WiFi AP

### Phase B — Network (15 min, needs RPi)
4. **Test 11 — MQTT** (`11_mqtt/11_mqtt.ino`) — needs Mosquitto running on RPi

### Phase C — I2C bus only (15 min)
5. **Test 05 — OLED I2C** (`05_oled_i2c/05_oled_i2c.ino`)

### Phase D — SPI shared bus (25 min)
6. **Test 04 — OLED SPI** (`04_oled_spi/04_oled_spi.ino`) — wire OLED64
7. **Test 02 — RFID** (`02_rfid/02_rfid.ino`) — add MFRC522 to same SPI bus

### Phase E — Individual GPIO (40 min)
8. **Test 03 — Relay** (`03_relay/03_relay.ino`)
9. **Test 06 — HC89** (`06_hc89/06_hc89.ino`)
10. **Test 07 — WS2812** (`07_ws2812/07_ws2812.ino`)
11. **Test 08 — Combined Display** (`08_combined_display/08_combined_display.ino`)

### Phase F — Interrupt pins (20 min)
12. **Test 09 — Rotary Encoder** (`09_rotary_encoder/09_rotary_encoder.ino`)

---

## Required Arduino IDE Setup

**Board settings (every sketch):**
- Board: ESP32 Dev Module
- Upload Speed: 921600
- CPU Frequency: 240MHz
- Flash Size: 4MB (32Mb)
- Partition Scheme: **Default 4MB with spiffs** (for LittleFS)
- PSRAM: Disabled

**Required libraries (install via Library Manager):**
| Library | Version |
|---|---|
| Adafruit SSD1306 | 2.5.9 |
| Adafruit GFX Library | 1.11.9 |
| MFRC522 | 1.4.11 |
| Adafruit NeoPixel | 1.12.3 |
| PubSubClient | 2.8.0 |
| ArduinoJson | 7.3.1 |
| LittleFS (ESP32) | Built into ESP32 core |

**ESP32 core:** 3.1.x (install via Boards Manager: esp32 by Espressif)

---

## Pass Criteria (Summary)

A node **passes** hardware validation if all of the following are true:

| Test | Pass condition |
|---|---|
| NVS | Round-trip write/read/verify succeeds for all 4 data types |
| RFID | Card UID read matches across multiple reads; auth with default key succeeds |
| Relay | Multimeter confirms continuity on NO terminal during HIGH, open during LOW |
| OLED SPI | `Adafruit SSD1306` text visible on 128×64 display |
| OLED I2C | `Adafruit SSD1306` text visible on 128×32 display |
| HC89 | Serial prints `PRESENT` when card inserted, `ABSENT` when removed; no bounce |
| WS2812 | R/G/B cycle visible; colours match expected (not shifted to GBR) |
| Combined | Both OLEDs + LED all active simultaneously; no I2C/SPI conflict |
| Encoder | CW increments, CCW decrements; SW button detected |
| WiFi | IP assigned; NTP sync; RSSI better than -80 dBm |
| MQTT | QoS 0 round-trip < 50ms; QoS 1 acknowledged; retained cleanup works |
| LittleFS | Mount, write, read, verify, rotate (50KB) all report PASS |

---

## Integration Validation (After All 12 Tests Pass)

After all 12 individual tests pass, run the full-system integration sketch to confirm all hardware works simultaneously — the same way production firmware will use it.

**Sketch:** `firmware/hardware_validation/99_full_node/99_full_node.ino`

This sketch:
1. Initialises all hardware in production order
2. Enters an interactive loop:
   - Insert card → MFRC522 reads UID, prints to serial → OLED64 shows UID → LED goes green
   - Remove card → LED goes white, OLED64 shows "Idle"
   - Relay toggles every 5s while card is present
   - OLED32 shows WiFi/MQTT status strip continuously
3. All test outcomes printed to serial: `[PASS]` or `[FAIL]` per component

If this test passes, the node is ready for production firmware.

---

## Recording Results

Use the sign-off log in [EXECUTION_PLAN.md](../../firmware/hardware_validation/EXECUTION_PLAN.md) to record results for each node.

```
Node: Machine ID [ ]  |  Date: ________  |  Engineer: ____________
01 NVS        [ ] PASS  [ ] FAIL
02 RFID       [ ] PASS  [ ] FAIL
03 Relay      [ ] PASS  [ ] FAIL
04 OLED SPI   [ ] PASS  [ ] FAIL
05 OLED I2C   [ ] PASS  [ ] FAIL
06 HC89       [ ] PASS  [ ] FAIL
07 WS2812     [ ] PASS  [ ] FAIL
08 Combined   [ ] PASS  [ ] FAIL
09 Encoder    [ ] PASS  [ ] FAIL
10 WiFi       [ ] PASS  [ ] FAIL
11 MQTT       [ ] PASS  [ ] FAIL
12 LittleFS   [ ] PASS  [ ] FAIL
99 Integration [ ] PASS  [ ] FAIL
Sign-off: _______________
```

Do not proceed to [Section 11 — Access Node Provisioning](11_access_node_provisioning.md) until the sign-off is complete.

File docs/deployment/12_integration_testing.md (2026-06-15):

# Section 12 — Integration Testing

← [Access Node Provisioning](11_access_node_provisioning.md) | → [Production Rollout](13_production_rollout.md)

---

## Purpose

Integration testing confirms that all system components (ESP32 node → MQTT → RPi bridge → Firebase → web dashboard) work together end-to-end. Run this before deploying any node to a live machine.

**Required:** At least one provisioned node (Section 11), RPi running bridge.py, Firebase deployed, web app deployed, at least one issued card.

---

## Test Environment Setup

```
Laptop (web browser, Serial Monitor)
    │
    ├── USB → ESP32 Node (provisioned, connected to lab WiFi)
    │
    └── LAN → Raspberry Pi (192.168.0.10)
              ├── Mosquitto broker
              └── bridge.py → Firebase
                               ├── Firestore
                               └── RTDB
```

**Before starting:** Open all of these simultaneously:
1. Serial Monitor at 115200 baud on the node
2. Firebase Console → Firestore → sessions (real-time view)
3. Firebase Console → RTDB → mms/nodes/{your machine ID}
4. Web app dashboard in browser (`https://your-project.web.app`)

---

## Test 1 — Normal Session (Card Tap + Remove)

**Expected outcome:** Session recorded in Firestore; RTDB shows active state during session; dashboard shows live status.

**Steps:**
1. Insert a permitted card into the HC89 slot
2. Observe:
   - Serial: `[ACCESS] GRANTED` → `[RELAY] ON` → `[SESSION] Started`
   - RTDB: `/mms/nodes/1` state changes to `"active"` within 2s
   - Dashboard: machine card shows student's roll number and session timer
3. Wait 30 seconds
4. Remove card
5. Observe:
   - Serial: `[HC89] Card absent` → `[RELAY] OFF` → `[SESSION] Ended`
   - RTDB: `/mms/nodes/1` state changes to `"idle"` within 2s
   - Firestore `/sessions`: new document with `start_time`, `end_time`, `duration_s`, `end_reason:"card_removed"`
   - Dashboard: machine card returns to idle state

**Pass criteria:**
- [ ] Relay energised within 1s of card detection
- [ ] RTDB status updates within 2s
- [ ] Firestore session document created with correct roll number
- [ ] `end_reason` = `"card_removed"`
- [ ] Dashboard updates without manual refresh

---

## Test 2 — Access Denial (Non-permitted Card)

**Steps:**
1. Insert a card that does NOT have permission for this machine
2. Observe:
   - Serial: `[ACCESS] DENIED — permission bit = 0`
   - OLED: "Access Denied" with reason
   - LED: 3 quick red flashes
   - Relay: stays OFF (confirm with multimeter or by checking the machine does not power on)
3. After 3 seconds, node returns to IDLE automatically

**Pass criteria:**
- [ ] Relay never energises
- [ ] No session document created in Firestore
- [ ] OLED shows denial reason

---

## Test 3 — Session Timeout

**Steps:**
1. Temporarily change session limit to 1 minute:
   - Web app → Machine Management → select machine → Edit → Session Limit: 1 min → Save
   - Confirm RTDB/MQTT config pushed (serial: `[MQTT] Received config: {session_limit:1...}`)
2. Insert permitted card — start session
3. Wait 58 seconds (2 minutes warning — this is 2 min before limit, but at 1 min limit the warning at `limit - 2min` = negative, so it skips and goes directly to timeout)
4. Wait for 60 seconds total
5. Observe: relay turns OFF, OLED shows "Session Expired", Firestore `end_reason:"timeout"`
6. Restore session limit to original value

**Pass criteria:**
- [ ] Relay de-energises at timeout
- [ ] `end_reason` = `"timeout"` in Firestore
- [ ] Node returns to IDLE and accepts next card

---

## Test 4 — Remote Stop

**Steps:**
1. Start a session by inserting a permitted card
2. Confirm dashboard shows the active session
3. In web dashboard: click "Stop Session" on this machine's card
4. Observe:
   - RTDB: `/mms/commands/1` written immediately
   - Serial: `[MQTT] Received command: stop`
   - Relay: OFF within 2s
   - Serial: `[SESSION] Ended — reason: remote_stop`
   - Firestore: session document created with `end_reason:"remote_stop"`
   - RTDB: `/mms/commands/1` shows `acknowledged: true`

**Pass criteria:**
- [ ] Relay OFF within 2 seconds of clicking Stop in dashboard
- [ ] `end_reason` = `"remote_stop"` in Firestore
- [ ] RTDB command acknowledged flag set to true

---

## Test 5 — Card Revocation

**Steps:**
1. Note the UID of the card you are using (visible on serial: `[RFID] UID: A1B2C3D4`)
2. In web app: User Management → select the user → Revoke Card → Confirm
3. Observe bridge log: `[BRIDGE] Revocation list updated — 1 UID(s) revoked`
4. Observe node serial: `[MQTT] Received revoked list — 1 UID(s)` → `[FS] Revocation list updated`
5. Insert the revoked card
6. Observe: `[ACCESS] DENIED — card revoked`
7. OLED shows "Card Revoked"

**Pass criteria:**
- [ ] Denial happens within 5 seconds of revocation in web app
- [ ] Revoked card denied even if permissions would otherwise allow access
- [ ] Relay never energises

---

## Test 6 — Offline Session (RPi Unavailable)

**Steps:**
1. Stop the bridge: `sudo systemctl stop mms-bridge` on RPi
2. Also stop Mosquitto: `sudo systemctl stop mosquitto` on RPi
3. Wait for node serial to show: `[MQTT] Connection failed — operating offline`
4. Insert a permitted card
5. Session should be granted (offline access decision is local)
6. Remove card after 30s
7. Observe: session written to LittleFS (`[FS] Log appended`)
8. Restart Mosquitto: `sudo systemctl start mosquitto`
9. Restart bridge: `sudo systemctl start mms-bridge`
10. Watch node serial for reconnect and flush:
```
[MQTT] Connected
[FS] Flushing 1 events from LittleFS
[MQTT] Published event: {t:..., r:"220002123", m:1, ...}
[FS] Log cleared after successful flush
```
11. Confirm session appeared in Firestore

**Pass criteria:**
- [ ] Access granted while offline
- [ ] Session correctly stored in LittleFS during outage
- [ ] Session appears in Firestore after reconnection
- [ ] No duplicate Firestore documents

---

## Test 7 — Stale Command (5-minute TTL)

**Steps:**
1. Stop Mosquitto on RPi: `sudo systemctl stop mosquitto`
2. In web dashboard: click "Stop Session" on an active-looking machine (even if no session is running)
   - This writes a command to RTDB with current timestamp
3. Wait 6 minutes
4. Restart Mosquitto and bridge: `sudo systemctl start mosquitto && sudo systemctl start mms-bridge`
5. Node reconnects to MQTT
6. Observe serial:
```
[MQTT] Received command: stop
[CMD] Command timestamp is 360s old (> 300s TTL) — discarding
[MQTT] Published ack: {acknowledged: true, ack_at: ...}
```
7. Relay should NOT toggle — the command was discarded as stale

**Pass criteria:**
- [ ] Stale command discarded without executing
- [ ] Command acknowledged in RTDB (so it doesn't repeat)
- [ ] Relay state unchanged

---

## Test 8 — Config Push (Live Update)

**Steps:**
1. Observe current session limit in OLED or serial
2. In web app: Machine Management → select machine → Edit → change Session Limit (e.g., 45 → 30 minutes)
3. Within 5 seconds, observe node serial:
```
[MQTT] Received config: {session_limit:30, ...}
[NVS] Config updated: session_limit = 30
```
4. Start a session and confirm the new limit is shown on OLED

**Pass criteria:**
- [ ] Config change reflected on node within 5s
- [ ] NVS updated (persists across reboot)
- [ ] New limit shown on OLED during active session

---

## Test 9 — Watchdog Recovery

**Only run this on a test bench, not on a deployed node.**

**Steps:**
1. Flash a modified firmware that deliberately blocks the main loop for 35 seconds (longer than 30s TWDT)
2. Boot the node
3. After ~30 seconds: node should reboot automatically
4. Observe on serial (after reboot):
```
[SYS] Boot reason: WDT reset
[SYS] Previous session may have been active — checking LittleFS
```

**Pass criteria:**
- [ ] Node reboots within 35 seconds of blocking the loop
- [ ] Node recovers to IDLE after reboot
- [ ] Boot reason logged as WDT

---

## Test 10 — Duplicate Session Prevention

**Steps:**
1. Flash the same offline session log to LittleFS twice (copy the same event twice in sessions.jsonl using a test sketch)
2. Reconnect to MQTT — both events flush
3. Check Firestore — should only show ONE session document

**Mechanism to verify:** Bridge.py checks for existing session within ±5s before inserting. Second event matches → skipped.

**Pass criteria:**
- [ ] Exactly 1 Firestore document despite 2 identical events being flushed

---

## Integration Test Sign-off Sheet

```
Integration Test Sign-off
Machine ID:  [ ]  Name: _______________________
Date: __________  Engineer: ___________________
RPi IP: ____________  Firebase Project: _________

Test 1  — Normal Session        [ ] PASS  [ ] FAIL
Test 2  — Access Denial         [ ] PASS  [ ] FAIL
Test 3  — Session Timeout       [ ] PASS  [ ] FAIL
Test 4  — Remote Stop           [ ] PASS  [ ] FAIL
Test 5  — Card Revocation       [ ] PASS  [ ] FAIL
Test 6  — Offline Session       [ ] PASS  [ ] FAIL
Test 7  — Stale Command TTL     [ ] PASS  [ ] FAIL
Test 8  — Config Push           [ ] PASS  [ ] FAIL
Test 9  — Watchdog Recovery     [ ] SKIP (bench only) [ ] PASS [ ] FAIL
Test 10 — Dedup Prevention      [ ] SKIP (optional)  [ ] PASS [ ] FAIL

Overall result:  [ ] PASS  [ ] FAIL
Notes: _______________________________________________

Sign-off: _______________________________
```

**A node passes integration testing if Tests 1–8 all pass.**
Tests 9 and 10 are optional during initial rollout but should be done before full production deployment.

Proceed to [Section 13 — Production Rollout](13_production_rollout.md).

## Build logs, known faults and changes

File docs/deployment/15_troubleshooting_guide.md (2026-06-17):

# Section 15 — Troubleshooting Guide

← [Maintenance Handbook](14_maintenance_handbook.md) | → [Disaster Recovery](16_disaster_recovery.md)

---

## How to Use This Guide

Find the symptom that matches your problem, follow the tree from top to bottom. Each tree ends in either a fix or an escalation to disaster recovery (Section 16).

---

## Symptom Index

1. [Node OLED is blank or shows garbage](#1-node-oled-blank-or-garbage)
2. [Card inserted but no reaction](#2-card-inserted-but-no-reaction)
3. [Card denied with "Access Denied" — should be allowed](#3-card-denied-but-should-be-allowed)
4. [Relay does not energise after GRANTED](#4-relay-does-not-energise-after-granted)
5. [Machine does not power on despite relay energising](#5-machine-does-not-power-on-despite-relay-on)
6. [MQTT connection fails or keeps reconnecting](#6-mqtt-connection-fails)
7. [Sessions not appearing in Firestore](#7-sessions-not-in-firestore)
8. [Dashboard shows machine as "offline"](#8-dashboard-shows-offline)
9. [Remote stop not working](#9-remote-stop-not-working)
10. [Revocation not propagating to node](#10-revocation-not-propagating)
11. [OTA update stuck or failed](#11-ota-update-stuck-or-failed)
12. [Bridge service not starting](#12-bridge-service-not-starting)
13. [Node keeps rebooting (watchdog loop)](#13-node-keeps-rebooting)
14. [WiFi connection fails](#14-wifi-fails)
15. [WS2812 LED wrong colour or not working](#15-ws2812-wrong-colour)

---

## 1. Node OLED Blank or Garbage

```
OLED is completely blank
│
├── Is the node powered? (power LED on ESP32 lit?)
│   No → Check HiLink PSU output: measure Vin pin with multimeter
│         Should be 4.8–5.2V
│         No voltage → check AC fuse, HiLink wiring
│
└── Yes, node is powered
    │
    ├── Is it SPI OLED (128×64) or I2C OLED (128×32)?
    │
    ├── SPI OLED (128×64):
    │   Flash `04_oled_spi` test sketch
    │   Serial shows "SSD1306 init OK" but display blank?
    │   → Check CS (GPIO 16), DC (GPIO 17), RST (GPIO 4) wiring
    │   → Check 3.3V on VCC pin of display
    │   Serial shows "SSD1306 init FAILED"?
    │   → Check MOSI (GPIO 23) and SCK (GPIO 18) — SPI bus wiring
    │   → The SPI bus is shared with MFRC522; if RFID is broken it can corrupt SPI
    │
    └── I2C OLED (128×32):
        Flash `05_oled_i2c` test sketch
        Serial shows "SSD1306 I2C init OK" but blank?
        → Check SDA (GPIO 21), SCL (GPIO 22) wiring
        → Check I2C address: `i2cdetect` scan at address 0x3C
        Serial shows "SSD1306 I2C init FAILED"?
        → Confirm OLED module type: 128×32 SSD1306, I2C variant
        → Check 3.3V on VCC pin

OLED shows garbage or random pixels:
→ RST pin (SPI OLED only, GPIO 4) not held LOW long enough on init
→ Re-flash firmware; if persists, replace SSD1306 module
```

---

## 2. Card Inserted But No Reaction

```
Card inserted into HC89 slot — nothing happens on OLED, no serial output

├── Check serial: does any message appear at all?
│   No →
│       Is the HC89 sensor connected?
│       Flash `06_hc89` test sketch
│       Serial "HC89: ABSENT" → sensor wired, card not detected
│       → Check HC89 OUT → GPIO 32 connection
│       → Try a different card (HC89 slot width: card must fit snugly)
│       → Check 3.3V on HC89 VCC
│
│   Serial shows "[HC89] Card present" but no RFID activity →
│       MFRC522 is failing silently
│       Flash `02_rfid` test sketch
│       → Check SPI wiring: SS=GPIO5, SCK=GPIO18, MOSI=GPIO23, MISO=GPIO19, RST=GPIO27
│       → Check 3.3V on MFRC522 VCC (NOT 5V — MFRC522 is 3.3V only)
│
└── Serial shows RFID error:
    "[RFID] Auth FAILED" →
        Wrong card type (not MIFARE Classic 1K)
        OR card was written with a different master key
        Check card type — it must be MIFARE Classic 1K (Mifare S50)
        Verify master key in secrets.h matches kiosk secrets.py
```

---

## 3. Card Denied But Should Be Allowed

```
Serial shows "[ACCESS] DENIED" for a card that should be permitted

├── Reason: "card revoked"
│   → Admin accidentally revoked this card
│   → Web app → User Management → check if UID appears in revoked list
│   → Remove from revoked if revocation was a mistake (delete /revoked/{uid} in Firestore)
│   → Bridge will push updated revocation list; node accepts card within 5s
│
├── Reason: "permission bit = 0"
│   → Card was issued with wrong permissions
│   → Web app → User Management → check machine_permissions for this user
│   → If wrong: edit permissions → re-issue card at kiosk
│   → Old card cannot be updated remotely — must re-issue
│
├── Reason: "schema version != 0x02"
│   → Card was written by V1 kiosk (old system)
│   → Must re-issue card at kiosk with V2 schema
│
├── Reason: "machine disabled"
│   → Admin set machine_active = false
│   → Web app → Machine Management → toggle machine to enabled
│
└── Reason: "RFID auth failed"
    → Card was written by a different kiosk with different master key
    → OR sector key derivation mismatch between kiosk and node
    → Verify master key is identical (same 32 bytes) in:
        firmware/access_node/secrets.h
        apps/kiosk_station/secrets.py (MASTER_KEY hex)
        apps/apps/kiosk_station/station_writer/secrets_station.h
    → If mismatch confirmed: node must be re-flashed with correct key
      OR re-issue all cards with the node's key
```

---

## 4. Relay Does Not Energise After GRANTED

```
Serial shows "[RELAY] ON" but nothing happens

├── Check relay LED indicator (most relay modules have an LED):
│   LED on → relay is energising; problem is in the load circuit → see Symptom 5
│   LED off → relay control signal issue
│       Check GPIO 26 → Relay IN wiring
│       Measure GPIO 26 with multimeter during session: should be 3.3V (active HIGH)
│       If 0V: firmware not driving pin high → check relay_active_high NVS value
│         Serial: "[RELAY] relay_active_high = 0" → relay is active LOW
│         But if your relay is active HIGH, the config is wrong
│         Web app → Machine Management → relay type → set correctly
│
└── relay_active_high config:
    true  = GPIO HIGH to activate (most 5V mechanical relay modules)
    false = GPIO LOW to activate (some SSRs and optocoupler relay boards)
    Check your relay module datasheet
```

---

## 5. Machine Does Not Power On Despite Relay On

```
Relay is energising (LED on, click sound) but machine doesn't power on

├── Check load wiring:
│   COM and NO connected? (not NC)
│   Machine AC live wire on COM, machine input on NO?
│   Use multimeter: measure continuity from COM to NO when relay energised
│   Should show < 1 Ohm when relay is ON
│   Should show open circuit when relay is OFF
│
├── Is the relay rated for the load?
│   Check machine's current draw vs relay's rated current
│   Relay modules: typically 10A 250V AC
│   Laser cutter may exceed this → use SSR rated 25A+
│
└── Is the HiLink fuse blown?
    Measure HiLink output: 0V → check fuse
    Replace with same rating (5A)
```

---

## 6. MQTT Connection Fails

```
Serial: "[MQTT] Connection failed (rc=-2)" or repeated reconnect attempts

├── Can the node reach the RPi?
│   Check node's WiFi status: is WiFi connected? (OLED32 WiFi dot filled?)
│   If WiFi not connected → see Symptom 14
│
├── Is Mosquitto running on RPi?
│   ssh pi@192.168.0.10
│   sudo systemctl status mosquitto
│   Not running → sudo systemctl start mosquitto
│
├── Can a laptop reach Mosquitto?
│   From laptop on same WiFi:
│   mosquitto_sub -h 192.168.0.10 -p 1883 -t test &
│   mosquitto_pub -h 192.168.0.10 -p 1883 -t test -m hi
│   Not working → firewall blocking port 1883
│     sudo ufw allow 1883/tcp
│     sudo ufw reload
│
├── Is MQTT_BROKER IP in secrets.h correct?
│   Must match RPi's static IP (192.168.0.10 by default)
│   If RPi IP changed → update secrets.h, re-flash nodes
│
└── MQTT authentication enabled but credentials wrong?
    If mosquitto is configured with allow_anonymous false:
    Check MQTT_USER and MQTT_PASSWORD in secrets.h
    Confirm they match /etc/mosquitto/passwd on RPi
```

---

## 7. Sessions Not in Firestore

```
Sessions happening on node (relay on/off, serial confirms) but no Firestore documents

├── Is the bridge running?
│   curl http://192.168.0.10:8080/health
│   {"mqtt_connected": false, ...} → bridge lost MQTT → restart bridge
│   {"fb_connected": false, ...}   → Firebase connection lost → check internet on RPi
│   Connection refused              → bridge not running → sudo systemctl start mms-bridge
│
├── Bridge running but no Firestore writes?
│   sudo journalctl -u mms-bridge -f
│   Look for: "Firestore write failed" or "PERMISSION_DENIED"
│   PERMISSION_DENIED → Firestore rules blocking write
│     Check firestore.rules: sessions allow write: if false  ← bridge uses Admin SDK, bypasses rules
│     If bridge throws PERMISSION_DENIED, the service account may lack permissions
│     Firebase Console → IAM → ensure service account has "Firebase Admin" role
│
├── Is the event being published by the node?
│   Serial: "[MQTT] Published event: {...}" → event is sent
│   If no publish line → session manager not calling publish; check firmware
│
└── Bridge gets event but doesn't write?
    Check bridge log for the specific session event line
    If bridge log shows "Duplicate session detected — skipping":
    Two events were published for the same session (deduplication triggered)
    This is correct behaviour — no action needed
```

---

## 8. Dashboard Shows Machine as "Offline"

```
Web dashboard shows machine state as "offline"

├── Is the node actually powered and running?
│   Physical check: OLEDs lit? LED breathing?
│   If no → power issue → check HiLink, fuse
│
├── Is the node connected to MQTT?
│   Serial: "[MQTT] Connected"? Or reconnecting?
│   Node not connected → MQTT troubleshooting above (#6)
│
├── Is the bridge updating RTDB?
│   Check RTDB in Firebase Console → /mms/nodes/{id}/last_seen
│   Value not updating → bridge RTDB writes failing
│   sudo journalctl -u mms-bridge -f
│   Look for RTDB write errors
│
└── Is the web app reading RTDB correctly?
    Open browser dev tools → Network tab
    Look for RTDB websocket connection (wss://your-rtdb-url)
    If no websocket: VITE_FIREBASE_DATABASE_URL missing in .env → rebuild and redeploy web app
```

---

## 9. Remote Stop Not Working

```
Clicked Stop in dashboard — machine keeps running

├── Check RTDB: was the command written?
│   Firebase Console → /mms/commands/{machine_id}
│   Should show: {command:"stop", acknowledged:false, timestamp:...}
│   Not written → web app bug → check browser console for errors
│
├── Command written — did bridge forward it?
│   sudo journalctl -u mms-bridge -f | grep command
│   "[BRIDGE] Command forwarded to MQTT: {stop}" → bridge forwarded OK
│   No forward log → bridge not listening to /mms/commands RTDB path
│   Restart bridge: sudo systemctl restart mms-bridge
│
├── Bridge forwarded — did node receive it?
│   Serial: "[MQTT] Received command: stop"?
│   No → MQTT message not delivered → check QoS 1 pub/sub
│   Node may have been offline when command was published
│   Command has 5-min TTL — if >5min elapsed, it was discarded
│
└── Node received — but session didn't stop?
    Serial: "[CMD] State != SESSION_ACTIVE — command ignored"
    → The node was not in an active session when command arrived
    → This is correct behaviour; no action needed
```

---

## 10. Revocation Not Propagating to Node

```
Revoked card in web app but node still allows it

├── Did Firestore update?
│   Firebase Console → /revoked/{uid} → document should exist
│   Not created → web app revocation bug → check browser console
│
├── Did bridge push update to MQTT?
│   sudo journalctl -u mms-bridge -f | grep revoked
│   "[BRIDGE] Revocation list pushed: 1 UID(s)" → push happened
│   Not in logs → Firestore onSnapshot listener not triggering
│   Restart bridge: sudo systemctl restart mms-bridge
│
├── Did node receive update?
│   Serial: "[MQTT] Received revoked list — 1 UID(s)"?
│   Not received → node offline at time of push
│   Retained message: node will receive it on next MQTT connect
│   Wait for node to reconnect, then test card again
│
└── Node received update but card still allowed?
    Serial: "[ACCESS] Revocation check — UID found — DENIED"?
    If not denied: check that UID in DENIED list matches card UID exactly
    UID format: uppercase hex without spaces, e.g., "A1B2C3D4"
    Compare: Serial RFID UID vs Firebase revoked document ID
```

---

## 11. OTA Update Stuck or Failed

```
Node shows "Updating FW..." on OLED but doesn't complete

├── Check serial output:
│   "[OTA] Downloading from URL: ..."
│   "[OTA] Error: -1" or timeout
│   → URL may be expired (Firebase Storage signed URLs expire after 1 hour)
│   → Generate a new download URL; update RTDB /mms/ota/firmware_url
│
├── OTA completes but node keeps restarting:
│   → New firmware has crash bug
│   → Rollback activates after 3 crashes (automatic)
│   → Node will revert to previous working firmware
│   → Fix the firmware bug, rebuild, re-upload to Storage, re-trigger OTA
│
├── OTA never starts:
│   → Bridge may not have forwarded OTA command
│   → Check RTDB /mms/ota was written correctly
│   → Check bridge log for "[BRIDGE] OTA broadcast"
│   → If no broadcast: RTDB OTA listener may not be registered
│   → Restart bridge
│
└── Node in error state after OTA, rollback failed:
    Manual recovery required:
    1. Connect laptop via USB
    2. Flash known-good firmware via Arduino IDE
    3. Reprovisioned and re-tested before reinstalling
    → See Section 16 for firmware recovery procedure
```

---

## 12. Bridge Service Not Starting

```
sudo systemctl status mms-bridge → "failed" or "activating (start)"

├── Check error log:
│   sudo journalctl -u mms-bridge -n 50
│   
│   "ModuleNotFoundError: No module named 'firebase_admin'"
│   → Python packages not installed in venv
│   → source /home/pi/mms/venv/bin/activate && pip install firebase-admin paho-mqtt
│
│   "FileNotFoundError: service-account.json"
│   → Service account file not at /home/pi/mms/service-account.json
│   → Re-transfer from secure storage
│
│   "CredentialsMissingError" or "invalid_grant"
│   → Service account key is revoked or expired
│   → Generate new key from Firebase Console → Project Settings → Service Accounts
│   → Transfer and update file, restart bridge
│
│   "MQTT connect refused"
│   → Mosquitto not running
│   → sudo systemctl start mosquitto
│   → Then restart bridge: sudo systemctl restart mms-bridge
│
└── Bridge starts but crashes within minutes:
    → Check for uncaught exception in log
    → File a bug report with the full traceback
    → In the meantime, manually run bridge.py to observe output:
      source /home/pi/mms/venv/bin/activate
      python3 /home/pi/mms/bridge.py
```

---

## 13. Node Keeps Rebooting

```
Node boots, prints some output, then reboots repeatedly

├── Check serial for boot reason:
│   "[SYS] Boot reason: WDT reset" → watchdog triggered
│       → Something is blocking the main loop for >30s
│       → Connect serial monitor and watch where it stalls
│       → Common cause: blocking MQTT reconnect, I2C lockup
│
│   "[SYS] Boot reason: panic/exception"
│       → Firmware bug; note the exception details (core dump)
│       → Report with full serial output
│
├── Bootloop after OTA:
│   → Automatic rollback should activate after 3 crashes
│   → If rollback works: node returns to previous version (check serial for "rolled back")
│   → If rollback fails or node is on first boot ever:
│       Flash via USB with Arduino IDE
│
└── Hardware causing reset (brown-out):
    Node resets when relay energises?
    → Power supply (HiLink) is under-rated or loose connection
    → Relay inrush current causing voltage dip → ESP32 brown-out reset
    → Add 100µF electrolytic capacitor across ESP32 Vin–GND
    → Check HiLink connections, consider HLK-PM03 (3W) instead of HLK-PM01 (1W)
```

---

## 14. WiFi Fails

```
Serial: "[NET] WiFi failed after 10s" or keeps trying

├── Check SSID and password in secrets.h
│   Common mistake: wrong case, trailing space, wrong SSID for 5GHz vs 2.4GHz
│   ESP32 only supports 2.4GHz WiFi — must use 2.4GHz band AP
│
├── Is the node too far from AP?
│   Bring node close to AP and test
│   If it works close but not at installation location:
│   → Add a WiFi range extender in the lab
│   → Typical ESP32 range: ~30m in open air, less with walls
│
├── Is the AP at capacity?
│   Home/budget routers often limit to 32 or 64 concurrent devices
│   If lab already has many devices: check AP's connected device count
│   → Upgrade AP or add second AP for MMS devices
│
└── Node connects but RSSI < -80 dBm (shown on OLED32 or serial):
    → Signal is too weak; expect intermittent disconnects
    → Relocate node or add AP
    → Acceptable RSSI: -30 to -67 dBm (good), -68 to -79 dBm (fair)
```

---

## 15. WS2812 Wrong Colour

```
LED is wrong colour (e.g., shows blue when it should be green)

├── This is a colour order issue
│   Default in firmware: NEO_GRB
│   Some WS2812 clones use RGB or BGR order
│   If red shows as green and vice versa: change to NEO_RGB
│   If red shows as blue: change to NEO_BRG
│   Update in led_controller.cpp and rebuild
│
├── LED not responding at all:
│   Check 470Ω resistor on DIN line (GPIO 33 → [470Ω] → DIN)
│   Check 5V on VCC (not 3.3V)
│   Check 100µF capacitor polarity (+ to VCC)
│   Flash `07_ws2812` test sketch to isolate
│
└── LED flickering or going white randomly:
    → Power supply noise
    → Add 100µF capacitor AT the LED (as close as possible, not at ESP32)
    → Check GND is connected
```

---

## Escalation Path

If a troubleshooting tree does not resolve the issue:

1. Document the full serial output (copy-paste from Serial Monitor)
2. Document the bridge log at the time of failure:
   `sudo journalctl -u mms-bridge --since "30 min ago"`
3. Document the RTDB and Firestore state at the time
4. Proceed to [Section 16 — Disaster Recovery](16_disaster_recovery.md) for component replacement procedures

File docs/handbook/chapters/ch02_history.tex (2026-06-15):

%% Chapter 2 — History and V1 Post-Mortem
\chapter{History and V1 Post-Mortem}
\label{ch:history}

\section{V1 System Background}

The original Machine Management System (V1) was built as a student project to introduce RFID-based access control to the Tinkerers' Lab. The V1 system used ESP32 microcontrollers with MFRC522 RFID readers and a Flask-based kiosk to issue cards. However, the system couldn't worked end-to-end and was never deployed in production.

A detailed audit of V1 identified multiple critical failures across the firmware, kiosk, web application, and backend layers.

\section{V1 Failure Analysis}

\begin{table}[H]
\centering
\caption{V1 Critical Bugs and Root Causes}
\label{tab:v1_bugs}
\begin{tabular}{C{0.8cm}L{4cm}L{5cm}L{4cm}}
\toprule
\textbf{\#} & \textbf{Bug} & \textbf{Effect} & \textbf{Root Cause} \\
\midrule
1 & RFID block mismatch & Kiosk writes blocks 1+2; nodes read block 5 — no valid read ever possible & Copy-paste error; never tested end-to-end \\
2 & Unhashed PINs & PINs stored in plaintext on card and Firestore & No security review \\
3 & Non-unique MQTT client IDs & All nodes use same ID; broker disconnects the previous when new node connects; only one node online at a time & MQTT spec not understood \\
4 & No watchdog & Firmware hangs cause node to stay in relay-ON state indefinitely & Not implemented \\
5 & Blocking \texttt{delay()} calls & Display updates and RFID polling compete; 200ms RFID scan blocks all other operations & Arduino delay() used in production code \\
6 & Wrong MFRC522 RST pin & RST on GPIO 34 (input-only on ESP32); can never be driven LOW; RFID module never resets correctly & ESP32 GPIO capabilities not checked \\
7 & Firestore: \texttt{addDoc} for users & User documents get auto-generated IDs instead of roll number as document ID; lookup by roll number impossible & Firebase API misuse \\
8 & No MQTT$\rightarrow$Firebase bridge & Session events published to MQTT never reach Firestore & Missing architectural component \\
9 & Machine name mismatch & \texttt{config.h} said ``Soldering Station 1'' for what is actually the 3D Printer & Manual entry error \\
\bottomrule
\end{tabular}
\end{table}

\section{V1 Deployment Blockers}

Beyond the bugs above, V1 had architectural gaps that would prevent reliable deployment even if the bugs were fixed:

\begin{itemize}[leftmargin=1.5em]
    \item No offline buffering: if WiFi is down during a session, the event is lost
    \item No OTA: firmware updates require physical access to each node
    \item No card revocation: a lost card cannot be invalidated without re-issuing every card
    \item No session timeout: a student who leaves without removing their card causes the machine to run indefinitely
    \item No admin remote control: no way to stop a machine remotely
    \item No stale command handling: a stop command stored when a node is offline would be executed on reconnect regardless of whether a session is active
\end{itemize}

\section{V2 Design Decisions Driven by V1 Failures}

Each major V2 design decision directly addresses a V1 failure:

\begin{description}[leftmargin=2em,font=\bfseries]
    \item[New RFID card schema (Sector 1, Blocks 4+5)] Fixes bug \#1. The schema is explicitly versioned (schema byte 0x02) so firmware can detect and reject V1 cards.
    \item[HMAC-SHA256 PIN hashing] Fixes bug \#2. PIN is never stored in plaintext anywhere. The hash is truncated to 8 bytes (64 bits) — sufficient for a 4-digit PIN with rate limiting.
    \item[Per-node unique MQTT client ID: \texttt{mms\_node\_\{id\}}] Fixes bug \#3. Client IDs are derived from the machine ID, guaranteed unique across all nodes.
    \item[30-second TWDT hardware watchdog] Fixes bug \#4. If firmware stalls for any reason, the ESP32 resets within 30 seconds.
    \item[Non-blocking millis()-based state machine] Fixes bug \#5. No \texttt{delay()} calls in production firmware. All timing is event-driven with \texttt{millis()} comparisons.
    \item[MFRC522 RST moved to GPIO 27] Fixes bug \#6. GPIO 27 is a standard bidirectional GPIO that can be driven both HIGH and LOW.
    \item[Firestore setDoc with roll number as key] Fixes bug \#7. \texttt{/users/\{roll\_number\}} is the document path; lookup by roll number is O(1).
    \item[bridge.py MQTT$\rightarrow$Firebase bridge] Fixes bug \#8. All session events flow: ESP32 $\rightarrow$ MQTT $\rightarrow$ bridge.py $\rightarrow$ Firestore. Bridge runs as a systemd service with automatic restart.
    \item[Canonical machine registry in three files] Fixes bug \#9. Machine names are documented in a central table. Any mismatch between config.h, seed\_machines.py, and config.py is a bug.
\end{description}

\section{Decision Records}

The following key architectural decisions were made during V2 design and are recorded here for future maintainers.

\subsection{Local Access Decision (No Cloud Call on Access Path)}

Access decisions (grant/deny) are made entirely on the ESP32, using card data read from the RFID chip and a revocation list cached in LittleFS. This means:
\begin{itemize}[leftmargin=1.5em]
    \item Access works if WiFi is down
    \item Access works if Firebase is down
    \item Access works if the RPi is down
    \item Latency of the access decision is deterministic (\textasciitilde{}100ms)
\end{itemize}

The trade-off is that card revocation can be delayed: a newly revoked card is denied only after the revocation list is pushed via MQTT and received by the node. If the node is offline, the revoked card may be accepted until the node reconnects.

\subsection{Card Carries Permissions}

Machine permissions are stored on the physical RFID card (Block 5, bytes 8--11, uint32 bitmask). The node does not look up permissions in Firebase or any network service. This means:
\begin{itemize}[leftmargin=1.5em]
    \item Permission changes require a card re-issue
    \item Compromised cards carry wrong permissions until revoked
    \item No network call needed for the access decision
\end{itemize}

Alternative considered: store permissions in Firebase and look them up on each tap. Rejected because it breaks offline operation.

\subsection{Per-Card Sector Key Derivation}

Each RFID card's Sector 1 is protected by a unique 6-byte key derived as:
\[
\text{sector\_key}[6] = \text{HMAC-SHA256}(\text{master\_key},\, \text{uid\_hex\_uppercase})[0..5]
\]

This ensures that knowledge of one card's sector key does not help an attacker forge another card. The master key is the only secret that must be protected system-wide.

\subsection{5-Minute Command TTL}

Remote stop commands have a 5-minute TTL. A command older than 300 seconds is discarded without execution. This prevents a node from executing a stop command that was issued while it was offline, after it reconnects and the context has changed.

\subsection{MQTT Buffer Size 1536 Bytes}

PubSubClient's default buffer is 256 bytes, which is insufficient for MQTT messages containing the full revocation list (multiple UIDs as JSON). The buffer was increased to 1536 bytes in \texttt{mqtt\_client.cpp}.

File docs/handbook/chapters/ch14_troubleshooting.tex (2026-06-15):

%% Chapter 14 — Troubleshooting
\chapter{Troubleshooting}
\label{ch:troubleshooting}

\section{Quick Diagnostic Reference}

\begin{table}[H]
\centering
\caption{Symptom to First Action}
\begin{tabular}{L{5.5cm}L{9cm}}
\toprule
\textbf{Symptom} & \textbf{First action} \\
\midrule
OLED blank & Check 3.3V on OLED VCC; flash test sketch 04 or 05 \\
Card inserted, no reaction & Flash \texttt{06\_hc89}; confirm HC89 OUT wired to GPIO 32 \\
Card denied (should be allowed) & Check serial for denial reason; verify permissions in Firestore \\
Relay doesn't energise & Check relay LED; measure GPIO 26 with multimeter during session \\
MQTT keeps reconnecting & Check Mosquitto status on RPi; confirm MQTT\_BROKER IP \\
Sessions missing from Firestore & Check bridge logs; curl bridge health endpoint \\
Dashboard shows offline & Check node MQTT; check bridge health; check RTDB subscription in web app \\
Remote stop not working & Check RTDB /mms/commands; check bridge logs; check 5-min TTL \\
OTA stuck & Check Firebase Storage URL; check bridge OTA listener in logs \\
Node rebooting in loop & Check serial for boot reason; watchdog or OTA crash rollback \\
\bottomrule
\end{tabular}
\end{table}

\section{Serial Monitor Diagnostic Commands}

When a node is connected via USB, its Serial Monitor (115200 baud) provides the most direct diagnostic information:

\begin{table}[H]
\centering
\caption{Diagnostic Log Prefixes}
\begin{tabular}{L{2.5cm}L{11cm}}
\toprule
\textbf{Prefix} & \textbf{Meaning} \\
\midrule
\texttt{[HW]} & Hardware initialisation events (boot only) \\
\texttt{[NET]} & WiFi connection events \\
\texttt{[MQTT]} & MQTT connection, publish, subscribe, receive events \\
\texttt{[RFID]} & Card detection and read events \\
\texttt{[ACCESS]} & Access grant or denial with reason \\
\texttt{[RELAY]} & Relay state changes \\
\texttt{[SESSION]} & Session start, end, timeout events \\
\texttt{[FS]} & LittleFS operations \\
\texttt{[NVS]} & NVS reads and writes \\
\texttt{[OTA]} & OTA update progress \\
\texttt{[SYS]} & System events: boot reason, watchdog, state transitions \\
\texttt{[ERR]} & Error conditions \\
\bottomrule
\end{tabular}
\end{table}

\section{Common Issues}

\subsection{RFID Authentication Failure}

\begin{verbatim}
[RFID] Auth FAILED for UID: A1B2C3D4
\end{verbatim}

\textbf{Causes:}
\begin{itemize}[leftmargin=1.5em,noitemsep]
    \item Card written with a different master key than what is in \texttt{secrets.h}
    \item Card is not MIFARE Classic 1K (NFC tags, bank cards, transit cards fail)
    \item Card is a fresh/blank card with default Key A (\texttt{0xFFFFFFFFFFFF}) but the node tries the derived key first
\end{itemize}

\textbf{Fix}: Verify the master key is identical in all three locations. For fresh cards: the kiosk writes the derived key --- node should then authenticate with the derived key. If a card was written by a different kiosk (different master key), it cannot be read by this node.

\subsection{Schema Version Mismatch}

\begin{verbatim}
[RFID] Schema version: 0x01 (expected 0x02) — ACCESS DENIED
\end{verbatim}

\textbf{Cause}: Card was issued by V1 kiosk (old system).

\textbf{Fix}: Re-issue the card at the V2 kiosk.

\subsection{Bridge PERMISSION\_DENIED on Firestore}

\begin{verbatim}
[FIREBASE] Error writing session: 403 PERMISSION_DENIED
\end{verbatim}

\textbf{Cause}: The service account used by bridge.py does not have Firebase Admin SDK permissions.

\textbf{Fix}: Firebase Console $\rightarrow$ IAM $\rightarrow$ check the service account has ``Firebase Admin'' or ``Editor'' role. The service account email is shown in the \texttt{service-account.json} file.

\subsection{WiFi RSSI Too Low}

\begin{verbatim}
[NET] WiFi connected — IP: 192.168.0.101, RSSI: -84 dBm
\end{verbatim}

\textbf{Cause}: Node is too far from the WiFi AP.

\textbf{Impact}: Intermittent MQTT disconnects; sessions buffered in LittleFS but may not flush promptly.

\textbf{Fix}: Add a WiFi access point or range extender nearer to the machine. Acceptable RSSI: $>-80$ dBm. Ideal: $>-67$ dBm.

\section{Recovery Procedures}

See the Deployment Package (Section 16) for complete disaster recovery procedures covering:
\begin{itemize}[leftmargin=1.5em,noitemsep]
    \item Raspberry Pi hardware failure
    \item Firebase outage
    \item ESP32 hardware failure
    \item Lost master key
    \item Corrupted firmware (all nodes)
    \item Lost Firebase admin access
    \item Database corruption
\end{itemize}

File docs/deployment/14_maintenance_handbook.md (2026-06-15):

# Section 14 — Maintenance Handbook

← [Production Rollout](13_production_rollout.md) | → [Troubleshooting Guide](15_troubleshooting_guide.md)

---

## Overview

This section covers routine maintenance: daily checks, weekly tasks, monthly tasks, firmware updates, and database housekeeping. Following this schedule prevents most preventable failures.

---

## Daily Checks (5 minutes)

**Who:** Any lab admin with web app access.

```
1. Open web dashboard
2. Check all 5 machines show status (idle or active — not "offline" or "error")
3. Look for any session stuck in "active" state for more than 2 hours
   → If found: Remote Stop → check the physical machine
4. Check that RTDB /mms/bridge/status.state = "online"
   → If "offline": check RPi (see Troubleshooting Section 15)
```

If everything looks normal, daily check is done in under 2 minutes.

---

## Weekly Tasks (30 minutes)

**Who:** Lab admin or coordinator.

### 1. Check RPi health

```bash
ssh pi@192.168.0.10

# System resources
df -h /         # Disk usage — alert if > 80%
free -h         # RAM — alert if available < 100MB
uptime          # Load average — alert if 15-min avg > 2.0

# Bridge service health
sudo systemctl status mms-bridge
# Should be: Active: active (running)

# Bridge log — look for repeated errors
sudo journalctl -u mms-bridge --since "7 days ago" | grep -i "error\|exception\|failed" | tail -30
```

### 2. Rotate LittleFS logs (automatic — verify)

LittleFS logs rotate automatically at 50KB. But confirm no node has stale logs:
```
Check Serial Monitor on each node after a restart:
"[FS] sessions.jsonl: 0 bytes (flushed)"  ← good
"[FS] sessions.jsonl: 48000 bytes"        ← near rotation, will auto-rotate
"[FS] sessions.old.jsonl exists"          ← previous rotation preserved
```

If a node shows `sessions.jsonl` size growing indefinitely and never flushing, the MQTT connection may be broken silently — check that node's WiFi status.

### 3. Verify card stock

Count remaining blank MIFARE Classic 1K cards. Reorder when fewer than 20 remain. Cards needed: approximately 2 per new student enrolled.

### 4. Check Firestore index status

```bash
# From your laptop with Firebase CLI:
firebase firestore:indexes
# All 3 composite indexes should show status "Enabled"
# "Building" or "Error" status needs attention
```

---

## Monthly Tasks (1 hour)

### 1. Backup RPi SD card

```bash
# On your laptop with SD card reader:
# Shut down RPi first: ssh pi@192.168.0.10 "sudo shutdown now"
# Wait 30 seconds, then remove SD card

# Linux:
sudo dd if=/dev/sdX of=mms-bridge-$(date +%Y%m%d).img bs=4M status=progress

# Or use Raspberry Pi Imager → "Read" option

# Store backup on a separate drive or encrypted cloud storage
# Keep last 3 monthly backups; delete older ones
```

### 2. Check Firestore quota usage

- Firebase Console → Project Settings → Usage and billing
- Firestore reads/writes/deletes — should be well within Spark free tier limits
- At 15 machines × 30 sessions/day = 450 writes/day → 13,500 writes/month → far below Spark's 50,000/day

### 3. Archive old sessions (optional, after 6 months)

If the sessions collection grows large (>10,000 documents), sessions older than 3 months can be archived:

```python
# On your laptop:
from firebase_admin import credentials, firestore, initialize_app
import datetime

cred = credentials.Certificate("service-account.json")
initialize_app(cred)
db = firestore.client()

cutoff = datetime.datetime(2024, 1, 1)  # adjust date

old_sessions = db.collection("sessions").where("start_time", "<", cutoff).stream()
for doc in old_sessions:
    # Export to local JSONL file before deleting
    with open("archive_sessions.jsonl", "a") as f:
        f.write(doc.to_dict().__str__() + "\n")
    doc.reference.delete()
    print(f"Archived: {doc.id}")
```

### 4. Review and rotate MQTT password (if authentication enabled)

If MQTT authentication was enabled post-deployment (per Section 07):
- Rotate the `bridge` MQTT password every 3 months
- Update `/home/pi/mms/.env` MQTT_PASS
- Regenerate Mosquitto password file: `sudo mosquitto_passwd /etc/mosquitto/passwd bridge`
- Restart Mosquitto: `sudo systemctl restart mosquitto`
- Restart bridge: `sudo systemctl restart mms-bridge`

---

## Firmware Update Procedure

This is the standard OTA update path. Use it whenever a new firmware version is ready.

### Step 1 — Build the firmware binary

In Arduino IDE with the production access_node project open:
1. Sketch → Export Compiled Binary
2. Find the `.bin` file in the sketch folder (e.g., `access_node.ino.esp32.bin`)
3. Note the version number — update `#define FW_VERSION "2.x.x"` in `config.h` before building

### Step 2 — Upload to Firebase Storage

1. Firebase Console → Storage → `firmware/` folder
2. Upload the `.bin` file, naming it by version: `firmware/2.1.0.bin`
3. Click the uploaded file → copy the **download URL** (it is a long URL starting with `https://firebasestorage.googleapis.com/...`)

### Step 3 — Trigger OTA via RTDB

In Firebase Console → Realtime Database:
```
Set /mms/ota to:
{
  "firmware_url": "https://firebasestorage.googleapis.com/.../firmware/2.1.0.bin",
  "target_version": "2.1.0",
  "released_at": <current unix timestamp>
}
```

Or via web app: Super Admin Panel → OTA Update → paste URL and version → Submit.

### Step 4 — Monitor rollout

Each node will:
1. Receive OTA command from bridge (MQTT)
2. Transition to OTA state: OLED shows "Updating FW..."
3. Download firmware from URL (~45s on typical WiFi)
4. Reboot to new firmware
5. Report new version in RTDB `/mms/nodes/{id}/firmware_version`

Monitor on dashboard:
```
Node 1: updating... → idle (v2.1.0)  ✓
Node 2: updating... → idle (v2.1.0)  ✓
...
```

If a node shows `error` state after OTA:
- It rebooted but firmware has a critical bug
- Firmware's rollback mechanism activates after 3 crashes
- Node reverts to previous version automatically
- Check serial output for specific error

### Step 5 — Verify OTA success

After all nodes report the new version:
1. Run integration test (partial — just Tests 1, 4, 5) on one node
2. Confirm session logging still works with new firmware
3. Update the firmware version in deployment documentation

---

## Database Maintenance

### Cleaning up orphaned sessions

An "orphaned active session" is a Firestore session document with `status:"active"` but no corresponding activity on the node. This happens during power loss or network errors.

**Detect:**
```javascript
// Firebase Console → Firestore → sessions → filter: status == "active"
// Any session with start_time > 3 hours ago is orphaned
```

**Fix (via Firebase Console):**
- Find the document
- Set `status` to `"completed"`, set `end_time` to current timestamp
- Set `end_reason` to `"power_loss"`

**Automated cleanup script (run weekly via cron on RPi):**
```python
# /home/pi/mms/cleanup_orphans.py
from firebase_admin import credentials, firestore, initialize_app
import datetime

cred = credentials.Certificate("/home/pi/mms/service-account.json")
initialize_app(cred)
db = firestore.client()

cutoff = datetime.datetime.utcnow() - datetime.timedelta(hours=3)

orphans = (
    db.collection("sessions")
    .where("status", "==", "active")
    .where("start_time", "<", cutoff)
    .stream()
)

for doc in orphans:
    doc.reference.update({
        "status": "completed",
        "end_time": firestore.SERVER_TIMESTAMP,
        "end_reason": "power_loss",
    })
    print(f"Cleaned orphan: {doc.id}")
```

Add to RPi crontab:
```bash
crontab -e
# Add:
0 3 * * * /home/pi/mms/venv/bin/python3 /home/pi/mms/cleanup_orphans.py >> /var/log/mms-cleanup.log 2>&1
```

### Cleaning up stale RTDB commands

If a command sits in RTDB `/mms/commands/{id}` unacknowledged for more than 10 minutes, the bridge should auto-clean it. If it does not (bridge was down), clean manually:
```
RTDB Console → /mms/commands → delete the specific machine's command node
```

---

## Log Management

### RPi journal log rotation

systemd journal rotates logs automatically. Verify rotation is configured:
```bash
sudo journalctl --disk-usage
# Typical: Archived and active journals take up 200.0M in /var/log/journal/
# This is fine. systemd limits journal to 10% of filesystem by default.
```

### Mosquitto log rotation

```bash
# Mosquitto logs to syslog. Check:
sudo grep mosquitto /var/log/syslog | tail -20
# Or
sudo journalctl -u mosquitto --since "1 day ago" | tail -30
```

---

## Summary Schedule

| Task | Frequency | Time | Who |
|---|---|---|---|
| Dashboard health check | Daily | 2 min | Admin |
| RPi health check | Weekly | 10 min | Admin |
| Firestore index check | Weekly | 2 min | Admin |
| Card stock count | Weekly | 2 min | Coordinator |
| RPi SD card backup | Monthly | 30 min | Admin |
| Firestore quota review | Monthly | 5 min | Admin |
| Orphan session cleanup (manual check) | Monthly | 10 min | Admin |
| MQTT password rotation | Quarterly | 15 min | Admin |
| Firmware update (as needed) | Per release | 30 min | Admin |

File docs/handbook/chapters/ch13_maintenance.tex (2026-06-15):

%% Chapter 13 — Maintenance Procedures
\chapter{Maintenance Procedures}
\label{ch:maintenance}

\section{Maintenance Schedule Summary}

\begin{table}[H]
\centering
\caption{Maintenance Schedule}
\begin{tabular}{L{3cm}L{4.5cm}L{5.5cm}C{2cm}}
\toprule
\textbf{Frequency} & \textbf{Task} & \textbf{What to check} & \textbf{Time} \\
\midrule
Daily & Dashboard health check & All machines showing status; no stuck active sessions & 2 min \\
Weekly & RPi health check & Disk, RAM, bridge logs for errors & 10 min \\
Weekly & Firestore index check & All 3 indexes show ``Enabled'' & 2 min \\
Weekly & Card stock count & Reorder when $<$20 blank cards & 2 min \\
Monthly & RPi SD card backup & \texttt{dd} image to secure storage & 30 min \\
Monthly & Firestore quota review & Usage within Spark free tier limits & 5 min \\
Monthly & Orphaned session cleanup & No \texttt{status:active} documents $>$3 hours old & 10 min \\
Quarterly & MQTT password rotation & Change bridge and node MQTT passwords & 15 min \\
As needed & Firmware update & OTA or direct flash; run regression tests & 30 min \\
\bottomrule
\end{tabular}
\end{table}

\section{Firmware Update Procedure}

\begin{enumerate}[leftmargin=1.5em]
    \item Update \texttt{FW\_VERSION} in \texttt{config.h} (e.g., ``2.1.0'')
    \item Build in Arduino IDE: Sketch $\rightarrow$ Export Compiled Binary
    \item Upload \texttt{.bin} to Firebase Storage: \texttt{firmware/2.1.0.bin}
    \item Copy the download URL from the uploaded file
    \item Write to RTDB \texttt{/mms/ota}:
\begin{lstlisting}[style=jsonlstyle]
{
  "firmware_url":   "https://firebasestorage.googleapis.com/.../2.1.0.bin",
  "target_version": "2.1.0",
  "released_at":    <current unix timestamp>
}
\end{lstlisting}
    \item Monitor dashboard: each node shows ``updating... $\rightarrow$ idle (v2.1.0)''
    \item Verify on Serial Monitor: \texttt{[OTA] Update complete — v2.0.0 $\rightarrow$ v2.1.0}
    \item Run regression tests (Chapter~\ref{ch:testing}, Section 4)
\end{enumerate}

\begin{warnbox}
Always test OTA on one node at a bench before pushing to production. Keep the last known-good \texttt{.bin} file archived locally. If OTA fails on all nodes, manual USB flash recovery is required.
\end{warnbox}

\section{Card Management}

\subsection{Issuing a New Card}
\begin{enumerate}[leftmargin=1.5em]
    \item Admin creates student in web app (User Management $\rightarrow$ Add User)
    \item At kiosk station: start Flask app (\texttt{python3 app.py})
    \item Select student from dropdown; confirm machine permissions
    \item Click ``Issue Card''; place blank MIFARE Classic 1K card on reader
    \item Wait for ``WRITE\_SUCCESS''; card is personalised
    \item Verify: take card to a node; confirm access is granted for permitted machines
\end{enumerate}

\subsection{Revoking a Card (Lost/Stolen)}
\begin{enumerate}[leftmargin=1.5em]
    \item Web app $\rightarrow$ User Management $\rightarrow$ select student $\rightarrow$ Revoke Card
    \item All nodes receive revocation within 5s (if online)
    \item Issue a replacement card (new blank card; new UID $\rightarrow$ new sector key)
\end{enumerate}

\section{Bridge Maintenance}

\begin{lstlisting}[style=bashstyle]
# Check bridge status
sudo systemctl status mms-bridge

# Restart bridge (if needed)
sudo systemctl restart mms-bridge

# Watch logs live
sudo journalctl -u mms-bridge -f

# Check for errors in last 7 days
sudo journalctl -u mms-bridge --since "7 days ago" | grep -i "error|exception|failed"
\end{lstlisting}

\section{Database Cleanup}

\subsection{Orphaned Sessions}

Sessions with \texttt{status: "active"} older than 3 hours are orphaned (caused by power loss or network failure during session):

\begin{lstlisting}[style=bashstyle]
# On RPi, run the cleanup script
/home/pi/mms/venv/bin/python3 /home/pi/mms/cleanup_orphans.py
# Or add to crontab (runs daily at 3am):
# 0 3 * * * /home/pi/mms/venv/bin/python3 /home/pi/mms/cleanup_orphans.py
\end{lstlisting}

\subsection{Stale RTDB Commands}

The bridge auto-cleans commands older than 10 minutes. To clean manually:
\begin{itemize}[leftmargin=1.5em]
    \item Firebase Console $\rightarrow$ RTDB $\rightarrow$ \texttt{mms/commands} $\rightarrow$ delete specific node's command
\end{itemize}

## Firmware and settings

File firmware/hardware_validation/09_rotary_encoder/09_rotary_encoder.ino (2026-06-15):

/*
 * TEST 09 — Rotary Encoder (EC11) Validation
 * MMS V2 Hardware Validation Package
 *
 * Tests: CW/CCW direction detection, step count accuracy, push-button
 *        press/release detection, hold duration, false-trigger count
 *
 * Wiring:
 *   Encoder VCC (+) → 3V3
 *   Encoder GND (-) → GND
 *   Encoder CLK (A) → GPIO 34  [INPUT-ONLY — NO internal pull-up]
 *   Encoder DT  (B) → GPIO 35  [INPUT-ONLY — NO internal pull-up]
 *   Encoder SW      → GPIO 25  [INPUT_PULLUP available]
 *
 * REQUIRED external pull-ups (if not on module board):
 *   10kΩ from GPIO 34 → 3V3
 *   10kΩ from GPIO 35 → 3V3
 *   (GPIO 25 uses internal pull-up — no external resistor needed)
 *
 * EC11 mechanics: 2 pulses per physical detent step.
 *   This sketch counts HALF-steps (each pulse). Divide by 2 for click count.
 *
 * Serial: 115200 baud
 * Phase 4 hardware — not populated on initial MMS V2 deployment.
 */

#include <Arduino.h>

#define PIN_CLK   34    // Input-only, external pull-up required
#define PIN_DT    35    // Input-only, external pull-up required
#define PIN_SW    25    // Input with internal pull-up

// Debounce
#define BUTTON_DEBOUNCE_MS  20
#define ENCODER_MIN_PULSE_US 1000  // Ignore pulses shorter than this (noise filter)

// Validation targets
#define TARGET_CW_STEPS   10
#define TARGET_CCW_STEPS  10

volatile int32_t  encoderPos       = 0;
volatile int32_t  cwCount          = 0;
volatile int32_t  ccwCount         = 0;
volatile uint32_t falseTriggers    = 0;
volatile bool     newEncoderEvent  = false;
volatile bool     lastEncoderDir   = true;  // true=CW, false=CCW

static bool   lastButtonState     = HIGH;
static bool   stableButtonState   = HIGH;
static uint32_t debounceStart     = 0;
static uint32_t buttonPressTime   = 0;
static uint32_t totalButtonPresses = 0;

static uint8_t passCount = 0;
static uint8_t failCount = 0;

// ── ISR ──────────────────────────────────────────────────────────────────────

// Interrupt on CLK rising edge
// Direction determined by DT state at CLK rising edge:
//   DT HIGH → CW; DT LOW → CCW
void IRAM_ATTR onClkRising() {
    static uint32_t lastPulseUs = 0;
    uint32_t now = micros();

    // Noise filter: ignore if pulse came too quickly
    if ((now - lastPulseUs) < ENCODER_MIN_PULSE_US) {
        falseTriggers++;
        return;
    }
    lastPulseUs = now;

    bool dt = (bool)digitalRead(PIN_DT);
    if (dt) {
        // DT HIGH at CLK rising = Clockwise
        encoderPos++;
        cwCount++;
        lastEncoderDir = true;
    } else {
        // DT LOW at CLK rising = Counter-clockwise
        encoderPos--;
        ccwCount++;
        lastEncoderDir = false;
    }
    newEncoderEvent = true;
}

// ── Helpers ─────────────────────────────────────────────────────────────────

static void printSeparator() { Serial.println(F("========================================")); }
static void pass(const char* msg) { Serial.print(F("[PASS] ")); Serial.println(msg); passCount++; }
static void fail(const char* msg) { Serial.print(F("[FAIL] ")); Serial.println(msg); failCount++; }
static void info(const char* msg) { Serial.print(F("[INFO] ")); Serial.println(msg); }

static void checkPullUps() {
    // With pull-ups in place, pins should read HIGH at rest
    bool clkHigh = (digitalRead(PIN_CLK) == HIGH);
    bool dtHigh  = (digitalRead(PIN_DT)  == HIGH);

    Serial.print(F("[INFO] GPIO 34 (CLK) at rest: "));
    Serial.println(clkHigh ? F("HIGH (pull-up OK)") : F("LOW  — CHECK EXTERNAL PULL-UP"));

    Serial.print(F("[INFO] GPIO 35 (DT ) at rest: "));
    Serial.println(dtHigh  ? F("HIGH (pull-up OK)") : F("LOW  — CHECK EXTERNAL PULL-UP"));

    if (clkHigh && dtHigh) {
        pass("CLK and DT pull-ups confirmed — pins HIGH at rest");
    } else {
        fail("CLK or DT not HIGH at rest — add 10kΩ pull-ups from GPIO 34/35 to 3V3");
        Serial.println(F("[INFO] Without pull-ups: random counting will occur without rotation"));
    }

    bool swHigh = (digitalRead(PIN_SW) == HIGH);
    Serial.print(F("[INFO] GPIO 25 (SW ) at rest: "));
    Serial.println(swHigh ? F("HIGH (internal pull-up OK)") : F("LOW  — button pressed or short"));

    if (swHigh) {
        pass("SW pull-up confirmed — button reads HIGH when released");
    } else {
        Serial.println(F("[WARN] SW reads LOW — button may be pressed, or check wiring"));
    }
}

static void printEncoderStatus() {
    Serial.print(F("[STATE] Position: "));
    Serial.print(encoderPos);
    Serial.print(F("  CW: "));
    Serial.print(cwCount);
    Serial.print(F("  CCW: "));
    Serial.print(ccwCount);
    Serial.print(F("  false: "));
    Serial.print(falseTriggers);
    Serial.print(F("  button_presses: "));
    Serial.println(totalButtonPresses);
}

// ── Button polling (debounced in main loop — not interrupt) ──────────────────

static void pollButton() {
    bool rawState = (bool)digitalRead(PIN_SW);
    uint32_t now  = millis();

    if (rawState != lastButtonState) {
        debounceStart  = now;
        lastButtonState = rawState;
    }

    if ((now - debounceStart) >= BUTTON_DEBOUNCE_MS && rawState != stableButtonState) {
        stableButtonState = rawState;

        if (rawState == LOW) {
            // Pressed
            buttonPressTime = now;
            totalButtonPresses++;
            Serial.println(F("[EVENT] BUTTON PRESSED"));
        } else {
            // Released
            uint32_t held = now - buttonPressTime;
            Serial.print(F("[EVENT] BUTTON RELEASED  held="));
            Serial.print(held);
            Serial.println(F("ms"));

            // Reset encoder position on press
            encoderPos = 0;
            Serial.println(F("[INFO] Position reset to 0"));
        }
    }
}

// ── Validation phases ────────────────────────────────────────────────────────

static void runValidationPhase() {
    static uint8_t phase = 0;
    static bool phasePrinted = false;

    if (!phasePrinted) {
        phasePrinted = true;
        switch (phase) {
            case 0:
                Serial.println();
                Serial.println(F("[PHASE 1] Rotate CW 10 clicks to validate CW detection"));
                break;
            case 1:
                Serial.println();
                Serial.println(F("[PHASE 2] Rotate CCW 10 clicks to validate CCW detection"));
                break;
            case 2:
                Serial.println();
                Serial.println(F("[PHASE 3] Press button 3 times to validate push-button"));
                break;
            case 3:
                // Done
                Serial.println();
                printSeparator();
                Serial.println(F(" VALIDATION SUMMARY"));
                printSeparator();
                printEncoderStatus();
                Serial.println();

                if (cwCount >= TARGET_CW_STEPS)
                    pass("CW rotation detected (>= 10 steps)");
                else {
                    Serial.print(F("[FAIL] CW only ")); Serial.print(cwCount); Serial.println(F(" steps"));
                    failCount++;
                }

                if (ccwCount >= TARGET_CCW_STEPS)
                    pass("CCW rotation detected (>= 10 steps)");
                else {
                    Serial.print(F("[FAIL] CCW only ")); Serial.print(ccwCount); Serial.println(F(" steps"));
                    failCount++;
                }

                if (totalButtonPresses >= 3)
                    pass("Push-button press detected (>= 3 presses)");
                else {
                    Serial.print(F("[FAIL] Only ")); Serial.print(totalButtonPresses); Serial.println(F(" button presses detected"));
                    failCount++;
                }

                if (falseTriggers < 10)
                    pass("False trigger count within tolerance (< 10)");
                else {
                    Serial.print(F("[WARN] "));
                    Serial.print(falseTriggers);
                    Serial.println(F(" false triggers — add pull-ups or reduce encoder cable length"));
                }

                Serial.println();
                Serial.print(F(" STATUS: "));
                Serial.println(failCount == 0 ? F("PASS") : F("FAIL — see above"));
                printSeparator();

                // Reset and loop
                cwCount = 0; ccwCount = 0; falseTriggers = 0; totalButtonPresses = 0;
                phase = 0;
                phasePrinted = false;
                Serial.println(F("[INFO] Counters reset — press reset or continue."));
                return;
        }
    }

    // Phase advancement logic
    switch (phase) {
        case 0: if (cwCount  >= TARGET_CW_STEPS)   { pass("CW phase complete");  phase++; phasePrinted = false; } break;
        case 1: if (ccwCount >= TARGET_CCW_STEPS)   { pass("CCW phase complete"); phase++; phasePrinted = false; } break;
        case 2: if (totalButtonPresses >= 3)         { pass("Button phase complete"); phase++; phasePrinted = false; } break;
    }
}

// ── Setup / Loop ─────────────────────────────────────────────────────────────

void setup() {
    Serial.begin(115200);
    delay(500);

    printSeparator();
    Serial.println(F(" MMS V2 — Test 09: Rotary Encoder (EC11)"));
    printSeparator();

    Serial.print(F("[INFO] CLK=GPIO34  DT=GPIO35  SW=GPIO25"));
    Serial.println();
    Serial.println(F("[INFO] GPIO 34/35 are INPUT-ONLY — no internal pull-ups"));
    Serial.println(F("[INFO] External 10kΩ pull-ups required from GPIO 34/35 to 3V3"));
    Serial.println();

    pinMode(PIN_CLK, INPUT);        // INPUT only — no PULLUP available
    pinMode(PIN_DT,  INPUT);        // INPUT only — no PULLUP available
    pinMode(PIN_SW,  INPUT_PULLUP); // Has internal pull-up

    delay(50);  // Settle

    checkPullUps();
    Serial.println();

    // Attach interrupt on CLK rising edge
    attachInterrupt(digitalPinToInterrupt(PIN_CLK), onClkRising, RISING);
    info("Encoder interrupt attached on CLK (GPIO 34) RISING edge");
    Serial.println();
}

void loop() {
    // Process encoder events
    if (newEncoderEvent) {
        noInterrupts();
        bool dir = lastEncoderDir;
        int32_t pos = encoderPos;
        newEncoderEvent = false;
        interrupts();

        Serial.print(F("[EVENT] "));
        Serial.print(dir ? F("CW ") : F("CCW"));
        Serial.print(F("  Position: "));
        Serial.println(pos);
    }

    pollButton();
    runValidationPhase();
    delay(5);
}

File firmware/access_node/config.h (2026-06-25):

#pragma once

// ---------------------------------------------------------------------------
// CANONICAL MACHINE ID TABLE
// These IDs MUST be consistent across three places:
//   1. This file (MACHINE_ID per node)
//   2. kiosk_station/config.py  MACHINE_IDS dict values
//   3. Firestore /machines/{id} document IDs
//
//   ID | Machine Name
//   ---+------------------------
//    1 | Creality 3D Printer
//    2 | Fracktal Laser Cutter
//    3 | Soldering Station 1
//    4 | Soldering Station 2
//    5 | Bosche Grinder
//
// Before flashing a node: set MACHINE_ID and MACHINE_NAME to the correct
// row from the table above. Mismatch = wrong permission bit checked = access
// denied for everyone, or access granted to the wrong machine.
// ---------------------------------------------------------------------------

// ---------------------------------------------------------------------------
// Per-node configuration — edit before flashing each node
// ---------------------------------------------------------------------------

#define MACHINE_ID    1                          // 1–32; must match Firestore /machines/{id}
#define MACHINE_NAME  "Creality 3D Printer"      // Must match the name for MACHINE_ID above
#define SESSION_LIMIT_MIN 15                     // Default session limit in minutes

// ---------------------------------------------------------------------------
// Network
// ---------------------------------------------------------------------------
#define MQTT_BROKER   "192.168.0.10"             // Raspberry Pi static IP
#define MQTT_PORT     1883

// ---------------------------------------------------------------------------
// Hardware pin assignments
// ---------------------------------------------------------------------------

// MFRC522 RFID reader (SPI)
#define PIN_RFID_SS   5
#define PIN_RFID_RST  27   // NOT GPIO 34 (input-only); was wrong in V1

// SPI bus (shared)
#define PIN_SPI_SCK   18
#define PIN_SPI_MISO  19
#define PIN_SPI_MOSI  23

// 128x64 OLED (SPI — primary display)
#define PIN_OLED64_DC   17
#define PIN_OLED64_CS   16
#define PIN_OLED64_RST  4

// 128x32 OLED (I2C — status strip)
#define PIN_I2C_SDA   21
#define PIN_I2C_SCL   22
#define OLED32_I2C_ADDR 0x3C

// Relay / SSR
#define PIN_RELAY     26

// HC89 slot sensor (card present = LOW with INPUT_PULLUP)
#define PIN_SLOT      32

// Current sensor (ACS712 or similar) — ADC1 CH0 (input-only; no pull-up available)
#define PIN_CURRENT_SENSOR  36

// WS2812 RGB LED (optional, deferred to Phase 3)
#define PIN_LED       33
#define LED_COUNT     1

// Onboard LED (WiFi status indicator)
#define PIN_WIFI_LED  2

// ---------------------------------------------------------------------------
// Tuning
// ---------------------------------------------------------------------------
#define SLOT_DEBOUNCE_MS      50
#define RFID_READ_TIMEOUT_MS  2000
#define SESSION_WARNING_SEC   120    // 2 minutes before limit
#define WATCHDOG_TIMEOUT_SEC  30
#define MQTT_RECONNECT_DELAY_MS 5000
#define LOG_ROTATE_BYTES      51200  // 50 KB
#define HEARTBEAT_INTERVAL_MS 30000
#define NTP_SYNC_INTERVAL_MS  3600000  // 1 hour

// ---------------------------------------------------------------------------
// RFID card schema
// ---------------------------------------------------------------------------
#define CARD_SCHEMA_VERSION   0x02
#define CARD_SECTOR           1
#define CARD_BLOCK_IDENTITY   4
#define CARD_BLOCK_AUTH       5
#define CARD_BLOCK_RESERVED   6
#define CARD_SECTOR_TRAILER   7

// ---------------------------------------------------------------------------
// Firmware version
// ---------------------------------------------------------------------------
#define FW_VERSION  "2.0.0"

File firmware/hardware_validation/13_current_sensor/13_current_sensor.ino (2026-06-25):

/**
 * MMS V2 — Test 13: Current Sensor (ADC)
 *
 * Validates that GPIO 36 (ADC1 CH0 / SVP) can be read as an analog input.
 * Prints the raw 12-bit ADC count (0–4095) to Serial at 115200 baud.
 *
 * Hardware required: ESP32, current sensor module wired to GPIO 36, USB cable
 * Hardware optional: Multimeter (verify sensor VCC)
 *
 * No libraries beyond ESP32 Arduino core are needed.
 *
 * Expected output with sensor powered and connected:
 *   A non-zero, stable ADC reading proportional to the measured current.
 *   With no current flowing through the sensor, the reading is typically
 *   around the sensor's quiescent output voltage (e.g. ~2048 for ACS712 at
 *   zero current on a 3.3V supply). Exact value depends on the sensor model.
 *
 * Future processing (calibration, filtering, amp conversion) will be added
 * to firmware/access_node/current_sensor.cpp — not here.
 */

#define PIN_CURRENT_SENSOR  36   // ADC1 CH0 (SVP) — input-only pin

#define SAMPLE_INTERVAL_MS  500  // Print rate
#define PRINT_HEADER_EVERY  20   // Reprint column header every N rows

void setup() {
    Serial.begin(115200);
    delay(500);

    Serial.println(F("========================================"));
    Serial.println(F(" MMS V2 — Test 13: Current Sensor (ADC)"));
    Serial.println(F("========================================"));
    Serial.println(F("[INFO] GPIO 36 = ADC1 CH0 (SVP) — input-only"));
    Serial.println(F("[INFO] ADC resolution: 12-bit (0–4095)"));
    Serial.println(F("[INFO] ADC range: 0–3.3V (default 11dB attenuation)"));
    Serial.println(F("[INFO] No processing applied — raw counts only"));
    Serial.println();

    // GPIO 36 is input-only; pinMode INPUT documents intent
    pinMode(PIN_CURRENT_SENSOR, INPUT);

    // Phase 1: confirm pin is readable (any non-stuck value)
    Serial.println(F("[INFO] === Phase 1: Single-shot read ==="));
    uint16_t sample = (uint16_t)analogRead(PIN_CURRENT_SENSOR);
    Serial.print(F("[INFO] GPIO 36 raw ADC = "));
    Serial.println(sample);

    if (sample == 0 || sample == 4095) {
        Serial.println(F("[WARN] ADC reads 0 or 4095 — sensor may be disconnected or supply missing"));
        Serial.println(F("[WARN] Continuing to continuous monitor — check wiring"));
    } else {
        Serial.println(F("[PASS] ADC reads non-saturated value"));
    }

    Serial.println();
    Serial.println(F("[INFO] === Phase 2: Continuous monitor (Ctrl+C or reset to stop) ==="));
    Serial.println(F("[INFO] Expected: stable non-zero reading when sensor is powered"));
    Serial.println();
}

static uint32_t _lastPrintMs   = 0;
static uint32_t _sampleCount   = 0;
static uint16_t _minSeen       = 4095;
static uint16_t _maxSeen       = 0;

void loop() {
    if (millis() - _lastPrintMs < SAMPLE_INTERVAL_MS) return;
    _lastPrintMs = millis();

    uint16_t raw = (uint16_t)analogRead(PIN_CURRENT_SENSOR);
    _sampleCount++;
    if (raw < _minSeen) _minSeen = raw;
    if (raw > _maxSeen) _maxSeen = raw;

    // Reprint header periodically for readability
    if (_sampleCount % PRINT_HEADER_EVERY == 1) {
        Serial.println(F("  #     raw    min   max  uptime_s"));
        Serial.println(F("  ----  -----  ----  ----  --------"));
    }

    char buf[48];
    snprintf(buf, sizeof(buf), "  %4lu  %5u  %4u  %4u  %8lu",
             (unsigned long)_sampleCount,
             raw, _minSeen, _maxSeen,
             (unsigned long)(millis() / 1000));
    Serial.println(buf);
}

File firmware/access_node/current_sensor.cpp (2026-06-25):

#include "current_sensor.h"
#include "config.h"
#include <Arduino.h>

// Raw 12-bit ADC sample captured each loop iteration.
// Future: calibration, offset compensation, filtering, and amp conversion go here.
static uint16_t _rawAdc = 0;

void CurrentSensor::begin() {
    // GPIO 36 is input-only (ADC1 CH0); explicit INPUT mode documents intent.
    // No internal pull-up is available on input-only pins — none is needed for analog.
    pinMode(PIN_CURRENT_SENSOR, INPUT);
}

void CurrentSensor::update() {
    _rawAdc = static_cast<uint16_t>(analogRead(PIN_CURRENT_SENSOR));
}

uint16_t CurrentSensor::getRaw() {
    return _rawAdc;
}

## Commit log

2026-06-15 added v1 files
    [cable_holder.f3d, card_placeholder.f3d, card_placeholder_final.f3d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]
2026-06-17 Reorganize repo structure for GitHub
    [cable_holder.f3d, card_placeholder.f3d, card_placeholder_final.f3d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]
2026-06-25 added current sensor
    [OLEDDisplay0.96.SLDPRT, access node bottom_240626_0000.f3d, access node top v13_240626_0000.f3d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]
2026-06-30 added current sensor functionality
